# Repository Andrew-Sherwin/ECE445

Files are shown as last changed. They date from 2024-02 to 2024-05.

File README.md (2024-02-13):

# ECE445 - Senior Design Project Laboratory

# Web Page
https://courses.engr.illinois.edu/ece445/
# Official Description
Team-based design projects in various areas of electrical and computer engineering; projects are chosen by students with approval of instructor. A professionally kept lab notebook, a written report, prepared to journal publication standards, and an oral presentation required. The projects involve building and testing of the designed hardware device and a demonstration of the device is required. Course Information: 4 undergraduate hours. No graduate credit. Prerequisite: Senior Standing. Class Schedule Information: Additional Laboratory time to be arranged in 2070 ECEB.

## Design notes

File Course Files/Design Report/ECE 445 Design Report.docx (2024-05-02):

ECE 445

Senior Design Laboratory

Design Document

Automatic Humidity Sensing and Water Refilling Cool-Mist Humidifier

Team No. 11

Andrew Sherwin

(zyxie2@illinois.edu) Jalen Chen

(jalenc3@illinois.edu) Woojin Kim

(wkim51@illinois.edu)

TA: Surya Vasanth

Professor: Dr. Jonathon Schuh

February 22, 2024

## Abstract

Improper indoor humidity levels are a cause for health issues, such as dry skin or inflamed sinus passages. With the majority of humidifiers on the market being manually controlled, this causes an issue when no operator is present. A room can be under-humidified or over-humidified when there is no one to control the humidity output. As a result, we propose a cost-effective humidifier that will mitigate this problem. Concerned about the health of the operator, a cool-mist humidifier design was chosen. This humidifier communicates via 2.4GHz WIFI with multiple remote humidity sensors before determining the need to turn itself on or off. When the humidifier filter needs more water, the humidifier will activate a water valve that will irrigate the filter to the perfect amount. With all the components combined, this humidifier brings a new perspective to the humidifiers already on the market, guaranteeing the safety and comfort of the user. A truly luxurious experience.

# Introduction

## Problem and Solution

The United States Environmental Protection Agency (EPA) strongly suggests the regulation of indoor humidity to be between 30%-50%. When indoor humidity falls within these ranges, pollutants, such as chemicals, gasses, mold, and other airborne particles, are minimized in the air. This ultimately helps with allergies, respiratory illnesses, and other health issues.

To maximize the health benefits of our product, we decided to implement a cool mist humidifier. Unlike ultrasonic humidifiers and warm mist humidifiers, this product does not disperse bacterial matters, minerals, or cause your nasal passages to swell, as the US Food and Drug Administration (FDA) suggests. To further improve humidifiers on the market, our humidifier features an automatic-on function and an automatic water tank filling function. The solution has three remote humidity sensors. These sensors detect the humidity and communicate the humidity readings with the humidifier. Using the average of these readings, the humidifier decides whether it is necessary to turn itself on or off. Inside the water tank of the humidifier are two water sensors. One sensor detects whether more water is needed, while the other sensor detects when to stop automatically adding water. With all these improvements, we push out a revolutionary humidifier system onto the market that has a high level of autonomy, providing a luxurious product to the end-user.

## Visual Aid

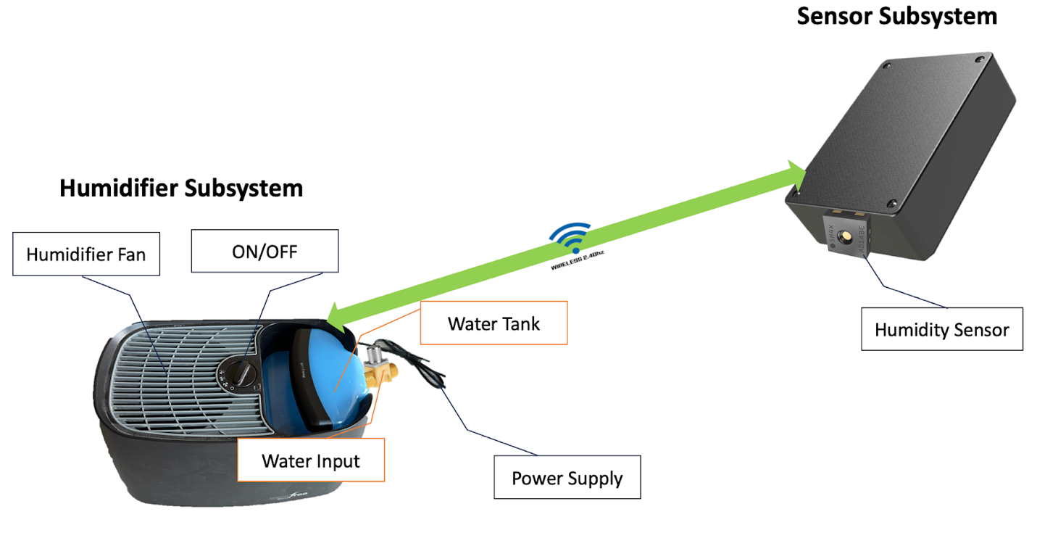
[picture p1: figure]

Figure 1: Consumer Visual Aid

The visual aid (figure 1) supports better understanding of how our product gives a solution to the suggested problem. Water supplied through water input to the tank will be brought to the filter located under the fan, then the fan will help to blow water out to the air. After the humidifier receives humidity data from the sensors, it will calculate then decide whether to turn the fan on/off.

## Physical Design

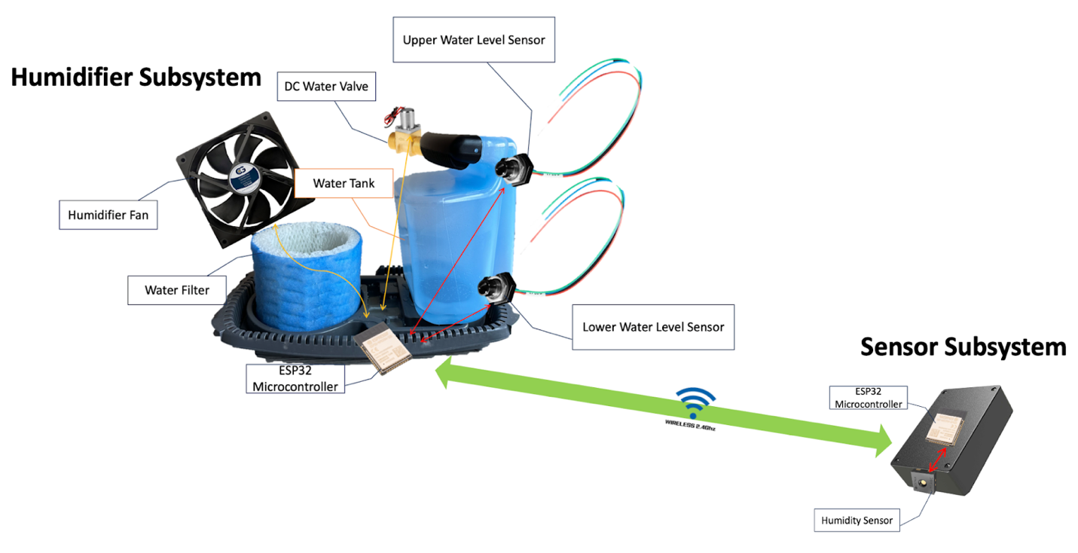
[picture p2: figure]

Figure 2 – Component Visual Aid

The physical design offers detailed information about inner components of the product. Two water-level sensors will be located vertically on the water tank to send fill/stop-fill signals to the ESP32 on the humidifier to open/close the DC water valve. It also shows the water filter that must be changed routinely to prevent potential hygiene risks. After reading humidity data, the humidity sensor will send its ESP32, then it will transmit the data to the humidifier ESP32 through 2.4GHz Wi-Fi.

## High Level Requirements

Our project would need to achieve a multitude of high-level goals to be sufficiently complete. Some goals would include:

1. The ESP32 can read data from the humidity sensor through the use. This will be done using the ESP32 microcontroller communication through the three different sensors placed around the room. The three sensors with ESP32 microcontrollers will be mounted in their individual PCBs and will communicate with the humidifier’s ESP32 microcontroller via 2.4GHz Wi-Fi with the continuous humidity readings. This will be considered as part of our total system, and the extra readings will allow us to determine the correct range at which we should turn in our humidifier fan or turn it off. This array of ESP32s will allow us to use the average humidity to detect the ideal humidity range for the fan’s on/off functionality.
2. The filter irrigation system refills the water tank with water depending on readings from two water level sensors. There will be two water level sensors, with one near the top of the tank, and one on the bottom of the tank. The bottom sensor will tell the humidifier’s ESP32 microcontroller that the tank needs to refill water. The ESP32 will activate the 12V DC water valve, allowing water to flow into the tank. Once the water hits the tip of the upper sensor, the sensor will signal the humidifier’s ESP32 to turn off the 12V DC water valve. The measured max capacity of the water tank should be 4.16 liters. The filter should absorb around 150 milliliters ± 5 milliliters. The volume of water produced, with the humidity conditions of 35% to 50% humidity, is approximately 173 milliliters per hour. This measures up to 4.16 liters every 24 hours.
3. The humidifier should be operating between 35% and 50% humidity. When the humidity falls below 35%, the humidifier will turn on. When the humidity rises above 50%, the humidifier will turn off. This is in accordance with the EPA and FDA government guidelines for indoor humidity ranges. With the remote communication between the humidity sensor’s ESP32 microcontroller and the humidifier’s ESP32 microcontroller, there is an estimated 44ns response time to the activation and the deactivation of the humidifier’s fans.

# Design

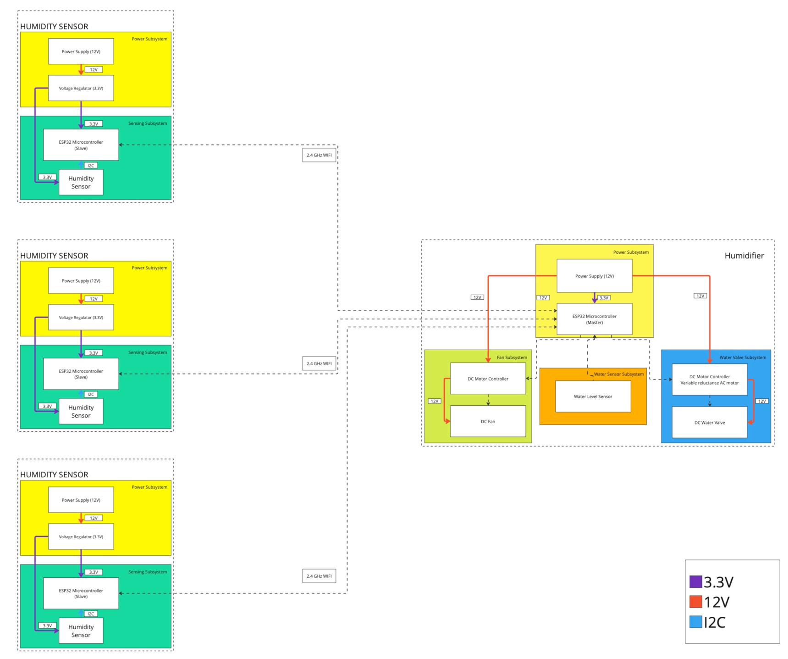
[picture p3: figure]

## Block Diagram

Figure 3 – Overall Block Diagram

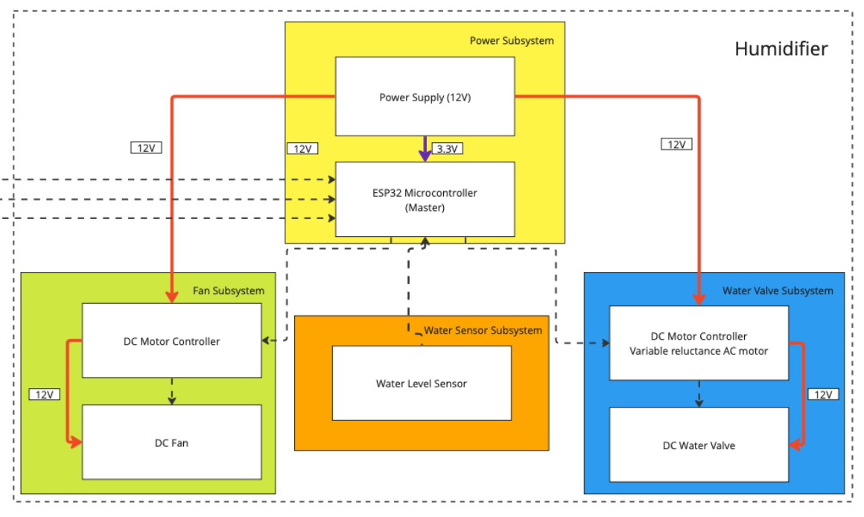
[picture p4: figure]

Figure 4 – Humidifier Subsystem Block Diagram (Close-up)

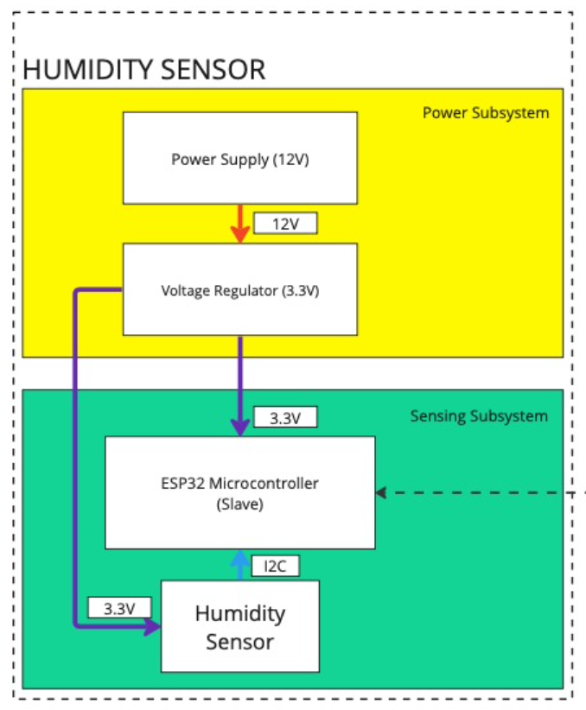
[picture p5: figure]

Figure 5 – Humidity Sensor Subsystem Block Diagram (Close-up)

Our block diagram is divided into two main parts. The Humidity Sensor subsystem and Humidifier subsystem. Within the humidifier subsystem consists of the power supply, fan, and water valve subsystems. The power supply subsystem regulates 12V input to 3.3V. This 3.3V is used to power the ESP32 microcontroller in the humidifier subsystem. The power subsystem also sends out 12V to the fan DC motor controller and the water valve DC motor controller. These DC motor controllers send 12V to their respective controlled motors. The ESP32 in the power subsystem also sends an on/off signal to the DC motor controllers. This tells the motor controllers to turn the DC motors on/off. Aside from the communication with the DC motor controllers, the humidifier subsystem’s ESP32 microcontroller also communicates via 2.4 GHz Wi-Fi with another ESP32 microcontroller in our next subsystem, the humidity sensor subsystem.

Similar to the humidifier subsystem, the humidity sensor subsystem also consists of the power subsystem. The power supply gives a 12V DC input that gets regulated to 3.3V. The 3.3V is sent to power the ESP32 in each humidifier subsystem. At every humidifier subsystem, there is a sensor subsystem. Inside the sensor subsystem are the ESP32 microcontroller and a SHT45 humidity sensor. These two devices communicate with each other in standard-mode (100kHz) I2C. Aside from communicating with the SHT45, the ESP32 also communicates with the ESP32 in the humidifier subsystem, as mentioned previously.

## Subsystem Overview / Requirements

### Humidifier Subsystem:

The humidifier subsystem controls the humidity output of the humidifier. This subsystem consists of a power subsystem that converts 110V AC to a 12V DC power. The 12V DC is sent through a voltage regulator. The output is a maintained 3.3V. This 3.3V is used to power the ESP32 microcontroller. The ESP32 microcontroller is the main microcontroller of the entire system. It communicates with the ESP32 microcontroller in the humidity sensor subsystems. In this relationship, the humidifier subsystem’s ESP32 is the master, and the humidity sensor subsystem’s ESP32s are the slaves. Based on the incoming data, the ESP32 will determine whether to turn on the humidifier’s fan or not. The motor for the fan uses 12V from the power supply and starts to rotate to run the fan. This is the main source of propulsion for our fan to produce the water into the air. When the humidifier needs more water, the ESP32 will send a signal to the water valve’s motor control system to turn on the water valve to enable the connection to the source of water, such as water pipeline at home, to fill up the 4.16-liter water tank, to wet the filter for X-seconds. This motor will be used to turn the water valve on based on the amount of water needed or shut off the flow of water once the system’s water level sensor detected liquid at the “max fill” line. The water valve’s subsystem power source will be 12 V DC coming from the barrel jack which was converted from 110V AC from the wall supply. This power was integrated throughout the whole system through 12V to the fan as well as the water valve subsystem, as both are motors that require this voltage to operate properly.

### Humidity Sensor Subsystem:

The humidity sensor subsystem detects humidity before relaying it back to the humidifier’s ESP32 microcontroller. The subsystem received power from a 110V AC to 12V DC power supply. The 12V power supply is input in a barrel jack on the PCB. The 12V is sent through a voltage regulator that maintains a 3.3V output. This 3.3V is used to power the ESP32 chip in the humidity sensor subsystem as well as the SHT45 humidity sensor. The ESP32 controls the SHT45 chip. The ESP32 in each humidity sensor subsystem serves as the master and the SHT45 is the slave. The ESP32 receives data from the SHT45 via I2C. After receiving the data, the ESP32 in the humidity sensor subsystem sends the humidity sensor’s data to the ESP32 in the humidifier subsystem. In this scenario, the ESP32 in the humidity sensor subsystem is the slave, while the ESP32 in the humidifier subsystem is the master.

### Subsystem Requirements

#### Humidifier Subsystem

i. Circuit must be powered by a 12V input source, which is then regulated at 3.3V for respective components. The microcontroller and humidity sensor takes in 3.3V. The motors will be powered by 12 V to operate at the maximum capability. We will use an oscilloscope to verify the voltage that it’s the desirable number with +/- 0.5%.
ii. ESP32 on the humidifier board must successfully receive wireless communication signals from remote ESP32 microcontrollers to obtain humidity data. Wi-Fi (2.4 GHz), electromagnetic waves travels nearly fast as speed of light, thus for 6 meters, it takes about 20 ns to reach from the humidity sensor to the humidifier, but it’s such fast compared to desirable humidifier turn on/off update frequency, the actual data transfer speed can be mitigated and only it’s enough to only verify that the humidifier receives all the data from three humidity sensors every X seconds/minutes.
iii. ESP32 should open the DC water valve when the bottom water level sensor suggests the water tank needs to be filled and close the DC water valve when the top water level sensor suggests the water level is at maximum water tank capacity. These functionalities can be verified by filling up the tank and seeing if the ESP32 on the humidifier board successfully receives signals from both sensors.
iv. ESP32 should turn on the humidifier when the average (from three sensors combined) room humidity level falls under 35% humidity and turn off the humidifier when the average room humidity level rises above 50% humidity. These functionalities can be verified if ESP32 on the humidifier board can correctly control the fan motor when it gets corresponding data from the sensor ESPs.
v. This subsystem will contribute to the overall design dictated by the high-level requirements by acting as the central subsystem that will control the main microcontroller, along with the 12V motors that drive the water supply valve and the water evaporation fan. Then the readings from the humidity sensor subsystem will communicate through 2.4 GHz Wi-Fi to our main microcontroller to tell the fan to turn on or not based on an ideal range of between 35% and 50% humidity as mentioned in the requirements. Then the microcontroller will send the data to moisture the air, with approximately 83 mililiters per hour. The water sensor will also control our water filling of up to 4.16 liters to communicate to the microcontroller whether we have reached max capacity or not.

#### RV-Table – Humidifier Subsystem

Requirements | Verification
- Provide 3.3V +/- 0.5% from an input voltage of 12V +/- 0.10% DC source - Thermal stability maintains below 120’C | - Use multimeter to test and take average voltage output over 1-hour to test stability - Monitor heat dissipation with thermal laser gun over an average of 1-hour use time, expected +/- 5’C under load
- ESP32 communication with remote sensor ESP32 utilizing 2.4GHz Wi-Fi | - Verify functionality of ESP32 Wi-Fi component by creating an access point, and accessing access point to remotely turn on LED lights - Verify communication between two ESP32 boards by sending command to turn on LED light from one ESP32 board - Verify thermal performance of ESP32 chip during operation by probing with a laser thermal gun
- ESP32 control of activation and deactivation of water valve - ESP32 control of activation and deactivation of fan | - Verify functionality of ESP32 communication with DC motor controls by sending activation signal to water valve/fan DC motor controller, and when signal is received, DC motor controllers output a lit LED light - Probe the output voltage of the DC motor controllers to make sure it is 12V +/- 0.5%
- ESP32 detects signals from two water-level sensors | - Contact/No Contact water to the water-level sensors and check through Arduino IDE to see if ESP32 receives contact/no contact signal from the two water-level sensors - Water level sensor lights up LED when in contact with water, and LED is not lit when not in contact with water

#### Humidity Sensor Subsystem

i. Circuit must be powered by a 12V input source, which is then regulated at 3.3V for respective components. We will use an oscilloscope to verify the voltage that it’s the desirable number with +/- 0.5%.
ii. ESP32 board should be able to communicate with SHT45 humidity sensor with I2C. Communication between the humidity sensor and the ESP32 on the same PCB through I2C is fast enough compared to how frequently the humidity sensor measures the humidity, which varies from 1.3 to 8.3 ms depending on the noise and energy consumption. It’s enough to verify that the ESP32 in the humidity sensor receives all the data from its sensor every X seconds/minutes.
iii. ESP32 board should be able to communicate with ESP32 in humidifier, relaying the SHT45’s data to it.
iv. ESP 32 will communicate with the humidity sensor as same frequency.
v. These functionalities can be verified by giving different humidity conditions to the humidity sensor.
vi. This subsystem will be connected to the overall design through measuring the correct humidity in a certain area, and with 3 different humidity sensors, there would be a range that is created that the central microcontroller would read because the data is being sent from each individual microcontroller per sensor through Wi-Fi, with an expected response time of 44ns through communication of the I2C protocol.

#### RV-Table – Humidity Sensor Subsystem

Requirements | Verification
- Provide 3.3V +/- 0.5% from an input voltage of 12V +/- 0.10% DC source - Thermal stability maintains below 120’C | - Use multimeter to test and take average voltage output over 1-hour to test stability - Monitor heat dissipation with thermal laser gun over an average of 1-hour use time, expected +/- 5’C under load
- ESP32 communication with humidity sensor receiving humidity data at least once in a minute - Humidity sensor measuring humidity data at least between 25% - 55% | - Verify communication between ESP32 and humidity sensor Arduino IDE by checking humidity data ESP32 receives - Compare the humidity data received by ESP32 to the commercial humidity sensor and check if the humidity is within +/- 3% - Make the air dry/moist to see if the sensor can measure humidity between 25% - 55% - Compare humidity reading with reference humidity reader

### Tolerance Analysis / Potential Error

A significant aspect of our design that could pose a major risk to our project is the strength in the Wi-Fi signals being used to communicate between the sensors. Our project majorly depends on multiple microcontrollers in multiple sensors across many different areas in a room using Wi-Fi to connect to the central microcontroller. If any of these signals were interrupted, it would cause an impactful change in the way our system functions. Our completion of the project would be deemed nearly impossible without a proper wireless communication protocol, whether it be Bluetooth or Wi-Fi. For example, Wi-Fi is essentially a EM wave that operates through the medium of air containing the data we need, and can be more accurately defined using sets of Maxwell’s equations, most notably the Helmholtz equation that gives us the equation:

E∇^2 +(E(k^2 ))/(n^2)=0

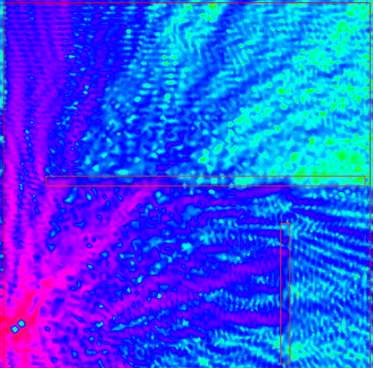
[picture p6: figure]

which are the electric fields mapped based on the angular wavenumber k and the material index n (Hecht). Below is a sample model taken from a reference site, Freefem, that will model what the signals will look like at a certain point in the area.

Figure 6: Signal Strength Plot

In figure 6, it shows a point where the electromagnetic signal is being read and the relative strength of it compared to the waves across the rest of the room. This will be how our sensors operate, with the signals being the strongest at receiving/interacting ends and having the most possible interference in between transmissions. In our respective setup, we will use example calculations to model this. For example, wavelengths of our WiFi signals which will be used to communicate are approximately 12 centimeters give or take, given a 2.4 GHz WiFi default in our system. So the angular wavenumber:

k= 2π/λ

which given our lambda wavelength value, will give us 0.52 (rad)/(cm) . As for material index n, the value should just be the material index of air, which is the constant of 1. Given this, we have taken E as an average of 50 V/m for an electric field value inside a home. So our electric field gradient value will be equal to:

50× 0.52^2 =13.52 v/(m^3)

This value will indicate the electric field strength in a specific area, which matches our signal strength plot example above. The field will obviously be different at random areas in the room due to interference from various radio sources, such as other electronics or even your own body as a source. To mitigate this issue, we will test if signals are possible to fully transmit all necessary data given multiple sensor points. If information is not fully available because of the strength or interference of other signals, we will act to measure where exactly the field is weak and create optimal positions for our sensors to generate the most effective waves. Another solution to this problem could be examining the materials that have interference potential such as metal or concrete, and either removing or replacing those materials in highly affected areas. Trade-offs to our solutions would be that optimal positions for signal strength might not be optimal positions for humidifier strength. For example, if our sensors were positioned at 30, 45 and 180 degrees in a circular pattern in a rectangular room, there would be nearly no sensing of the humidity in the 270 degrees area. This would be sub-optimal because we would essentially have 2 sensors instead of 3 near evenly spaced ones, despite the connection being very reliable.

# Cost and Schedule

## Cost Analysis

### Parts and Materials

In our project, we have an estimated breakdown of the parts and materials needed in our final product. The part name, part number, number required per system, and the cost per system is provided. Each system consists of one humidifier subsystem, as well as three humidity sensor subsystems.

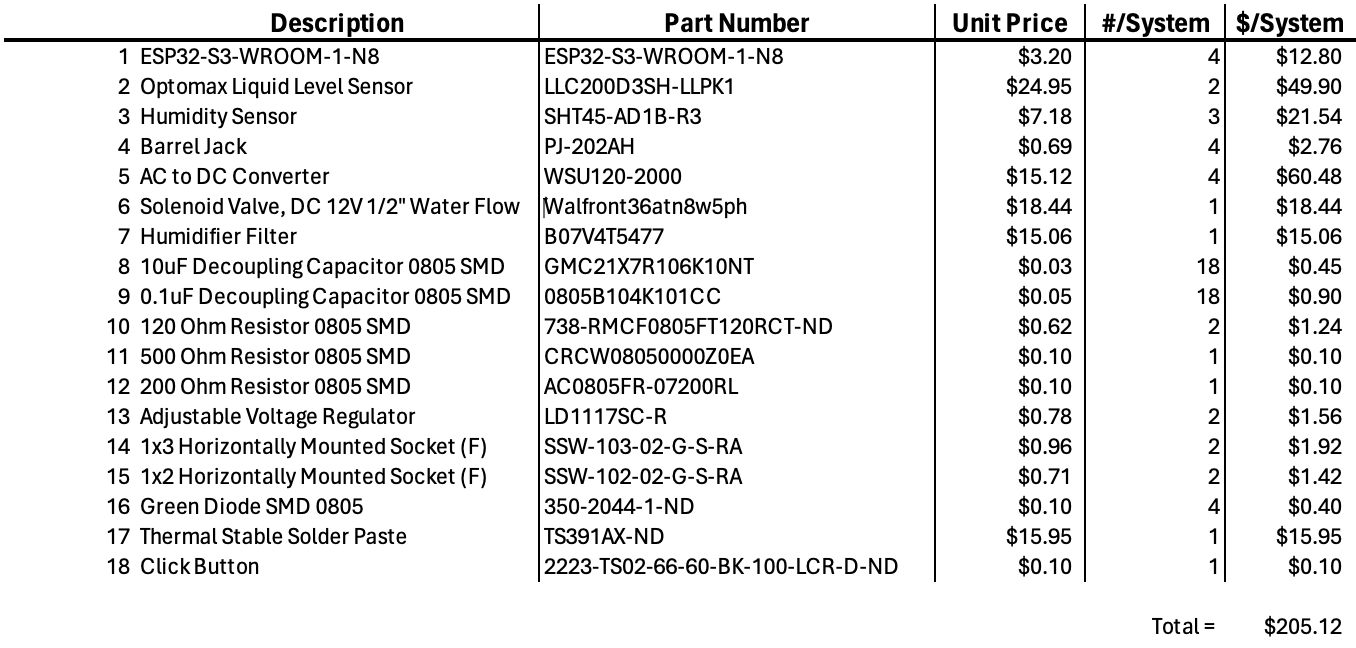
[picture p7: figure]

Table 1 – Estimated Product Cost

#### Hours of Development and Labor

Our project consists of multiple roles that need to be completed. We have an estimated 373.5 hours total between three group members on the project. Below is a breakdown of our estimated hours per person on each category.

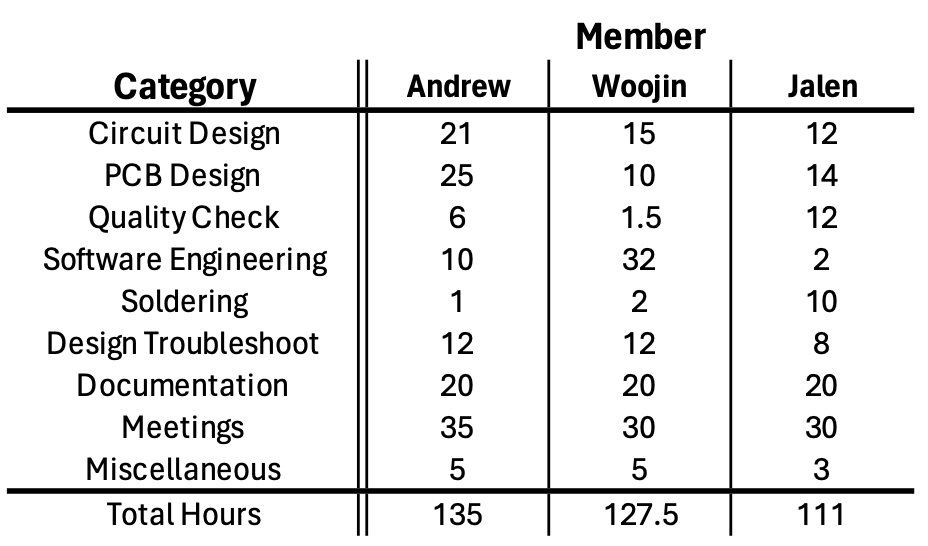
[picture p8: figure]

Table 2 – Estimated Hours

With mixed electrical engineers and computer engineers in our group, we all have different hourly wages. Using the average UIUC ECE computer engineering published salary in 2021-2022 ($109,176.00), using 2080 work hours in a work year, we can expect an average hourly salary of $52.49.

($109,176.00)/(2080 hours)=$52.49 per hour

(135hours+127.5hours+111hours)× $52.49=$19,605.02

Summing up the total hours in the table above and multiplying it by the average salary, we get the total cost for labor to be: $19,605.02 for this project.

Aside from our own hours of labor, the machine shop estimates 7 hours of work to modify our humidifier with some parts included in Table 1. The machine-shop technician’s hourly cost is not public, so we will not include the cost in the total cost of development above.

## Schedule

1. Week 6 (02/19)
  a. Design Document
  b. Proposal Revision
  c. I2C communication between ESP32 and Humidifier
  d. 2.4GHz Wi-Fi communication between two ESP32 boards
  e. Give humidifier to machine shop
  f. Begin PCB Design for humidity sensor subsystem
2. Week 7 (02/26)
  a. Design PCB for humidity sensor subsystem
  b. Debug potential issues with PCB
  c. Interface water-level sensor with humidifier ESP32
  d. Control 12V DC water valve with ESP32
  e. Control humidifier fan with ESP32
  f. Potentially place first PCB order (individual)
3. Week 8 (03/04)
  a. Order PCB for humidity sensor subsystem (with class)
  b. Order electronic water valve
  c. Order second Adafruit water level sensor
  d. Design PCB for humidifier subsystem
  e. Debug potential issues with PCB
  f. Potentially send humidity sensor subsystem PCB to machine shop
  g. Potentially solder SMD components on humidity sensor PCB
4. Week 9 (03/11)
  a. Finish humidifier subsystem PCB design
5. Week 10 (03/18)
  a. Solder PCB for humidity sensor PCB
  b. Send humidity sensor PCB to machine shop
  c. Order PCB for humidifier
6. Week 11 (03/25)
  a. Reorder revised PCBs
  b. Solder PCB for humidifier subsystem
  c. Potentially put together humidifier
7. Week 12 (04/01)
  a. Begin writing final paper
  b. Finalize PCBs
  c. Send remaining updates to machine shop
8. Week 13 (04/08)
  a. Finalize product for presentation
  b. Begin writing final paper
  c. Last minute debugging
9. Week 14 (04/15)
  a. Team contract fulfillment
  b. Mock demonstration
  c. Finalize product for presentation
  d. Continue writing final paper
10. Week 15 (04/22)
  a. Final Demonstration
  b. Mock Presentation
  c. Final Presentation Preparation
  d. Continue writing final paper
11. Week 16 (04/29)
  a. Final Presentation Preparation
  b. Final Presentation
  c. Final Papers
  d. Lab Notebook
  e. Lab Checkout

# Ethics and Safety

For our initial examination of ethics, we were able to justify our project using the IEEE code of ethics. As students and soon-to-be workers, we know that whatever we do will have an impact on the world, primarily through the products and services we work on. Therefore, we must make sure to set some ethical guidelines that match with the code.

## Ethics

i. To uphold the highest standards of integrity, responsible behavior, and ethical conduct in professional activities. (IEEE, 2020)

a. We will keep an open-minded state to each other's opinions. Utilizing everyone’s opinions, we will try to find the most ideal solution to our problems.

b. We will keep the integrity of our research to the highest degree. All data collected will be the truthful original and will not be “tuned” in any way.

c. We will keep the safety of our members and those working around us to the utmost highest standard.

d. We will adhere to the rules and regulations of the University of Illinois and ECE445’s lab conduct rules.

e. Constructive advice and criticisms will be accepted, and any forms of bribery will not be tolerated.

ii. To treat all persons fairly and with respect, to not engage in harassment or discrimination, and to avoid injuring others. (IEEE, 2020)

a. We will treat all members within and outside our group with respect on physical and non-physical standpoints.

b. Sexual harassment is not tolerated and will be reported to appropriate parties.

iii. To strive to ensure this code is upheld by colleagues and co-workers. (IEEE, 2020)

a. We will strive to uphold this code of conduct provided from IEEE and in our team contract. Any behavior outside the rules will be reported to the correct authorities.

iv. To seek, accept, and offer honest criticism of technical work, to acknowledge and correct errors, to be honest and realistic in stating claims or estimates based on available data … (IEEE, 2020)

a. A central ethical concern includes directly impacting humans as a first resort without being able to test otherwise. For example, for most scientific products, humans are the final stage of a trial in a product because all previous stages have been cleared or given approval through uses of inanimate objects or lab animals. Our problem is generally a comfort-based one, and so the general ethical concern would be the first stage exposure to humans since there would not be a test trial. If our main issue is comfort, we will never know how it feels until actual humans have tested it. Therefore, as one of the IEEE Code of Ethics indicates, we will seek and accept any technical criticisms from TA, instructors, and machine shop, be realistic and responsible to revise the problem until we reach agreement. On top of that we will measure the humidity carefully and regulate with the correct amounts of moisture, making sure that we only deviate from the average quantity only once we have received indication that it is comfortable.

## Safety

In this section, we consider every type of the most common situations that could occur when using our automatic humidifier product.

  i. A safety concern would be the wall plug power. This is 120 V AC power typically, and so to prevent electrocution and shock issues, we would need to be aware of our surroundings and to connect the plug into the wall without any external connections to the outlet interrupting it in any way, such as holding loose wires or the metal section of the plug when you are plugging it into the wall.
  ii. A safety concern is the issue of potential bacteria and mold. Our automatic humidifier should get rid of this, but this issue could severely impact the humidifier if there turns out to be traces of something contagious that can be widespread with the device. The dangers of something airborne that could get into your lungs would be catastrophic if not regulated correctly.
  iii. Another possible safety issue could be the moving parts of a fan that could injure you if you try to touch the mechanical components. The fan’s motor will likely be insulated from external touch, but there is always a chance that something breaks and another chance that the moving part accidentally comes in contact with someone’s finger or something easily mistouched, leading to a higher chance of injury.
  iv. A common matter that arises as well is if there is a connected cable that meets water. Our humidifier will likely be powered through a wired connection, and any water that comes into contact either from the humidifier or an external water source will damage the system, or even worse, cause physical harm to someone. This safety issue would need to be fixed through epoxy or some type of non-porous material insulating the device and its connections.
v. Dangerous chemicals are a final hazard that could be caused intentionally or by accident. Chemicals could be an issue if put inside the supply which normally contains water. If a dangerous fluid was put in the supply on purpose, then the humidifier might act as normal, sensing the humidity levels and then dispersing a life-threatening liquid instead of water. This would cause great harm and even possibly death if misused, so it is of utmost importance that the person using the device is careful and is sensible. Otherwise, the designers are not subject to responsibility and take no claim in the misuse of the product, which in that case, the user should refer to the instructions provided.

# References

[1] Hecht, F. (n.d.). WiFi Propagation . WIFI propagation. https://doc.freefem.org/tutorials/wifiPropagation.html
[2] Marwell, M. (2018, August 9). Issues with the I²C (inter-ic) bus and how to solve them. DigiKey. https://www.digikey.com/en/articles/issues-with-the-i2c-bus-and-how-to-solve-them
[3] Sensirion. (2023). SHT4x 4th Generation, High-Accuracy, Ultra-Low-Power, 16-bit Relative Humidity and Temperature Sensor. In Sensirion Official Documentation (Issue 6). Sensirion.
[4] United States Environmental Protection Agency. (2014, August 28). Care for your air: A guide to indoor air quality. US EPA. https://www.epa.gov/indoor-air-quality-iaq/care-your-air-guide-indoor-air-quality
[5] Espressif. (2023). ESP32-S3-WROOM-1 ESP32-S3-WROOM-1U Datasheet. Espressif. https://www.espressif.com/sites/default/files/documentation/esp32-s3-wroom-1_wroom-1u_datasheet_en.pdf
[6] Metageek. (2024). Wi-Fi and non wi-fi interference. MetaGeek. https://www.metageek.com/training/resources/wifi-and-non-wifi-interference/
[7] Arundel, A. V., Sterling, E. M., Biggin, J. H., & Sterling, T. D. (1986). Indirect health effects of relative humidity in indoor environments. Environmental Health Perspectives, 65, 351–361. https://doi.org/10.1289/ehp.8665351
[8] Perrone, V., Veronesi, C., Giacomini, E., Citraro, R., Dell’Orco, S., Lena, F., Paciello, A., Resta, A. M., Nica, M., Ritrovato, D., & Degli Esposti, L. (2022). The epidemiology, treatment patterns and economic burden of different phenotypes of multiple sclerosis in Italy: Relapsing-Remitting multiple sclerosis and secondary progressive multiple sclerosis. Clinical Epidemiology, 14, 1327–1337. https://doi.org/10.2147/CLEP.S376005
[9] IEEE. (2020). IEEE code of ethics. IEEE Code of Ethics. https://www.ieee.org/about/corporate/governance/p7-8.html
[10] SENSIRION. (2023, January). 4th Generation, High-Accuracy, Ultra-Low-Power, 16-bit Relative Humidity and Temperature Sensor. Cdn-Shop.Adafruit.Com. https://cdn-shop.adafruit.com/product-files/5665/5665_Datasheet_SHT4x.pdf
[11] University of Illinois. (2022). Salary averages. UIUC. https://ece.illinois.edu/admissions/why-ece/salary-averages

2 Automatic Humidity Sensing and Water Refilling Cool-Mist Humidifier

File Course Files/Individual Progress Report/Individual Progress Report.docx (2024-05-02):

ECE 445

Senior Design Laboratory

Individual Progress Report

Automatic Humidity Sensing and Water Refilling Cool-Mist Humidifier

Team No. 11

Andrew Sherwin

(zyxie2@illinois.edu)

TA: Surya Vasanth

Professor: Dr. Jonathon Schuh

March 27, 2024

# Abstract

This paper is an individual progress report for the work done by Andrew Sherwin as an individual in ECE445 – Senior Design Laboratory. Andrew Sherwin is the active member and the team manager in Team 11. The team consists of members: Andrew Sherwin, Woojin Kim, and Jalen Chen. In Spring 2024, Team 11 is designing an Automatic Humidity Sensing and Water Refilling Cool-Mist Humidifier. The humidifier can turn on automatically in relation to the detected humidity and temperature values, as well as refill its water tank depending on the water level value. Andrew Sherwin is responsible for the team’s project progression, as well as maintaining a checklist all goals are reached at an appropriate time. He is also responsible for the selection of components and design of the PCB. Aside from that, he also helps with the software design for the control of the microcontroller. Andrew Sherwin is also the representative for the team during communication with the course staff, Surya Vasanth, and the machine shop.

# Introduction

## Problem

In September 203, the United States Environmental Protection Agency (EPA) [1] released an article regarding indoor humidity recommendations. The EPA suggests indoor humidity to range between 30 and 50 percent. Though a lower humidity decreases the presence of pests, such as mites, it allows for airborne particles and pollutants to freely travel around. A higher humidity above 50 percent leads to a higher percentage of mold growth. As a result, it is critical to keep indoor humidity between 30 to 50 percent, at room temperature.

The majority of cost effect humidifiers in the market are manually controlled. They do not feature an automatic on-off feature. When the humidifier user is not at home, the indoor humidity can pass 50% humidity when the humidifier is left on. Similarly, the indoor humidity can drop below 30% when the humidifier is left off. In addition, all humidifiers in the market require manual water filling by the user. Our humidifier strives to solve the issues above to guarantee safe and healthy indoor humidity for the user.

## Solution

To resolve the issue of a manual humidifier, our design proposes a solution that can be incorporated into the majority of manual consumer humidifiers on the market. We will have a system that has three remote humidity sensors that relay humidity data to the base system at the humidifier. The humidifier will plug into the base system, and the base system will plug into the wall. Based on the humidity sensor readings, the base system will use an in-house developed algorithm to turn on or off the humidifier. Furthermore, the humidifier’s water tank will be connected to a DC water valve. Depending on the water level sensor’s readings, the base system will activate or deactivate the water valve to refill the humidifier’s water tank. The laissez-faire approach to our humidifier’s function generates a luxurious and revolutionary product for the market with high autonomy.

## Team Responsibilities (non-design)

Andrew Sherwin is responsible for managing the team and giving the team a direction in design philosophy and written reports. Andrew is also responsible for the communication between the team and the course staff, as well as the machine shop. Andrew has set out specific goals to be accomplished each week in the 16-week semester. Every week, Andrew actively communicates with the team members in-person and on the private Discord server about goals and requirements to be met at the end of the week. While Andrew participates in the written reports, he also proofreads and formats the written reports for the course. Andrew leads the team on the weekly meetings with the TA, Surya Vasanth, and updates the Machine Shop bi-monthly about the team’s project progression.

## Sensor Subsystem Responsibility

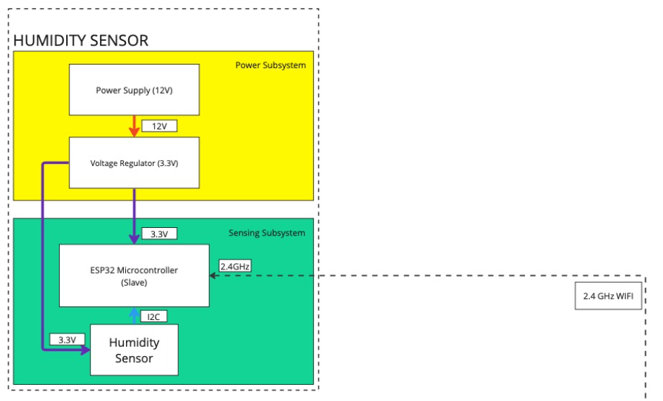
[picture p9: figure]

In figure 1, the sensor subsystem, Andrew Sherwin was responsible for choosing the components and designing the PCB for the subsystem. Andrew has been cooperating with Woojin in the software design of the humidity sensor subsystem. The ESP32 has to read the data of the humidity sensor and relay it to the ESP32 at the base system in the humidifier subsystem. In the hardware design, Andrew has been picking components suitable for this subsystem, while communicating with Jalen regarding the power subsystem in figure 1. With his prior experience in PCB design, Andrew is also responsible for drawing the schematic and PCB layout in KiCAD, whilst Jalen proofreads the system design.

Figure 1 – Sensor Subsystem Block Diagram

## Humidifier Subsystem Responsibility

Similar to the sensor subsystem’s responsibilities, Andrew has been working with Woojin on the software of the ESP32. Andrew developed a software design for an access point that Woojin uses for the ESP32 communication. Andrew has also developed a program where LED lights can be controlled using a phone on the ESP32’s MAC address. The webserver also shows a live readout of the LED values. On the hardware side, Andrew has been working on picking components suitable for the humidifier subsystem in figure 2. For example, Andrew selected the water level sensors, electrical relays, and numerous other parts for this subsystem. Similar to the sensor subsystem, Andrew also designed the PCB schematic and layout of the humidifier subsystem. Jalen has worked with Andrew by discussing on the choice of parts and proofreading the KiCAD schematic.

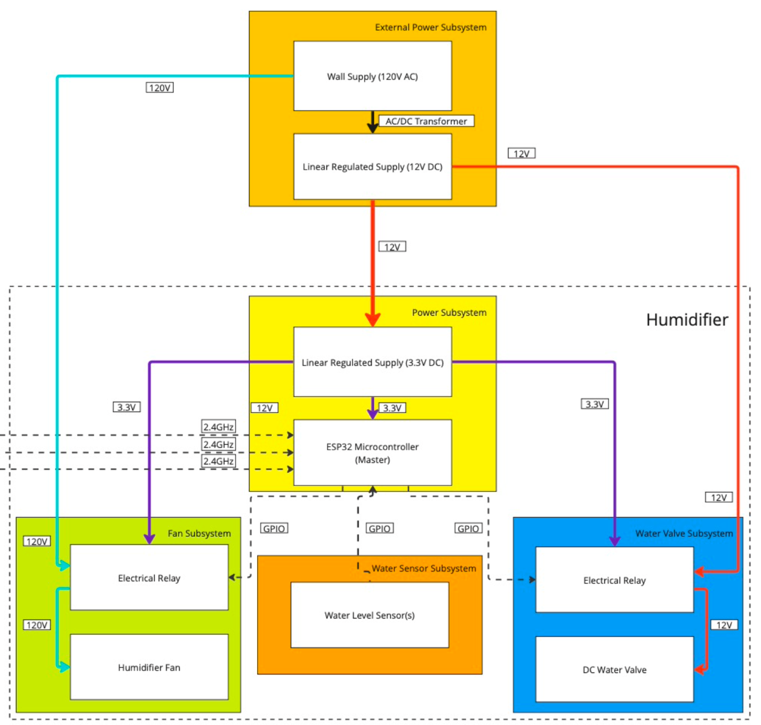
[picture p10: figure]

Figure 2 – Humidifier Subsystem Block Diagram

# Individual Design

## ESP32 Design

In the development phase, we used an ESP32-S3 WROOM1 development board. This board uses Micro-USB Type-B ports to upload the programs to the microcontroller. The Micro-USB sends UART data to a UART communication chip, U4 in figure 3, to communicate with the ESP32. When programming, the BOOT button had to have a logic of 0 to load the button, hence the importance of the BOOT button. The RESET button loads and starts the program in the microcontroller. It is important to replicate these parts of the development board’s design in our PCB design, as they are critical for the functionality of the microcontroller. It is also important to have Zener diodes to act as reference voltages and to prevent static discharges from affecting other components. We also have some 0-ohm resistors for testing. The design also includes an alternative way to program the board, using just the Micro-USB. This is a secondary way just in case if the USB to UART bridge does not work. The completed schematic, with the humidity sensor can be seen in figure 3.

Figure 3 – Sensor Subsystem Schematic

## Sensor Subsystem Progress

Figure 3 shows the KiCAD design for the sensor subsystem designed by Andrew Sherwin. Most of the diagram consists of the ESP32 circuit, with pins 12 and 17 being the input of the SHT45 humidity sensor (U3). The SHT45 communicates in I2C, which means it needs SDA and SCL pins. The SHT45 has a 100nF decoupling capacitor, as specified by the Sensirion documentation, as well as one 10k ohm resistor for SDA and SCL respectively. The SHT45 sensor will be mounted on the rear of the PCB, with the ESP32 and all other components being on the front. This will isolate the humidity sensor, thus, making the readings more accurate.

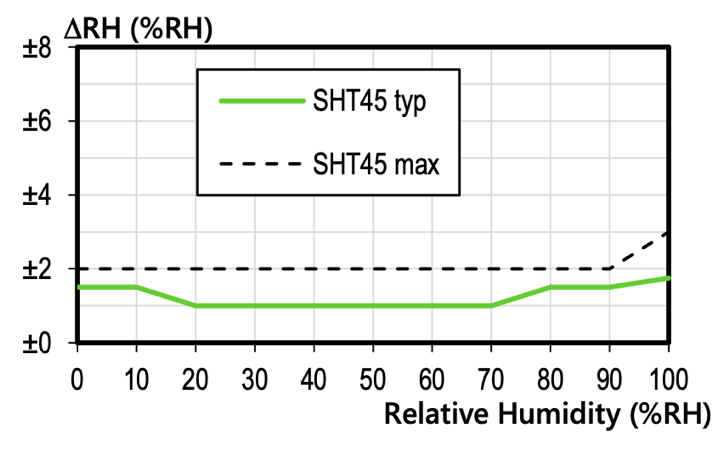
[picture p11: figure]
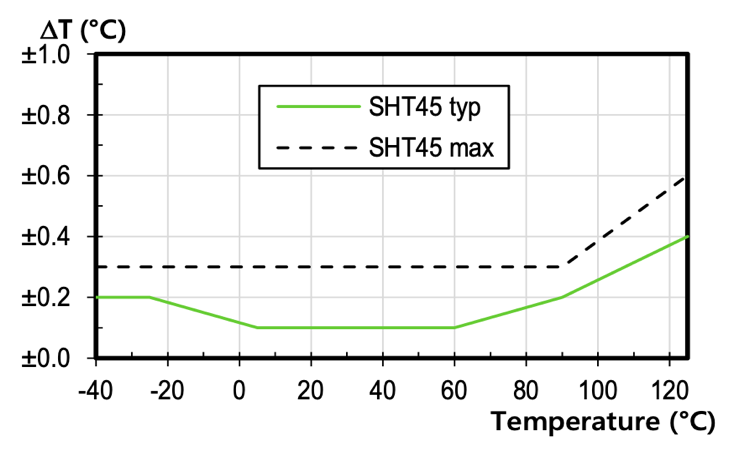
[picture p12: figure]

The SHT45 was determined to be used due to its accurate temperature and humidity measurements. Whereas most other sensing devices has an error range or 2%, the SHT45 has only an error range of 1% in the indoor temperature range around 23ºC, as seen in figure 4.

Figure 4 – SHT45 Reading Accuracy Table

## Humidifier Subsystem Progress

Originally, we planned the ESP32 microcontroller in the humidifier subsystem to be communicating with two motor controllers. The first which controls the DC water valve, and the other that controls the humidifier fan.

As the machine shop is not creating a ground-up humidifier for the team, taking apart and controlling the humidifier’s fan proved difficult. As a result, the alternative solution was to control the humidifier with a relay. The relay will work like a light switch that is controlled by the ESP32. The switch will allow 120V AC to reach the humidifier. A sample diagram is shown in figure 5 below.

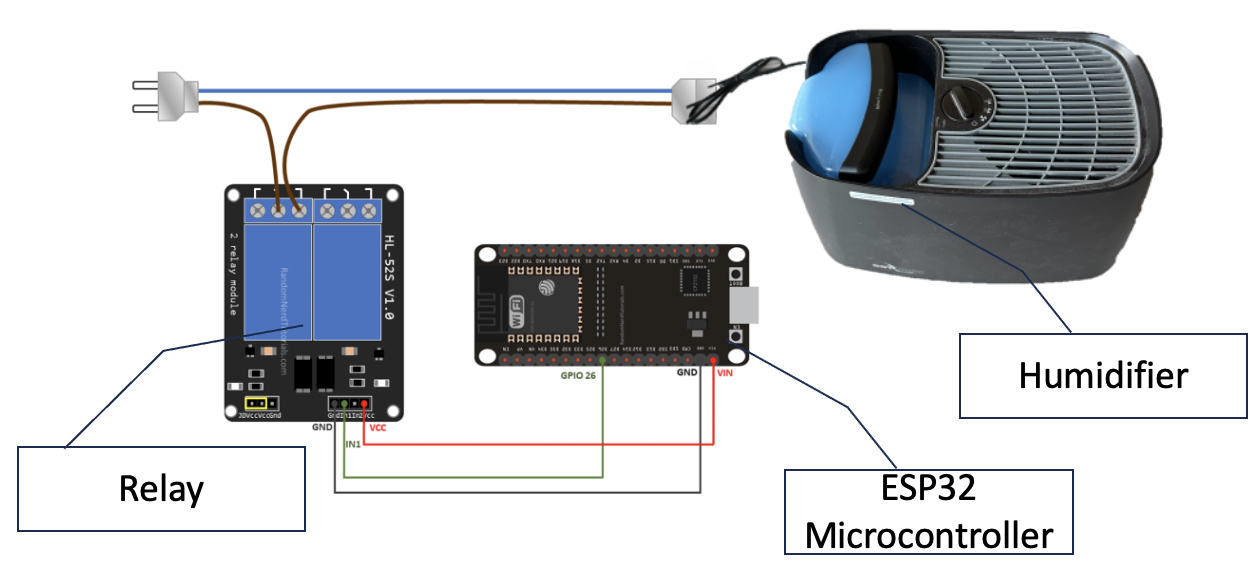
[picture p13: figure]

Figure 5 – Relay Diagram

Similarly, it was discovered that the original water valve that the team intended to use did not work unless there was active pressure on it. This will normally work when connected to a building’s water supply. However, for our demonstration, there will be no water pressure. As a result, we had to change parts. The pervious water valve featured a stepper motor. This required a motor controller. However, the new one features only a simple DC motor, which did not require a DC motor. As a result, we can simply use another relay to control the water valve, with a setup like that of figure 5.

When designing the schematic in figure 6, most of the schematic was a carry-over from the ESP32 schematic. The main difference in figure 6 was the inclusion of the two relays. A design choice was made during the design of the relay schematic to include a kick-back diode and an optocoupler. The kick-back diode helps prevent voltage spikes from going to the ESP32 when the circuit is turned off. The optocoupler helps isolate the ESP32 from the higher voltage components in the relay. This further prevents noise and voltage spikes from destroying the ESP32.

Figure 6 – Sensor Subsystem Schematic

# Individual Verification

## ESP32 Progress

Andrew was the first team member to work on the ESP32. He set up the Arduino IDE and installed the necessary libraries for programming the ESP32. The first basic test that Andrew did was turning LED lights on and off. Through a button input to a GPIO pin, depending on the logical input, the ESP32 will match the input signal to another output GPIO with an LED. For example, then the button is pressed, the LED will turn on, and the opposite vice-versa.

After confirming the functionality of the setup, Andrew worked on setting up an access point for the ESP32. He planned to connect to it with his personal device. On this access point, after accessing the MAC address on the personal device, he created a HTML code that shows the live output of the LED mentioned in the previous paragraph. When the LED is on, the webpage will display “ON”, and “OFF” when the LED is off. This will be the starting point of being able to read the humidity sensor data on a personal device, which the team plans to accomplish later as a bonus.

## Sensor Subsystem Progress

Coupled with the ESP32 progress, Andrew has aided Woojin in the verification of the software development in the sensor subsystem. Andrew helped troubleshoot the code in the Arduino IDE for the SHT45 humidity sensor using modular and system testing methods. Originally, the ESP32 was not getting an input from the SHT45. The troubleshooting method was to first probe the ESP32’s SDA output and the ESP32’s SCL clock speed. Using an oscilloscope, Andrew verified that the output message was correct for the ESP32’s master instructions. Following, the oscilloscope was used again to probe the clock speed. The error was simple, the clock speed was incorrect. The ESP32 was using I2C at the “Fast-Mode”, transferring data at 400k bits/s, while the SHT45 was supposed to be reading and sending data at 100k bits/s. The SHT45 was not able to receive the ESP32’s instructions, due to the ESP32 sending data at a 4 times higher frequency than the SHT45 was reading.

Verification of the PCB that was placed on the first round will be done when the part for the PCB arrives. The PCB has test-point pads that provides easy access for probing signals with an oscilloscope. This was done during the design process. On the final PCB, the test-points will be removed so that the final product will be cleaned up.

## Humidifier Subsystem Progress

In the humidifier subsystem schematic and PCB design, 1x1 connectors are included for trouble shooting. The 1x1 connectors will make it easy to probe the oscilloscope on the section. Furthermore, there are numerous 0-ohm resistors throughout the schematic and PCB. The reason for these resistors is so that jumper wires can be soldered for testing if the original traces were not correct. This is highly suggested for the UART TX and RX connections. The use of the 0-ohm resistor pads can be seen in figure 6.

The new 12V DC water valve operates as a plunger. When it receives 12V power, there will be 0.48A of current going through the water valve solenoid. This results in a magnetic field, which pulls the plunger up, allowing water to pass through the valve. Andrew did some modular tests on the percentage chance the valve will activate at the lower voltage. Based on 100 trials for each 0.2V increment from 10V, it can be concluded that there is 0% chance that the valve will operate in the range 0V to 11.4V. There is a 39% chance of the valve activating at 11.6V, 94% chance at 11.8V, and 100% chance at voltages 11.9V and greater. The with 1100 trials performed, and 1100 data collected, Andrew is confident that as long as the relay supplies 12V, with a 0.2V error range, the valve will function for our design. Through this verification, and by disassembling the valve to understand the inner workings, Andrew brought up the suggestion to use a valve rated for a higher pressure should be considered for the project, as this valve does not rely on input pressure. This will guarantee a better water seal within the valve.

The PCB testing will be similar to the process mentioned in the Sensor Subsystem Progress Verification section. Currently, the PCB has not arrived yet, but there are test-points for probing the PCB, if needed, with an oscilloscope to decipher the signals. The testing will be done within 3 days of the completion of the component soldering onto the PCB. This will allow the team to place a new PCB order if needed for revisions.

# Conclusion

## Self-Assessment

The workload for Andrew Sherwin in ECE445 is a bit higher than his peers in his team. This is expected as he is managing the direction of the project and is the representative for the team.

Andrew communicates in-person and on Discord with the team to get updates and progress on the project. He makes sure that all goals are met on time, or ahead of time. If there are any issues with parts, he quickly organizes meetings and finds solutions for troubleshooting. As the representative of the team, Andrew communicates with the TA, Surya Vasanth, and the machine shop regarding project updates and parts to order. Each week, Andrew sets out new goals and plans for the team to meet, in accordance with the set schedule. Andrew makes sure that each milestone is met at, or ahead of a certain date.

As the bridge between the software engineer, Woojin, and the hardware-power engineer, Jalen, Andrew is involved in both parts of the project. With his prior experience, he also is the designer for the PCB schematic and layout. He helps both members troubleshoot potential issues and helps clarify unclear project goals.

With Andrew’s planning, the team is currently ahead of schedule. During the first round of PCB orders, Andrew placed an order for the Sensor Subsystem’s PCB. During the second round of PCB orders, Andrew placed an order for the Humidifier Subsystem’s PCB. On the week of the third round of PCB orders, with the help of Andrew’s original ESP32 research, Woojin has updated the team that he is able to send and receive humidity data from one ESP32 to another ESP32 using 2.4GHz Wi-Fi. With the above finished, the team is 2 weeks ahead of the original conservative time schedule.

## Future Plans

Currently, the team is waiting on parts from Digikey, so that the PCBs can receive their components. Jalen will be soldering the PCB with the later arriving components, and Andrew will be working with Woojin on programming and troubleshooting any potential errors from the PCBs.

Andrew will also be working with Jalen on the wiring of the humidity subsystem. The team will need to purchase a 120V AC to 12V DC transformer assembly. Currently, Andrew has his sights set on the Mean Well USA EPS-15-12 AC/DC converter. This will output a 12V DC line that will go to power the PCB via a barrel jack connector.

If the PCBs do not need revisions, the team will work on a webpage to view the live humidity sensor readings from the SHT45 sensors. This will be a bonus to our project if everything is completed early. However, this plan will only commence if the original design is indeed functional.

As a team, Team 11 will continue to follow all IEEE Code of Ethics outlined in section 7.8. We will uphold the highest integrity and responsible behavior when designing our product. Working as a team, we will treat one another with respect, and will not engage in any form of discrimination. We will strive to uphold the IEEE Code of Ethics throughout the period working on the Automatic Humidity Sensing and Water Refilling Cool-Mist Humidifier.

# References

[1] Environmental Protection Agency, “Care for your air: A guide to indoor air quality,” US EPA, Aug. 07, 2023. https://www.epa.gov/indoor-air-quality-iaq/care-your-air-guide-indoor-air-quality (accessed Mar. 25, 2024).

[2] Sensirion, “Datasheet -SHT4x,” Sensirion, Aug. 2023. https://sensirion.com/media/documents/33FD6951/6555C40E/Sensirion_Datasheet_SHT4x.pdf (accessed Mar. 26, 2024).

[3] A. Sherwin, ECE445 Team 11 - Sensor Subsystem Schematic. 2024.

[4] A. Sherwin, ECE445 Team 11 - Humidifier Subsystem Schematic. 2024.

[5] Espressif, “ESP32-S3-WROOM-1 ESP32-S3-WROOM-1U Datasheet,” Espressif, 2023. https://www.espressif.com/sites/default/files/documentation/esp32-s3-wroom-1_wroom-1u_datasheet_en.pdf (accessed Mar. 26, 2024).

[6] IEEE, “IEEE Code of Ethics,” IEEE Code of Ethics, Jun. 2020. https://www.ieee.org/about/corporate/governance/p7-8.html (accessed Mar. 26, 2024).

[7] Espressif, “sch_esp32-s3-devkitc-1_v1_20210,” Espressif, Apr. 13, 2022. https://dl.espressif.com/dl/schematics/SCH_ESP32-S3-DevKitC-1_V1.1_20220413.pdf (accessed Mar. 26, 2024).

[8] A. Sherwin, Sensor Subsystem Block Diagram. 2024.

[9] A. Sherwin, Humidity Subsystem Block Diagram. 2024.

1 Individual Progress Report

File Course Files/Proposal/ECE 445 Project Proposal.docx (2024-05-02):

ECE 445

Senior Design Laboratory

Project Proposal

Automatic Humidity Sensing and Water Refilling Cool-Mist Humidifier

Team No. 11

Andrew Sherwin

(zyxie2@illinois.edu) Jalen Chen

(jalenc3@illinois.edu) Woojin Kim

(wkim51@illinois.edu)

TA: Surya Vasanth

Professor: Dr. Jonathon Schuh

February 08, 2024

## Abstract

Improper indoor humidity levels are a cause for health issues, such as dry skin or inflamed sinus passages. With the majority of humidifiers on the market being manually controlled, this causes an issue when no operator is present. A room can be under-humidified or over-humidified when there is no one to control the humidity output. As a result, we propose a cost-effective humidifier that will mitigate this problem. Concerned about the health of the operator, a cool-mist humidifier design was chosen. This humidifier communicates via 2.4GHz WIFI with multiple remote humidity sensors before determining the need to turn itself on or off. When the humidifier filter needs more water, the humidifier will activate a water valve that will irrigate the filter to the perfect amount. With all the components combined, this humidifier brings a new perspective to the humidifiers already on the market, guaranteeing the safety and comfort of the user. A truly luxurious experience.

# Introduction

## Problem and Solution

The United States Environmental Protection Agency (EPA) strongly suggests the regulation of indoor humidity to be between 30%-50%. When indoor humidity falls within these ranges, pollutants, such as chemicals, gasses, mold, and other airborne particles, are minimized in the air. This ultimately helps with allergies, respiratory illnesses, and other health issues.

To maximize the health benefits of our product, we decided to implement a cool mist humidifier. Unlike ultrasonic humidifiers and warm mist humidifiers, this product does not disperse bacterial matters, minerals, or cause your nasal passages, as the US Food and Drug Administration (FDA) suggests. To further improve humidifiers on the market, our humidifier features an automatic-on function and an automatic water tank filling function. The solution has three remote humidity sensors. These sensors detect the humidity and communicate the humidity readings with the humidifier. Using the average of these readings, the humidifier decides whether it is necessary to turn itself on or off. Inside the water tank of the humidifier are two water sensors. One sensor detects whether more water is needed, while the other sensor detects when to stop automatically adding water. With all these improvements, we push out a revolutionary humidifier system onto the market that has a high level of autonomy, providing a luxurious product to the end-user.

## Visual Aid


Figure 1: Consumer Visual Aid

The visual aid (figure 1) supports better understanding of how our product gives a solution to the suggested problem. Water supplied through water input to the tank will be brought to the filter located under the fan, then the fan will help to blow water out to the air. After the humidifier receives humidity data from the sensors, it will calculate then decide whether to turn the fan on/off.

## Physical Design

The physical design offers detailed information about inner components of the product. Two water-level sensors will be located vertically on the water tank to send fill/stop-fill signals to the ESP32 on the humidifier to open/close the DC water valve. It also shows the water filter that must be changed routinely to prevent potential hygiene risks. After reading humidity data, the humidity sensor will send its ESP32, then it will transmit the data to the humidifier ESP32 through 2.4GHz Wi-Fi.

## High Level Requirements

Our project would need to achieve a multitude of high-level goals to be sufficiently complete. Some goals would include:

1. The ESP32 can read data from the humidity sensor. The ESP32 in the sensor can communicate with the other ESP32 in the humidifier.
2. There should be multiple ESP32 sensor PCBs communicating with humidifier PCB for multiple humidity readings in the proximity of the system. The humidifier’s fan can turn on and off based on a measured humidity range.
3. The filter irrigation system irrigates the filter when the water level sensor readings indicate more water is needed when running low.

# Design

## Block Diagram

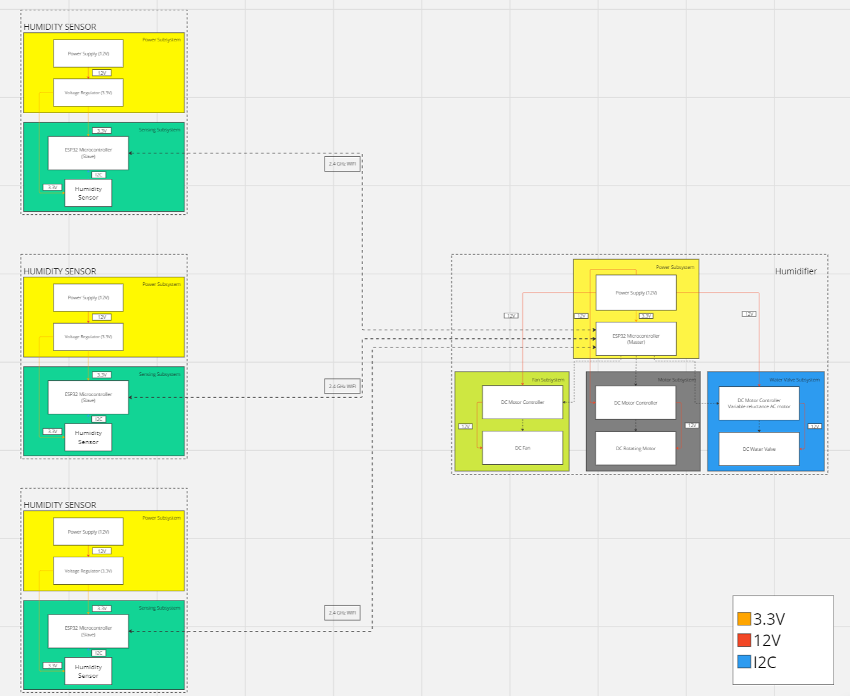
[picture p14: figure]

## Subsystem Overview / Requirements

### Humidifier Subsystem:

The humidifier subsystem controls the humidity output of the humidifier. This subsystem consists of a power subsystem that converts 110V AC to a 12V DC power. The 12V DC is sent through a voltage regulator. The output is a maintained 3.3V. This 3.3V is used to power the ESP32 microcontroller. The ESP32 microcontroller is the main microcontroller of the entire system. It communicates with the ESP32 microcontroller in the humidity sensor subsystems. In this relationship, the humidifier subsystem’s ESP32 is the master, and the humidity sensor subsystem’s ESP32s are the slaves. Based on the incoming data, the ESP32 will determine whether to turn on the humidifier’s fan or not. The motor uses 12V, from the power supply. When the humidifier needs more water, the ESP32 will send a signal to the water valve’s motor control system to turn on the water valve to wet the filter for X-seconds. The system knows to not add more water when the water level sensor detects liquid at the “max fill” line.

### Humidity Sensor Subsystem:

The humidity sensor subsystem detects humidity before relaying it back to the humidifier’s ESP32 microcontroller. The subsystem received power from a 110V AC to 12V DC power supply. The 12V power supply is input in a barrel jack on the PCB. The 12V is sent through a voltage regulator that maintains a 3.3V output. This 3.3V is used to power the ESP32 chip in the humidity sensor subsystem as well as the SHT45 humidity sensor. The ESP32 controls the SHT45 chip. The ESP32 in each humidity sensor subsystem serves as the master and the SHT45 is the slave. The ESP32 receives data from the SHT45 via I2C. After receiving the data, the ESP32 in the humidity sensor subsystem sends the humidity sensor’s data to the ESP32 in the humidifier subsystem. In this scenario, the ESP32 in the humidity sensor subsystem is the slave, while the ESP32 in the humidifier subsystem is the master.

### Subsystem Requirements

#### Humidifier Subsystem

i. Circuit must be powered by a 12V input source, which is then regulated at 3.3V and 6.6V for respective components.
ii. ESP32 board on board must successfully receive wireless communication signals from remote ESP32 microcontrollers (humidity data)
iii. ESP32 should open DC water valve when water level sensor suggests humidifier filter needs irrigation.
iv. ESP32 should close DC water valve when water level sensor suggests water level is at maximum.
v. ESP32 should turn on humidifier when room humidity levels fall under a predetermined humidity percentage.
vi. ESP32 should turn off humidifier when room humidity levels are above a predetermined humidity percentage.

#### Humidity Sensor Subsystem

i. Circuit must be powered by a 12V input source, which is then regulated at 3.3V and 6.6V for respective components.
ii. ESP32 board should be able to communicate with SHT45 humidity sensor with I2C.
iii. ESP32 board should be able to communicate with ESP32 in humidifier, relaying the SHT45’s data to it.

### Tolerance Analysis / Potential Error

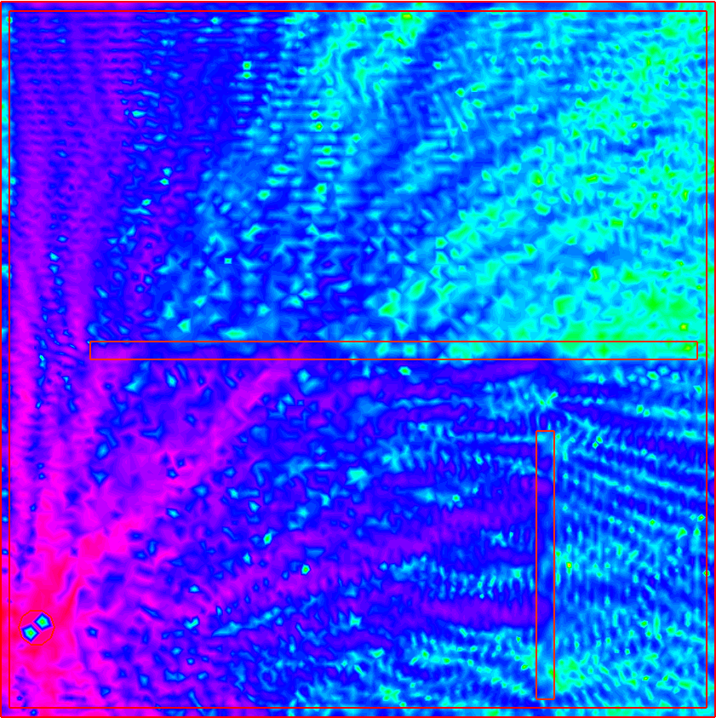
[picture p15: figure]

A significant aspect of our design that could pose a major risk to our project is the strength in the Wi-Fi signals being used to communicate between the sensors. Our project majorly depends on multiple microcontrollers in multiple sensors across many different areas in a room using Wi-Fi to connect to the central microcontroller. If any of these signals were interrupted, it would cause an impactful change in the way our system functions. Our completion of the project would be deemed nearly impossible without a proper wireless communication protocol, whether it be Bluetooth or Wi-Fi. For example, Wi-Fi is essentially a EM wave that operates through the medium of air containing the data we need, and can be more accurately defined using sets of Maxwell’s equations, most notably the Helmholtz equation that gives us the equation E∇^(2) + E(k^2)/(n^2)= 0, which are the electric fields mapped based on the angular wavenumber k and the material index n (Hecht). Below is a sample model taken from a reference site, Freefem, that will model what the signals will look like at a certain point in the area.

Figure 1 - Signal Strength Diagram (Hecht)

In figure 1, it shows a point where the electromagnetic signal is being read and the relative strength of it compared to the waves across the rest of the room. This will be how our sensors operate, with the signals being the strongest at receiving/interacting ends and having the most possible interference in between transmissions. To mitigate this issue, we will test if signals are possible to fully transmit all necessary data given multiple sensor points. If information is not fully available because of the strength or interference of other signals, we will act to measure where exactly the field is weak and create optimal positions for our sensors to generate the most effective waves. Another solution to this problem could be examining the materials that have interference potential such as metal or concrete, and either removing or replacing those materials in highly affected areas.

The accuracy of the humidity and temperature sensor also matters. According to the U.S. Environmental Protection Agency, indoor humidity should be kept between 30% and 50%. This is an adequate amount of humidity for healthy bodily function and prevents dust and other allergy causing substances from becoming easily airborne. According to Sensirion AG’s documentation in figure 2, the SHT45 sensor has a predicted typical error of 1% humidity between 20% and 70% humidity. The maximum error is 2% in this range. There is potential room for error when humidity increases to a point greater than 70% humidity or less than 20% humidity. We mitigate these errors because we do not believe this will happen. Furthermore, if it happens, it will not interfere with the functionality of our humidifier system. The humidifier will always be off above 50% humidity. Therefore, there is no need to worry about readings above 70%. Similarly, when the humidity falls below 20%, the humidifier will always be on. In a similar case, there is no need to worry about humidity values and the higher potential for a reading error below 20% humidity.

Aside from the accuracy of the readings, the data communication between the humidity sensor and the ESP32 board also is quite important. If the trace on the PCB is a distance that is too long, it might cause a signal mismatch by the receiver. Furthermore, the bus speed also matters. There are multiple modes for I2C, with the standard mode transferring data at 100Kbits/s, fast mode transferring data at 400Kbits/s, and high-speed mode at 3.4Mbits/s. While faster modes can communicate with a slow-mode device, a slow mode device is unable to communicate with a fast-mode device. As a result, the SHT45 and the ESP32 microcontroller must use handshake to communicate without data loss. Aside from that, the PCB traces must be kept at a minimum length, so that data does not get slowed down during transmission.

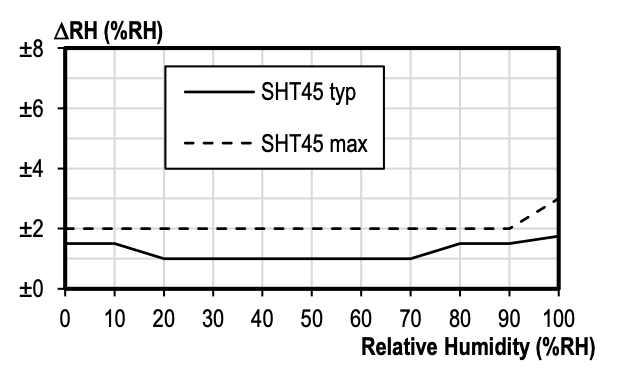
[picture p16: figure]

Figure 2 – SHT45 Humidity Accuracy Rating

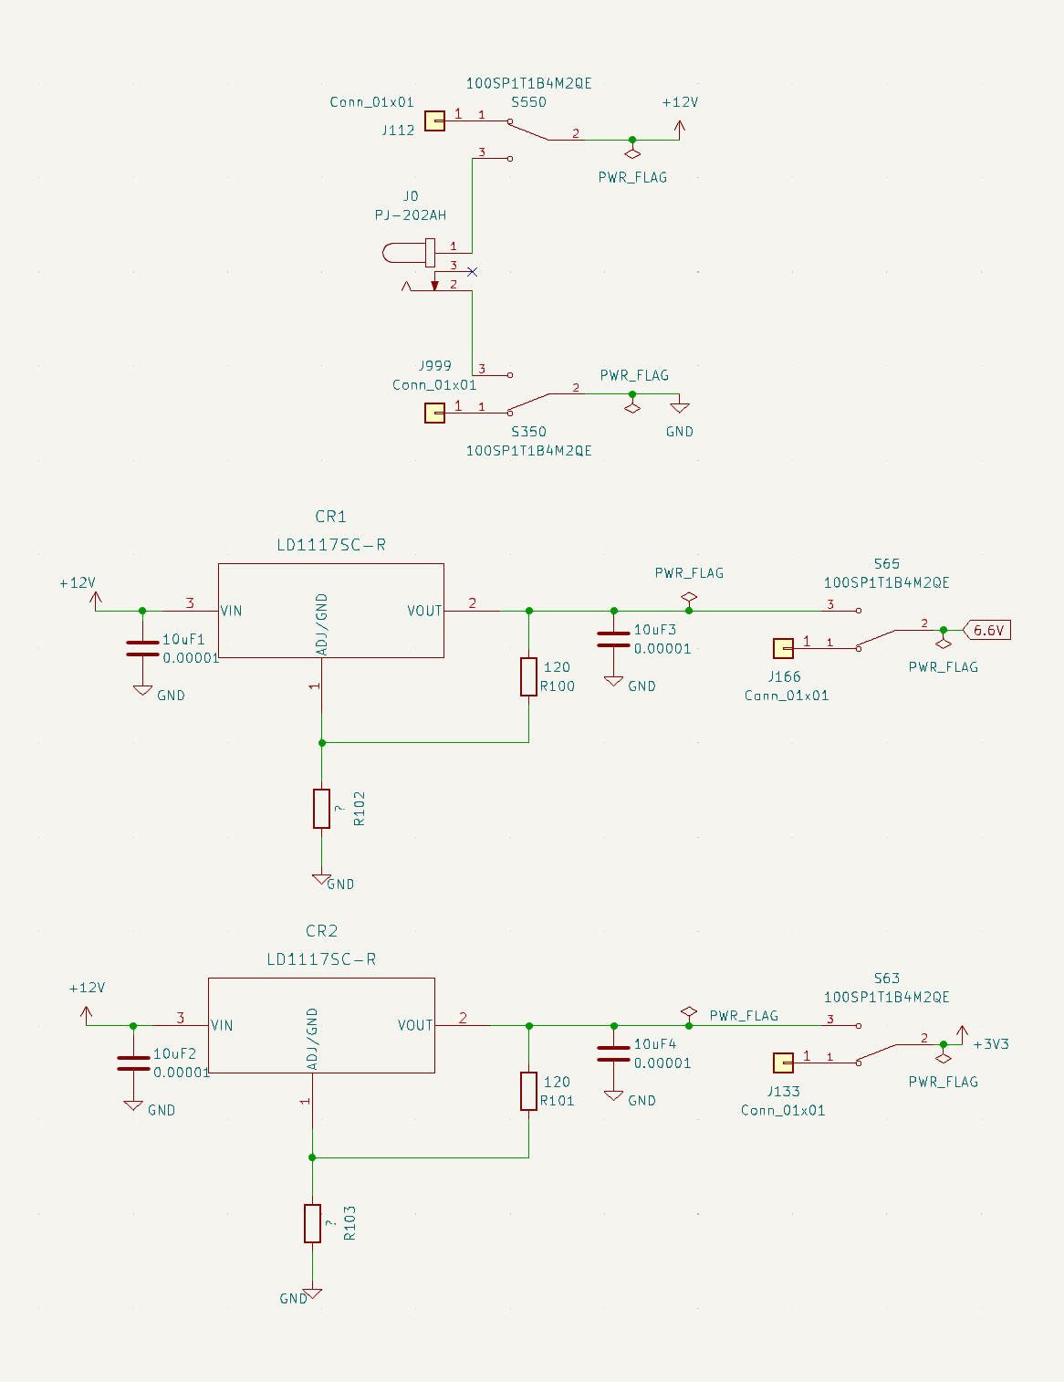
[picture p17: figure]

In the KiCAD schematic below (figure 3), we see the barrel jack connection and the voltage regulator set-up that we will be using. There are physical switches in the barrel jack port and the voltage regulators for a secondary backup power source. This is done due to the potential error case of a static discharge from an error handling the PCB. The LD1117SC-R adjustable voltage regulators are sensitive to static discharge. With a switch that can change the PCB power to a DC power supply, this addresses the issue in the case of a potential static discharge frying the electronic component.

Figure 3 – KiCad Voltage Regulator Design

# Ethics and Safety

For our initial examination of ethics, we were able to justify our project using the IEEE code of ethics. As students and soon-to-be workers, we know that whatever we do will have an impact on the world, primarily through the products and services we work on. Therefore, we must make sure to set some ethical guidelines that match with the code.

i. To uphold the highest standards of integrity, responsible behavior, and ethical conduct in professional activities. (IEEE, 2020)
  a. We will keep an open-minded state to each other's opinions. Utilizing everyone’s opinions, we will try to find the most ideal solution to our problems.
  b. We will keep the integrity of our research to the highest degree. All data collected will be the truthful original and will not be “tuned” in any way.
  c. We will keep the safety of our members and those working around us to the utmost highest standard.
  d. We will adhere to the rules and regulations of the University of Illinois and ECE445’s lab conduct rules.
  e. Constructive advice and criticisms will be accepted, and any forms of bribery will not be tolerated.
ii. To treat all persons fairly and with respect, to not engage in harassment or discrimination, and to avoid injuring others. (IEEE, 2020)
  a. We will treat all members within and outside our group with respect on physical and non-physical standpoints.
  b. Sexual harassment is not tolerated and will be reported to appropriate parties.
iii. To strive to ensure this code is upheld by colleagues and co-workers. (IEEE, 2020)
  a. We will strive to uphold this code of conduct provided from IEEE and in our team contract. Any behavior outside the rules will be reported to the correct authorities.
iv. To seek, accept, and offer honest criticism of technical work, to acknowledge and correct errors, to be honest and realistic in stating claims or estimates based on available data … (IEEE, 2020)
  a. A central ethical concern includes directly impacting humans as a first resort without being able to test otherwise. For example, for most scientific products, humans are the final stage of a trial in a product because all previous stages have been cleared or given approval through uses of inanimate objects or lab animals. Our problem is generally a comfort-based one, and so the general ethical concern would be the first stage exposure to humans since there would not be a test trial. If our main issue is comfort, we will never know how it feels until actual humans have tested it. Therefore, as one of the IEEE Code of Ethics indicates, we will seek and accept any technical criticisms from TA, instructors, and machine shop, be realistic and responsible to revise the problem until we reach agreement. On top of that we will measure the humidity carefully and regulate with the correct amounts of moisture, making sure that we only deviate from the average quantity only once we have received indication that it is comfortable.
v. A safety concern is the issue of potential bacteria and mold. Our automatic humidifier should get rid of this, but this issue could severely impact the humidifier if there turns out to be traces of something contagious that can be widespread with the device. The dangers of something airborne that could get into your lungs would be catastrophic if not regulated correctly.
vi. Another possible safety issue could be the moving parts of a fan that could injure you if you try to touch the mechanical components. The fan’s motor will likely be insulated from external touch, but there is always a chance that something breaks and another chance that the moving part accidentally meets someone, leading to a higher chance of injury.
vii. A common matter that arises as well is if there is a connected cable that meets water. Our humidifier will likely be powered through a wired connection, and any water that comes into contact either from the humidifier or an external water source will damage the system, or even worse, cause physical harm to someone. This safety issue would need to be fixed through epoxy or some type of non-porous material insulating the device and its connections.
viii. Dangerous chemicals are a final hazard that could be caused intentionally or by accident. Chemicals could be an issue if put inside the supply which normally contains water. If a dangerous fluid was put in the supply on purpose, then the humidifier might act as normal, sensing the humidity levels and then dispersing a life-threatening liquid instead of water. This would cause great harm and even possibly death if misused, so it is of utmost importance that the person using the device is careful and is sensible. Otherwise, the designers are not subject to responsibility and take no claim in the misuse of the product, which in that case, the user should refer to the instructions provided.

# References

[1] Hecht, F. (n.d.). WiFi Propagation . WIFI propagation. https://doc.freefem.org/tutorials/wifiPropagation.html
[2] Marwell, M. (2018, August 9). Issues with the I²C (inter-ic) bus and how to solve them. DigiKey. https://www.digikey.com/en/articles/issues-with-the-i2c-bus-and-how-to-solve-them
[3] Sensirion. (2023). SHT4x 4th Generation, High-Accuracy, Ultra-Low-Power, 16-bit Relative Humidity and Temperature Sensor. In Sensirion Official Documentation (Issue 6). Sensirion.
[4] United States Environmental Protection Agency. (2014, August 28). Care for your air: A guide to indoor air quality. US EPA. https://www.epa.gov/indoor-air-quality-iaq/care-your-air-guide-indoor-air-quality
[5] Espressif. (2023). ESP32-S3-WROOM-1 ESP32-S3-WROOM-1U Datasheet. Espressif. https://www.espressif.com/sites/default/files/documentation/esp32-s3-wroom-1_wroom-1u_datasheet_en.pdf
[6] Metageek. (2024). Wi-Fi and non wi-fi interference. MetaGeek. https://www.metageek.com/training/resources/wifi-and-non-wifi-interference/
[7] Arundel, A. V., Sterling, E. M., Biggin, J. H., & Sterling, T. D. (1986). Indirect health effects of relative humidity in indoor environments. Environmental Health Perspectives, 65, 351–361. https://doi.org/10.1289/ehp.8665351
[8] Perrone, V., Veronesi, C., Giacomini, E., Citraro, R., Dell’Orco, S., Lena, F., Paciello, A., Resta, A. M., Nica, M., Ritrovato, D., & Degli Esposti, L. (2022). The epidemiology, treatment patterns and economic burden of different phenotypes of multiple sclerosis in Italy: Relapsing-Remitting multiple sclerosis and secondary progressive multiple sclerosis. Clinical Epidemiology, 14, 1327–1337. https://doi.org/10.2147/CLEP.S376005
[9] IEEE. (2020). IEEE code of ethics. IEEE Code of Ethics. https://www.ieee.org/about/corporate/governance/p7-8.html

2 Automatic Humidity Sensing and Water Refilling Cool-Mist Humidifier

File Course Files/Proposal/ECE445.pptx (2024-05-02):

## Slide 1

Sensor 1 (Slave)
- ESP32
- Humidity/Temp Sensor

WIFI

WIFI

Humidifier (Master)
- ESP32
- Servo Motor (direction)
- Fan motor
- Water irrigation

Sensor 2 (Slave)
- ESP32
- Humidity/Temp Sensor

WIFI

Sensor 3 (Slave)
- ESP32
- Humidity/Temp Sensor

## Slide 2

Humidifier

ESP32
(3.3V)

Water Valve Motor
(5V)

Servo Motor
(5V)

Fan Motor
(12V)

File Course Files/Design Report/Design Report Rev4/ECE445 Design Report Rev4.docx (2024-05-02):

ECE 445

Senior Design Laboratory

Design Report

Automatic Humidity Sensing and Water Refilling Cool-Mist Humidifier

Team No. 11

Andrew Sherwin

(zyxie2@illinois.edu) Jalen Chen

(jalenc3@illinois.edu) Woojin Kim

(wkim51@illinois.edu)

TA: Surya Vasanth

Professor: Dr. Jonathon Schuh

February 22, 2024

## Abstract

Improper indoor humidity levels are a cause for health issues, such as dry skin or inflamed sinus passages. With the majority of humidifiers on the market being manually controlled, this causes an issue when no operator is present. A room can be under-humidified or over-humidified when there is no one to control the humidity output. As a result, we propose a cost-effective humidifier that will mitigate this problem. Concerned about the health of the operator, a cool-mist humidifier design was chosen. This humidifier communicates via 2.4GHz WIFI with multiple remote humidity sensors before determining the need to turn itself on or off. When the humidifier filter needs more water, the humidifier will activate a water valve that will irrigate the filter to the perfect amount. With all the components combined, this humidifier brings a new perspective to the humidifiers already on the market, guaranteeing the safety and comfort of the user. A truly luxurious experience.

# Introduction

## Problem and Solution

The United States Environmental Protection Agency (EPA) strongly suggests the regulation of indoor humidity to be between 30%-50%. When indoor humidity falls within these ranges, pollutants, such as chemicals, gasses, mold, and other airborne particles, are minimized in the air. This ultimately helps with allergies, respiratory illnesses, and other health issues.

To maximize the health benefits of our product, we decided to implement a cool mist humidifier. Unlike ultrasonic humidifiers and warm mist humidifiers, this product does not disperse bacterial matters, minerals, or cause your nasal passages, as the US Food and Drug Administration (FDA) suggests. To further improve humidifiers on the market, our humidifier features an automatic-on function and an automatic water tank filling function. The solution has three remote humidity sensors. These sensors detect the humidity and communicate the humidity readings with the humidifier. Using the average of these readings, the humidifier decides whether it is necessary to turn itself on or off. Inside the water tank of the humidifier are two water sensors. One sensor detects whether more water is needed, while the other sensor detects when to stop automatically adding water. With all these improvements, we push out a revolutionary humidifier system onto the market that has a high level of autonomy, providing a luxurious product to the end-user.

## Visual Aid


Figure 1: Consumer Visual Aid

The visual aid (figure 1) supports better understanding of how our product gives a solution to the suggested problem. Water supplied through water input to the tank will be brought to the filter located under the fan, then the fan will help to blow water out to the air. After the humidifier receives humidity data from the sensors, it will calculate then decide whether to turn the fan on/off.

## Physical Design


Figure 2 – Component Visual Aid

The physical design offers detailed information about inner components of the product. Two water-level sensors will be located vertically on the water tank to send fill/stop-fill signals to the ESP32 on the humidifier to open/close the DC water valve. It also shows the water filter that must be changed routinely to prevent potential hygiene risks. After reading humidity data, the humidity sensor will send its ESP32, then it will transmit the data to the humidifier ESP32 through 2.4GHz Wi-Fi.

## High Level Requirements

Our project would need to achieve a multitude of high-level goals to be sufficiently complete. Some goals would include:

1. The ESP32 can read data from the humidity sensor through the use of the ESP32 microcontroller communication through the three different sensors placed around the room, communicating all with ESPs via 2.4 GHz Wi-Fi with continuous readings. This will allow us to use average humidity to determine a good range for on/off functionality.

2. The filter irrigation system refills the water tank with water depending on signals from two water level sensors at top and bottom of the tank. The ESP32 will activate the 12V DC water valve, creating a flow of water which will turn off when the top sensor detects water. The measured max capacity of the water tank should be 4.16 liters every 24 hours and the filter should absorb around 150 milliliters ± 5 milliliters.

3. The humidifier should be operating between 35% and 50% humidity. If the value is beyond 50, the humidifier turns off, and if below 35, it turns on. With remote communication between the humidity sensor’s ESP32 microcontroller and the humidifier’s ESP32 microcontroller, there is an estimated 44ns response time to the activation and the deactivation of the humidifier’s fans.

# Design

## Block Diagram

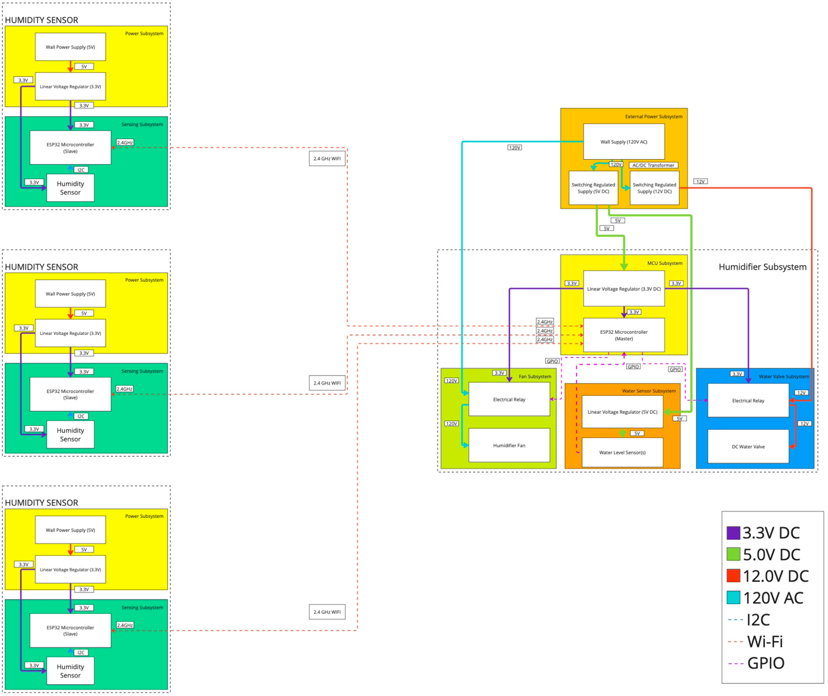
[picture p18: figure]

Figure 3 – Overall Block Diagram

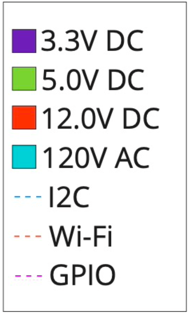
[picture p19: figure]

_____________________________________________________________________________________________________________________________________________________

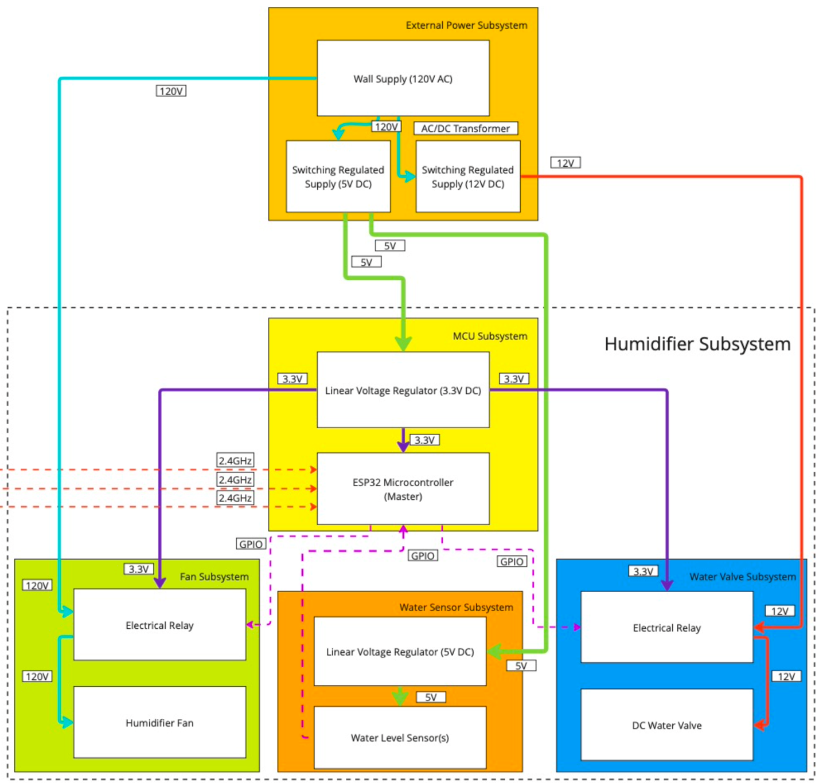
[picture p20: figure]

Figure 4 – Humidifier Subsystem Block Diagram (Close-up)

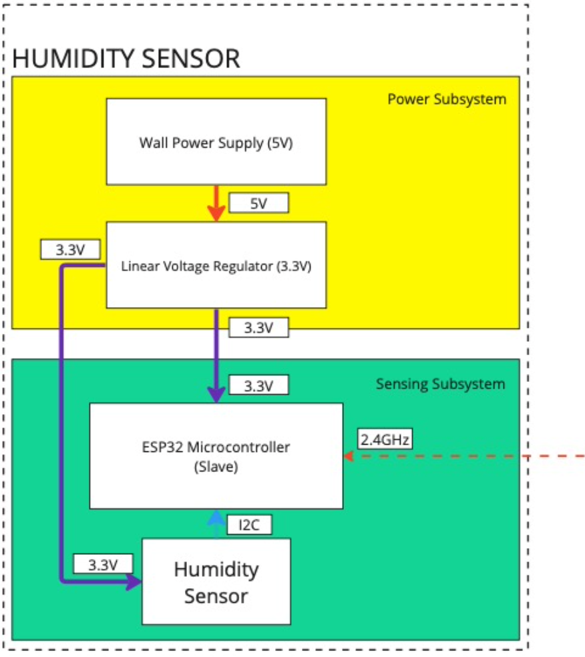
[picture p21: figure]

Figure 5 – Humidity Sensor Subsystem Block Diagram (Close-up)

Our block diagram is divided into two main parts. The Humidity Sensor subsystem and Humidifier subsystem. Within the humidifier subsystem consists of the power supply, fan, and water valve subsystems. The power supply subsystem regulates 12V input to 3.3V. This 3.3V is used to power the ESP32 microcontroller in the humidifier subsystem. The power subsystem also sends out 12V to the fan DC relay controller and the water valve DC relay controller. These DC relay controllers send 12V to their respective controlled motors. The ESP32 in the power subsystem also sends an on/off signal to the DC relay controllers. This tells the relay controllers to turn the DC motors on/off. Aside from the communication with the DC relay controllers, the humidifier subsystem’s ESP32 microcontroller also communicates via 2.4 GHz Wi-Fi with another ESP32 microcontroller in our next subsystem, the humidity sensor subsystem.

Similar to the humidifier subsystem, the humidity sensor subsystem also consists of the power subsystem. The power supply gives a 12V DC input that gets regulated to 3.3V. The 3.3V is sent to power the ESP32 in each humidifier subsystem. At every humidifier subsystem, there is a sensor subsystem. Inside the sensor subsystem are the ESP32 microcontroller and a SHT45 humidity sensor. These two devices communicate with each other in standard-mode (100kHz) I2C. Aside from communicating with the SHT45, the ESP32 also communicates with the ESP32 in the humidifier subsystem, as mentioned previously.

## Subsystem Overview / Requirements

### Humidifier Subsystem:

The humidifier subsystem controls the humidity output of the humidifier. This subsystem consists of a power subsystem that converts 110V AC to a 12V DC power. The 12V DC is sent through a voltage regulator. The output is a maintained 3.3V. This 3.3V is used to power the ESP32 microcontroller. The ESP32 microcontroller is the main microcontroller of the entire system. It communicates with the ESP32 microcontroller in the humidity sensor subsystems. In this relationship, the humidifier subsystem’s ESP32 is the master, and the humidity sensor subsystem’s ESP32s are the slaves. Based on the incoming data, the ESP32 will determine whether to turn on the humidifier’s fan or not. The motor for the fan uses 12V from the power supply and starts to rotate to run the fan. This is the main source of propulsion for our fan to produce the water into the air. When the humidifier needs more water, the ESP32 will send a signal to the water valve’s motor control system to turn on the water valve to enable the connection to the source of water, such as water pipeline at home, to fill up the 4.16-liter water tank, to wet the filter for X-seconds. This motor will be used to turn the water valve on based on the amount of water needed or shut off the flow of water once the system’s water level sensor detected liquid at the “max fill” line. The water valve’s subsystem power source will be 12 V DC coming from the barrel jack which was converted from 110V AC from the wall supply. This power was integrated throughout the whole system through 12V to the fan as well as the water valve subsystem, as both are motors that require this voltage to operate properly.

### Humidity Sensor Subsystem:

The humidity sensor subsystem detects humidity before relaying it back to the humidifier’s ESP32 microcontroller. The subsystem received power from a 110V AC to 12V DC power supply. The 12V power supply is input in a barrel jack on the PCB. The 12V is sent through a voltage regulator that maintains a 3.3V output. This 3.3V is used to power the ESP32 chip in the humidity sensor subsystem as well as the SHT45 humidity sensor. The ESP32 controls the SHT45 chip. The ESP32 in each humidity sensor subsystem serves as the master and the SHT45 is the slave. The ESP32 receives data from the SHT45 via I2C. After receiving the data, the ESP32 in the humidity sensor subsystem sends the humidity sensor’s data to the ESP32 in the humidifier subsystem. In this scenario, the ESP32 in the humidity sensor subsystem is the slave, while the ESP32 in the humidifier subsystem is the master.

### Subsystem Requirements

#### Humidifier Subsystem

i. Circuit must be powered by a 12V input source, which is then regulated at 3.3V for respective components. The microcontroller and humidity sensor takes in 3.3V. The motors will be powered by 12 V to operate at the maximum capability. We will use an oscilloscope to verify the voltage that it’s the desirable number with +/- 0.5%.
ii. ESP32 on the humidifier board must successfully receive wireless communication signals from remote ESP32 microcontrollers to obtain humidity data. Wi-Fi (2.4 GHz), electromagnetic waves travels nearly fast as speed of light, thus for 6 meters, it takes about 20 ns to reach from the humidity sensor to the humidifier, but it’s such fast compared to desirable humidifier turn on/off update frequency, the actual data transfer speed can be mitigated and only it’s enough to only verify that the humidifier receives all the data from three humidity sensors every X seconds/minutes.
iii. ESP32 should open the DC water valve when the bottom water level sensor suggests the water tank needs to be filled and close the DC water valve when the top water level sensor suggests the water level is at maximum water tank capacity. These functionalities can be verified by filling up the tank and seeing if the ESP32 on the humidifier board successfully receives signals from both sensors.
iv. ESP32 should turn on the humidifier when the average (from three sensors combined) room humidity level falls under 35% humidity and turn off the humidifier when the average room humidity level rises above 50% humidity. These functionalities can be verified if ESP32 on the humidifier board can correctly control the fan motor when it gets corresponding data from the sensor ESPs.
v. This subsystem will contribute to the overall design dictated by the high-level requirements by acting as the central subsystem that will control the main microcontroller, along with the 12V motors that drive the water supply valve and the water evaporation fan. Then the readings from the humidity sensor subsystem will communicate through 2.4 GHz Wi-Fi to our main microcontroller to tell the fan to turn on or not based on an ideal range of between 35% and 50% humidity as mentioned in the requirements. Then the microcontroller will send the data to moisture the air, with approximately 83 mililiters per hour. The water sensor will also control our water filling of up to 4.16 liters to communicate to the microcontroller whether we have reached max capacity or not.

#### RV-Table – Humidifier Subsystem

Requirements | Verification
- Provide 3.3V +/- 0.5% from an input voltage of 12V +/- 0.10% DC source - Thermal stability maintains below 120’C | - Use multimeter to test and take average voltage output over 1-hour to test stability - Monitor heat dissipation with thermal laser gun over an average of 1-hour use time, expected +/- 5’C under load
- ESP32 communication with remote sensor ESP32 utilizing 2.4GHz Wi-Fi | - Verify functionality of ESP32 Wi-Fi component by creating an access point, and accessing access point to remotely receive data - Verify communication between two ESP32 boards by sending command to turn on LED light from one ESP32 board - Verify thermal performance of ESP32 chip during operation by probing with a laser thermal gun
- ESP32 control of activation and deactivation of water valve - ESP32 control of activation and deactivation of fan | - Verify functionality of ESP32 communication with DC relay by sending activation signal to water valve/fan DC relay controller, and when signal is received, DC relay controllers output a lit LED light - Probe the output voltage of the DC relay controllers to make sure it is 12V +/- 0.5%
- ESP32 detects signals from two water-level sensors | - Contact/No Contact water to the water-level sensors and check through Arduino IDE to see if ESP32 receives contact/no contact signal from the two water-level sensors - Water level sensor lights up LED when in contact with water, and LED is not lit when not in contact with water

#### Humidity Sensor Subsystem

i. Circuit must be powered by a 12V input source, which is then regulated at 3.3V for respective components. We will use an oscilloscope to verify the voltage that it’s the desirable number with +/- 0.5%.
ii. ESP32 board should be able to communicate with SHT45 humidity sensor with I2C. Communication between the humidity sensor and the ESP32 on the same PCB through I2C is fast enough compared to how frequently the humidity sensor measures the humidity, which varies from 1.3 to 8.3 ms depending on the noise and energy consumption. It’s enough to verify that the ESP32 in the humidity sensor receives all the data from its sensor every X seconds/minutes.
iii. ESP32 board should be able to communicate with ESP32 in humidifier, relaying the SHT45’s data to it.
iv. ESP 32 will communicate with the humidity sensor as same frequency.
v. These functionalities can be verified by giving different humidity conditions to the humidity sensor.
vi. This subsystem will be connected to the overall design through measuring the correct humidity in a certain area, and with 3 different humidity sensors, there would be a range that is created that the central microcontroller would read because the data is being sent from each individual microcontroller per sensor through Wi-Fi, with an expected response time of 44ns through communication of the I2C protocol.

#### RV-Table – Humidity Sensor Subsystem

Requirements | Verification
- Provide 3.3V +/- 0.5% from an input voltage of 12V +/- 0.10% DC source - Thermal stability maintains below 120’C | - Use multimeter to test and take average voltage output over 1-hour to test stability - Monitor heat dissipation with thermal laser gun over an average of 1-hour use time, expected +/- 5’C under load
- ESP32 communication with humidity sensor receiving humidity data at least once in a minute - Humidity sensor measuring humidity data at least between 25% - 55% | - Verify communication between ESP32 and humidity sensor Arduino IDE by checking humidity data ESP32 receives - Compare the humidity data received by ESP32 to the commercial humidity sensor and check if the humidity is within +/- 3% - Make the air dry/moist to see if the sensor can measure humidity between 25% - 55% - Compare humidity reading with reference humidity reader

### Tolerance Analysis / Potential Error

A significant aspect of our design that could pose a major risk to our project is the strength in the Wi-Fi signals being used to communicate between the sensors. Our project majorly depends on multiple microcontrollers in multiple sensors across many different areas in a room using Wi-Fi to connect to the central microcontroller. If any of these signals were interrupted, it would cause an impactful change in the way our system functions. Our completion of the project would be deemed nearly impossible without a proper wireless communication protocol, whether it be Bluetooth or Wi-Fi. For example, Wi-Fi is essentially a EM wave that operates through the medium of air containing the data we need, and can be more accurately defined using sets of Maxwell’s equations, most notably the Helmholtz equation that gives us the equation:

E∇^2 +(E(k^2 ))/(n^2)=0


which are the electric fields mapped based on the angular wavenumber k and the material index n (Hecht). Below is a sample model taken from a reference site, Freefem, that will model what the signals will look like at a certain point in the area.

Figure 6: Signal Strength Plot

In figure 6, it shows a point where the electromagnetic signal is being read and the relative strength of it compared to the waves across the rest of the room. This will be how our sensors operate, with the signals being the strongest at receiving/interacting ends and having the most possible interference in between transmissions. In our respective setup, we will use example calculations to model this. For example, wavelengths of our WiFi signals which will be used to communicate are approximately 12 centimeters give or take, given a 2.4 GHz WiFi default in our system. So the angular wavenumber:

k= 2π/λ

which given our lambda wavelength value, will give us 0.52 (rad)/(cm) . As for material index n, the value should just be the material index of air, which is the constant of 1. Given this, we have taken E as an average of 50 V/m for an electric field value inside a home. So our electric field gradient value will be equal to:

50× 0.52^2 =13.52 v/(m^3)

This value will indicate the electric field strength in a specific area, which matches our signal strength plot example above. The field will obviously be different at random areas in the room due to interference from various radio sources, such as other electronics or even your own body as a source. To mitigate this issue, we will test if signals are possible to fully transmit all necessary data given multiple sensor points. If information is not fully available because of the strength or interference of other signals, we will act to measure where exactly the field is weak and create optimal positions for our sensors to generate the most effective waves. Another solution to this problem could be examining the materials that have interference potential such as metal or concrete, and either removing or replacing those materials in highly affected areas. Trade-offs to our solutions would be that optimal positions for signal strength might not be optimal positions for humidifier strength. For example, if our sensors were positioned at 30, 45 and 180 degrees in a circular pattern in a rectangular room, there would be nearly no sensing of the humidity in the 270 degrees area. This would be sub-optimal because we would essentially have 2 sensors instead of 3 near evenly spaced ones, despite the connection being very reliable.

# Cost and Schedule

## Cost Analysis

### Parts and Materials

In our project, we have an estimated breakdown of the parts and materials needed in our final product. The part name, part number, number required per system, and the cost per system is provided. Each system consists of one humidifier subsystem, as well as three humidity sensor subsystems.

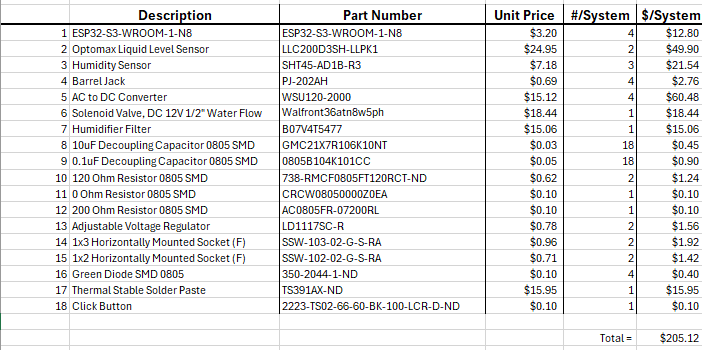
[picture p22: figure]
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

#### Table 1: Cost and Links for Parts

#### Hours of Development and Labor

Our project consists of multiple roles that need to be completed. We have an estimated 373.5 hours total between three group members on the project. Below is a breakdown of our estimated hours per person on each category.


Table 2 – Estimated Hours

With mixed electrical engineers and computer engineers in our group, we all have different hourly wages. Using the average UIUC ECE computer engineering published salary in 2021-2022 ($109,176.00), using 2080 work hours in a work year, we can expect an average hourly salary of $52.49.

($109,176.00)/(2080 hours)=$52.49 per hour

(135hours+127.5hours+111hours)× $52.49=$19,605.02

Summing up the total hours in the table above and multiplying it by the average salary, we get the total cost for labor to be: $19,605.02 for this project.

Aside from our own hours of labor, the machine shop estimates 7 hours of work to modify our humidifier with some parts included in Table 1. The machine-shop technician’s hourly cost is not public, so we will not include the cost in the total cost of development above.

## Schedule

1. Week 6 (02/19)
  a. Design Document
  b. Proposal Revision
  c. I2C communication between ESP32 and Humidifier
  d. 2.4GHz Wi-Fi communication between two ESP32 boards
  e. Give humidifier to machine shop
  f. Begin PCB Design for humidity sensor subsystem
2. Week 7 (02/26)
  a. Design PCB for humidity sensor subsystem
  b. Debug potential issues with PCB
  c. Interface water-level sensor with humidifier ESP32
  d. Control 12V DC water valve with ESP32
  e. Control humidifier fan with ESP32
  f. Potentially place first PCB order (individual)
3. Week 8 (03/04)
  a. Order PCB for humidity sensor subsystem (with class)
  b. Order electronic water valve
  c. Order second Adafruit water level sensor
  d. Design PCB for humidifier subsystem
  e. Debug potential issues with PCB
  f. Potentially send humidity sensor subsystem PCB to machine shop
  g. Potentially solder SMD components on humidity sensor PCB
4. Week 9 (03/11)
  a. Finish humidifier subsystem PCB design
5. Week 10 (03/18)
  a. Solder PCB for humidity sensor PCB
  b. Send humidity sensor PCB to machine shop
  c. Order PCB for humidifier
6. Week 11 (03/25)
  a. Reorder revised PCBs
  b. Solder PCB for humidifier subsystem
  c. Potentially put together humidifier
7. Week 12 (04/01)
  a. Begin writing final paper
  b. Finalize PCBs
  c. Send remaining updates to machine shop
8. Week 13 (04/08)
  a. Finalize product for presentation
  b. Begin writing final paper
  c. Last minute debugging
9. Week 14 (04/15)
  a. Team contract fulfillment
  b. Mock demonstration
  c. Finalize product for presentation
  d. Continue writing final paper
10. Week 15 (04/22)
  a. Final Demonstration
  b. Mock Presentation
  c. Final Presentation Preparation
  d. Continue writing final paper
11. Week 16 (04/29)
  a. Final Presentation Preparation
  b. Final Presentation
  c. Final Papers
  d. Lab Notebook
  e. Lab Checkout

# Ethics and Safety

For our initial examination of ethics, we were able to justify our project using the IEEE code of ethics. As students and soon-to-be workers, we know that whatever we do will have an impact on the world, primarily through the products and services we work on. Therefore, we must make sure to set some ethical guidelines that match with the code.

## Ethics

i. To uphold the highest standards of integrity, responsible behavior, and ethical conduct in professional activities. (IEEE, 2020)

a. We will keep an open-minded state to each other's opinions. Utilizing everyone’s opinions, we will try to find the most ideal solution to our problems.

b. We will keep the integrity of our research to the highest degree. All data collected will be the truthful original and will not be “tuned” in any way.

c. We will keep the safety of our members and those working around us to the utmost highest standard.

d. We will adhere to the rules and regulations of the University of Illinois and ECE445’s lab conduct rules.

e. Constructive advice and criticisms will be accepted, and any forms of bribery will not be tolerated.

ii. To treat all persons fairly and with respect, to not engage in harassment or discrimination, and to avoid injuring others. (IEEE, 2020)

a. We will treat all members within and outside our group with respect on physical and non-physical standpoints.

b. Sexual harassment is not tolerated and will be reported to appropriate parties.

iii. To strive to ensure this code is upheld by colleagues and co-workers. (IEEE, 2020)

a. We will strive to uphold this code of conduct provided from IEEE and in our team contract. Any behavior outside the rules will be reported to the correct authorities.

iv. To seek, accept, and offer honest criticism of technical work, to acknowledge and correct errors, to be honest and realistic in stating claims or estimates based on available data … (IEEE, 2020)

a. A central ethical concern includes directly impacting humans as a first resort without being able to test otherwise. For example, for most scientific products, humans are the final stage of a trial in a product because all previous stages have been cleared or given approval through uses of inanimate objects or lab animals. Our problem is generally a comfort-based one, and so the general ethical concern would be the first stage exposure to humans since there would not be a test trial. If our main issue is comfort, we will never know how it feels until actual humans have tested it. Therefore, as one of the IEEE Code of Ethics indicates, we will seek and accept any technical criticisms from TA, instructors, and machine shop, be realistic and responsible to revise the problem until we reach agreement. On top of that we will measure the humidity carefully and regulate with the correct amounts of moisture, making sure that we only deviate from the average quantity only once we have received indication that it is comfortable.

## Safety

In this section, we consider every type of the most common situations that could occur when using our automatic humidifier product.

  i. A safety concern would be the wall plug power. This is 120 V AC power typically, and so to prevent electrocution and shock issues, we would need to be aware of our surroundings and to connect the plug into the wall without any external connections to the outlet interrupting it in any way, such as holding loose wires or the metal section of the plug when you are plugging it into the wall.
  ii. A safety concern is the issue of potential bacteria and mold. Our automatic humidifier should get rid of this, but this issue could severely impact the humidifier if there turns out to be traces of something contagious that can be widespread with the device. The dangers of something airborne that could get into your lungs would be catastrophic if not regulated correctly.
  iii. Another possible safety issue could be the moving parts of a fan that could injure you if you try to touch the mechanical components. The fan’s motor will likely be insulated from external touch, but there is always a chance that something breaks and another chance that the moving part accidentally comes in contact with someone’s finger or something easily mistouched, leading to a higher chance of injury.
  iv. A common matter that arises as well is if there is a connected cable that meets water. Our humidifier will likely be powered through a wired connection, and any water that comes into contact either from the humidifier or an external water source will damage the system, or even worse, cause physical harm to someone. This safety issue would need to be fixed through epoxy or some type of non-porous material insulating the device and its connections.
v. Dangerous chemicals are a final hazard that could be caused intentionally or by accident. Chemicals could be an issue if put inside the supply which normally contains water. If a dangerous fluid was put in the supply on purpose, then the humidifier might act as normal, sensing the humidity levels and then dispersing a life-threatening liquid instead of water. This would cause great harm and even possibly death if misused, so it is of utmost importance that the person using the device is careful and is sensible. Otherwise, the designers are not subject to responsibility and take no claim in the misuse of the product, which in that case, the user should refer to the instructions provided.
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

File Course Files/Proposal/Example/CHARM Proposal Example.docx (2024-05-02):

ECE 445

Senior Design Laboratory

Project Proposal

# CHARM

CHeap Accessible Resilient Mesh for Remote Locations and Disaster Relief

Team No. 1

Martin Michalski

(martinm6@illinois.edu) MELISSA PAI

(mepai2@illinois.edu) TREVOR WONG

(txwong2@illinois.edu)

TA: Kai Chieh (Jeff) Chang

Professor: Victor Gruev September 15, 2022

Abstract

This document is a more detailed look at our project when compared to our RFA. We pro- vide high-level implementation details, requirements, and safety considerations.

Contents

# 1 Introduction

We provide details as to the problem we aim to address, along with our proposed solu- tion, in context.

## 1.1 Problem

Hurricanes, earthquakes, tsunamis, and other natural disasters all have the capability to destroy cellular- and inter- networks, cutting off victims from emergency services, unaf- fected survivors from worried loved ones, and rescuers from their command and control. This was the case in NYC after Hurricane Sandy, with a large area of the city facing cellu- lar outages for a month after the hurricane [1], and in Japan which experienced blackouts and cellular outages after a 2011 tsunami [2].

Remote areas also suffer from limited connectivity, with connections to cabling, cell tow- ers, and other networking hardware being few and far between [3]. In the case of an emergency, such communicative sparsity may even be fatal, e.g. a farmer which has a heart attack and is not able to call for emergency services or relatives to come to their aid.

## 1.2 Solution

To solve these problems, we would like to create a set of meshing, cheap, lightweight, and self-contained wireless access points, deployable via drone. After being placed by drone or administrator, these access points form a WiFi network, usable by rescuers, survivors, and civilians. Our network will have QoS features to prioritize network traffic originating from rescuers. Having nodes/access points deployable by drone ensures we are able to establish timely connectivity in areas where search and rescue operations are still unable to reach.

Over the course of the semester, we will produce a couple of prototypes of these network nodes, with built in power management and location sensing. We aim to demonstrate our limited network’s mesh capabilities by setting up a mock network on one of the campus quads, and connecting at various locations.
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

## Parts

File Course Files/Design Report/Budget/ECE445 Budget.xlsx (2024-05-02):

 |  |  |  |  |  |  |  | Member
 | Description | Part Number | Unit Price | #/System | $/System | Category | Andrew | Woojin | Jalen | Machine Shop
1 | ESP32-S3-WROOM-1-N8 | ESP32-S3-WROOM-1-N8 | $3.20 | 4 | $12.80 | Circuit Design | 21 | 15 | 12
2 | Optomax Liquid Level Sensor | LLC200D3SH-LLPK1 | $24.95 | 2 | $49.90 | PCB Design | 25 | 10 | 14
3 | Humidity Sensor | SHT45-AD1B-R3 | $7.18 | 3 | $21.54 | Quality Check | 6 | 1.5 | 12
4 | Barrel Jack | PJ-202AH | $0.69 | 4 | $2.76 | Software Engineering | 10 | 32 | 2
5 | AC to DC Converter | WSU120-2000 | $15.12 | 4 | $60.48 | Soldering | 1 | 2 | 10
6 | Solenoid Valve, DC 12V 1/2" Water Flow | ‎Walfront36atn8w5ph | $18.44 | 1 | $18.44 | Design Troubleshoot | 12 | 12 | 8
7 | Humidifier Filter | B07V4T5477 | $15.06 | 1 | $15.06 | Documentation | 20 | 20 | 20
8 | 10uF Decoupling Capacitor 0805 SMD | GMC21X7R106K10NT | $0.03 | 18 | $0.45 | Meetings | 35 | 30 | 30
9 | 0.1uF Decoupling Capacitor 0805 SMD | 0805B104K101CC | $0.05 | 18 | $0.90 | Miscellaneous | 5 | 5 | 20
10 | 120 Ohm Resistor 0805 SMD | 738-RMCF0805FT120RCT-ND | $0.62 | 2 | $1.24 | Total Hours | 135 | 127.5 | 128
11 | 500 Ohm Resistor 0805 SMD | CRCW08050000Z0EA | $0.10 | 1 | $0.10
12 | 200 Ohm Resistor 0805 SMD | AC0805FR-07200RL | $0.10 | 1 | $0.10
13 | Adjustable Voltage Regulator | LD1117SC-R | $0.78 | 2 | $1.56
14 | 1x3 Horizontally Mounted Socket (F) | SSW-103-02-G-S-RA | $0.96 | 2 | $1.92
15 | 1x2 Horizontally Mounted Socket (F) | SSW-102-02-G-S-RA | $0.71 | 2 | $1.42
16 | Green Diode SMD 0805 | 350-2044-1-ND | $0.10 | 4 | $0.40
17 | Thermal Stable Solder Paste | TS391AX-ND | $15.95 | 1 | $15.95
18 | Click Button | 2223-TS02-66-60-BK-100-LCR-D-ND | $0.10 | 1 | $0.10
 |  |  |  | Total = | $205.12

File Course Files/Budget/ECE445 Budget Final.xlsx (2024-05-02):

 |  |  |  |  |  |  |  | Member
 | Description | Part Number | Unit Price | #/System | $/System | Category | Andrew | Woojin | Jalen | Machine Shop
1 | ESP32-S3-WROOM-1-N8 | ESP32-S3-WROOM-1-N8 | $3.20 | 4 | $12.80 | Circuit Design | 72 | 2 | 50
2 | Optomax Liquid Level Sensor | LLC200D3SH-LLPK1 | $24.95 | 2 | $49.90 | PCB Design | 48 | 0.5 | 24
3 | Humidity Sensor | SHT45-AD1B-R3 | $7.18 | 3 | $21.54 | Quality Check | 6 | 1.5 | 12
4 | Barrel Jack | PJ-202AH | $0.69 | 4 | $2.76 | Software Engineering | 18 | 78 | 0
5 | AC to DC Converter | WSU120-2000 | $15.12 | 4 | $60.48 | Soldering | 25 | 5 | 16
6 | Solenoid Valve, DC 12V 1/2" Water Flow | ‎Walfront36atn8w5ph | $18.44 | 1 | $18.44 | Design Troubleshoot | 30 | 11 | 30
7 | Humidifier Filter | B07V4T5477 | $15.06 | 1 | $15.06 | Documentation | 58 | 39 | 53
8 | 10uF Decoupling Capacitor 0805 SMD | GMC21X7R106K10NT | $0.03 | 18 | $0.45 | Meetings | 21 | 13 | 15
9 | 0.1uF Decoupling Capacitor 0805 SMD | 0805B104K101CC | $0.05 | 18 | $0.90 | Miscellaneous | 5 | 5 | 20 | 24
10 | 120 Ohm Resistor 0805 SMD | 738-RMCF0805FT120RCT-ND | $0.62 | 2 | $1.24 | Total Hours | 283 | 155 | 220 | 24
11 | 500 Ohm Resistor 0805 SMD | CRCW08050000Z0EA | $0.10 | 1 | $0.10
12 | 200 Ohm Resistor 0805 SMD | AC0805FR-07200RL | $0.10 | 1 | $0.10
13 | Adjustable Voltage Regulator | LD1117SC-R | $0.78 | 2 | $1.56 | Category | Cost
14 | 1x3 Horizontally Mounted Socket (F) | SSW-103-02-G-S-RA | $0.96 | 2 | $1.92 | Materials and Parts | 680.95
15 | 1x2 Horizontally Mounted Socket (F) | SSW-102-02-G-S-RA | $0.71 | 2 | $1.42 | Total Labor | 34538.42
16 | Green Diode SMD 0805 | 350-2044-1-ND | $0.10 | 4 | $0.40 | Total Cost | 35219.37
17 | Thermal Stable Solder Paste | TS391AX-ND | $15.95 | 1 | $15.95
18 | Click Button | 2223-TS02-66-60-BK-100-LCR-D-ND | $0.10 | 1 | $0.10
 |  |  |  | Total = | $205.12
 |  |  |  |  |  |  |  | Member
 |  |  |  |  |  | Category | Andrew | Woojin | Jalen | Machine Shop
 |  |  |  |  |  | Total Hours | 283 | 155 | 220 | 24
 |  |  |  |  |  |  |  | Member
 |  |  |  |  |  | Category | Andrew | Woojin | Jalen | Machine Shop
 |  |  |  |  |  | Circuit Design | 72 | 2 | 50
 |  |  |  |  |  | PCB Design | 48 | 0.5 | 24
 |  |  |  |  |  | Quality Check | 6 | 1.5 | 12
 |  |  |  |  |  | Software Engineering | 18 | 40 | 0
 |  |  |  |  |  | Soldering | 25 | 5 | 16
 |  |  |  |  |  | Design Troubleshoot | 30 | 11 | 30
 |  |  |  |  |  | Documentation | 58 | 39 | 53
 |  |  |  |  |  | Meetings | 21 | 13 | 15
 |  |  |  |  |  | Miscellaneous | 5 | 5 | 20 | 24
 |  |  |  |  |  | Total Hours | 283 | 117 | 220 | 24

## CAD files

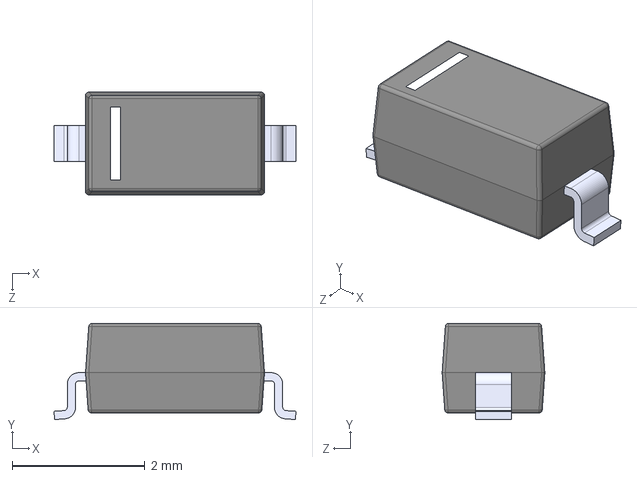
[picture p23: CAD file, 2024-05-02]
Course Files/KiCAD Files/KiCad Imported CAD/1N4148W-13-F - Diode/1N4148W_13_F/1N4148W-13-F.step
3.65 x 1.45 x 1.55 mm

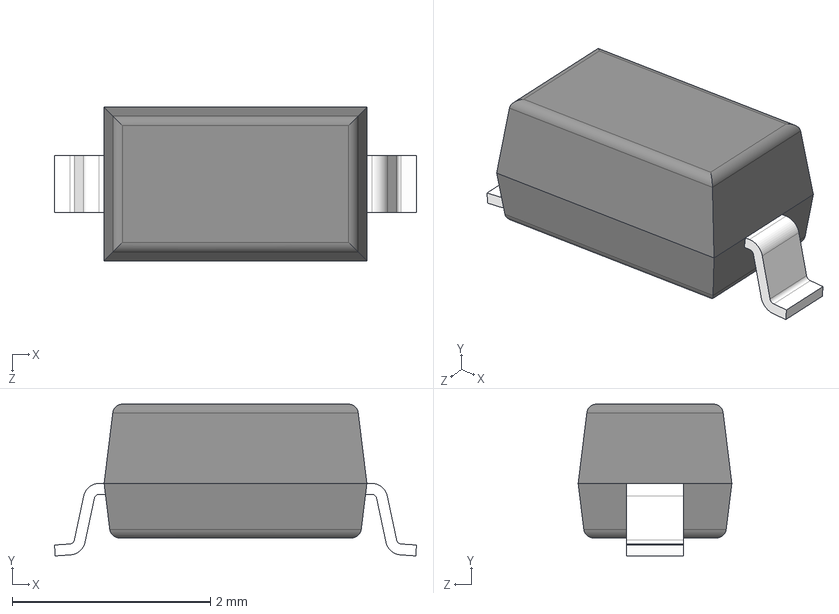
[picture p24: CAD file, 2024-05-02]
Course Files/KiCAD Files/KiCad Imported CAD/1N5819HW-7-F - Diode/1N5819HW_7_F/1N5819HW-7-F.step
3.65 x 1.53 x 1.55 mm

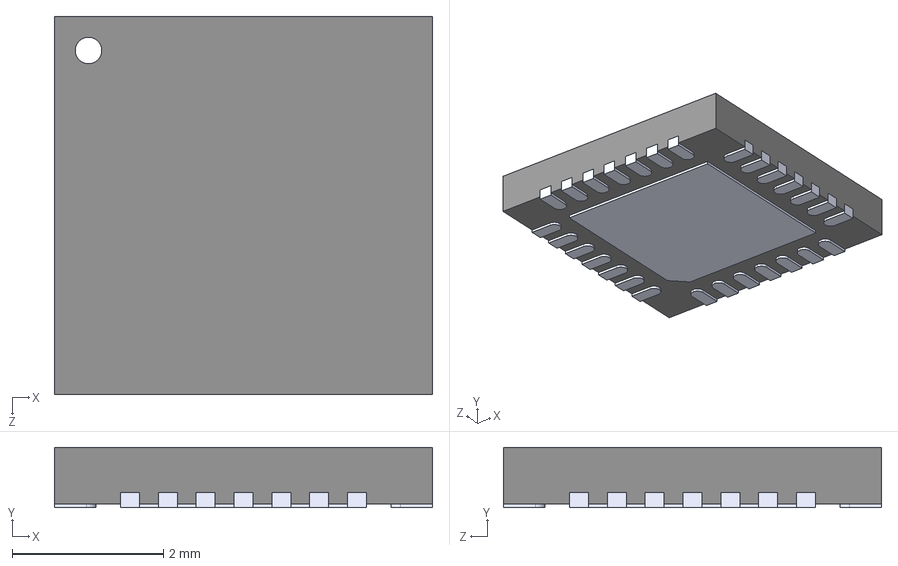
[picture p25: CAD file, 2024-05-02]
Course Files/KiCAD Files/KiCad Imported CAD/CP2102N-A02-GQFN28 - UART Chip/CP2102N_A02_GQFN28/CP2102N-A02-GQFN28.step
5.00 x 0.8 x 5.00 mm

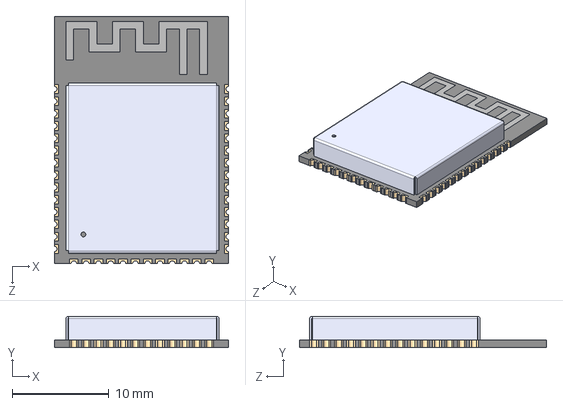
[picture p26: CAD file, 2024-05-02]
Course Files/KiCAD Files/KiCad Imported CAD/ESP32_S3_WROOM_1_N8 - ESP32/SnapEDA/ESP32-S3-WROOM-1-N8/ESP32-S3-WROOM-1-N8.step
18.0 x 3.25 x 25.5 mm

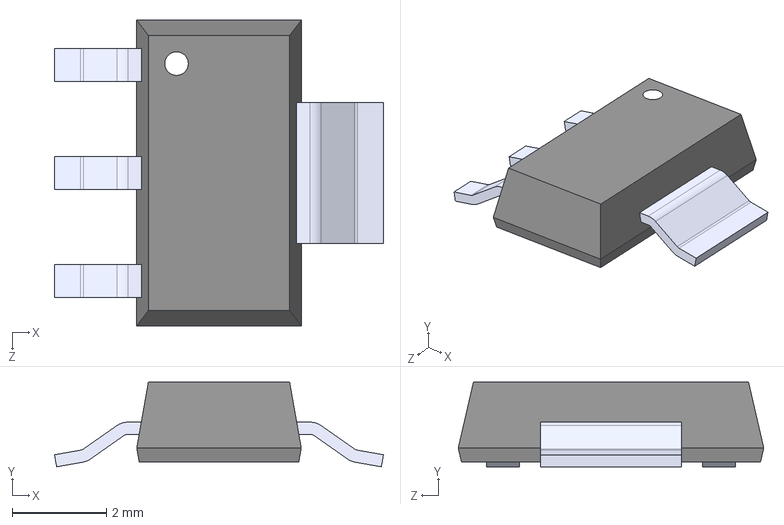
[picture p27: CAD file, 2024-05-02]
Course Files/KiCAD Files/KiCad Imported CAD/LDL1117S33R - Voltage Regulator/SnapEDA/LDL1117S33R/LDL1117S33R.step
7.00 x 1.80 x 6.50 mm

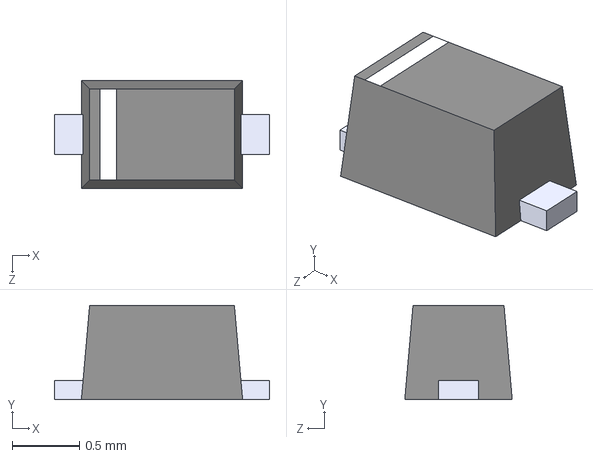
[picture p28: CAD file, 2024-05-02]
Course Files/KiCAD Files/KiCad Imported CAD/LESD5D5_0CT1G - Diode/LESD5D5/LESD5D5.0CT1G.step
1.60 x 0.7 x 0.8 mm

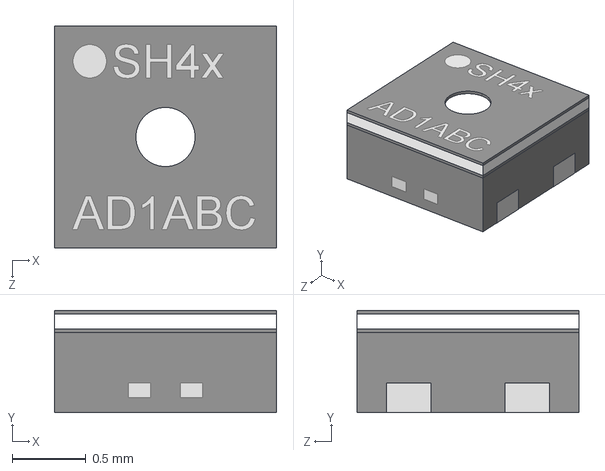
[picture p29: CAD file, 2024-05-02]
Course Files/KiCAD Files/KiCad Imported CAD/SHT45_AD1B_R3 - Humidity Sensor/SHT45_AD1B_R3/SHT45-AD1B-R3.step
1.50 x 0.691 x 1.50 mm

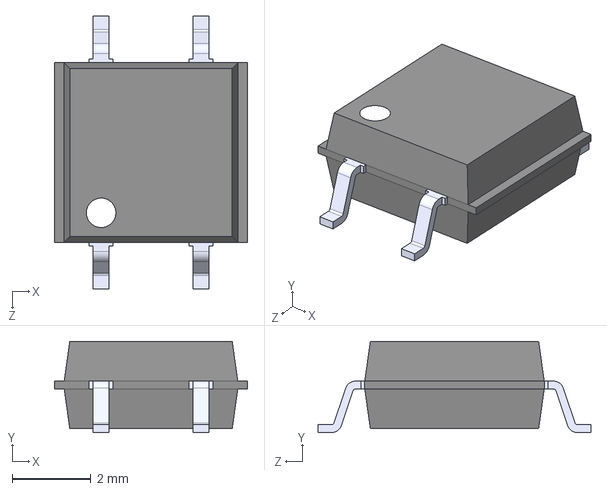
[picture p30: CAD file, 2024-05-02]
Course Files/KiCAD Files/KiCad Imported CAD/VOM617AT - Optocoupler/VOM617AT/VOM617AT.step
4.92 x 2.32 x 6.95 mm

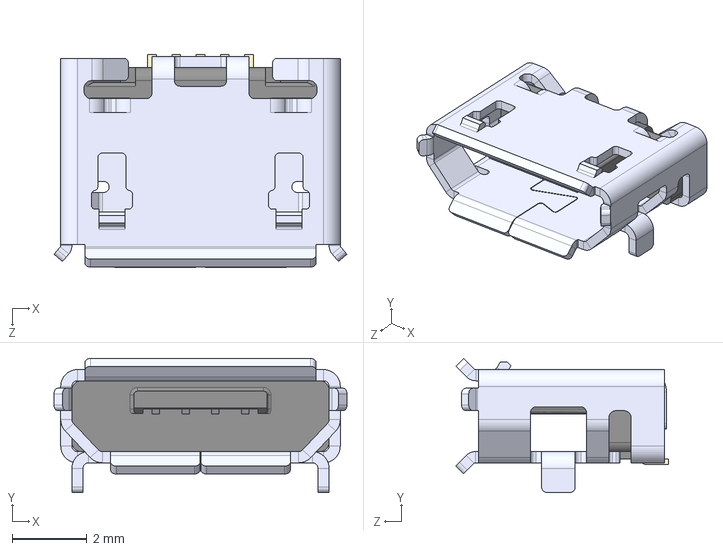
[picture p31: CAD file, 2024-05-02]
Course Files/KiCAD Files/KiCad Imported CAD/10118193-0001LF - Micro USB/10118193_0001LF/10118193-0001LF.step
7.86 x 3.60 x 5.71 mm

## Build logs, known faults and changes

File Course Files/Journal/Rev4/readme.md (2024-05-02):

# Tuesday, February 06, 2024

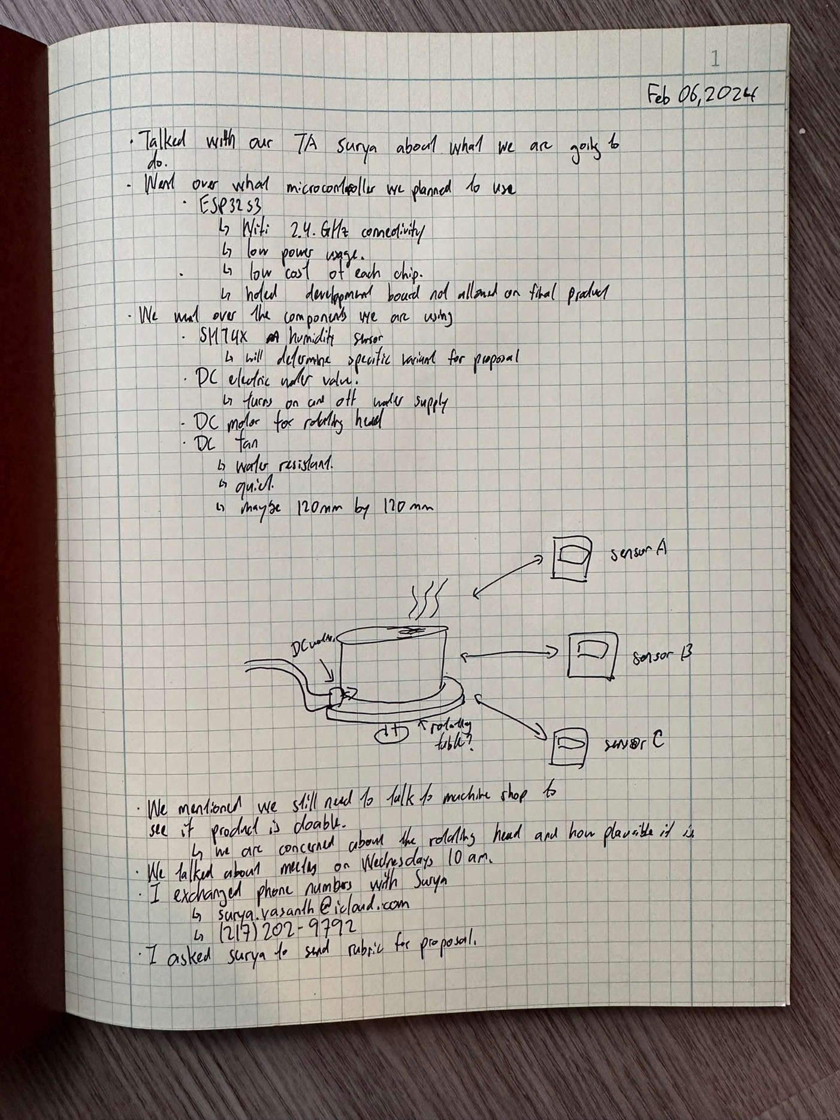
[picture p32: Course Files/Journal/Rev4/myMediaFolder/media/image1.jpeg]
{width="6.361111111111111in"
height="8.481481846019248in"}**R**

# Wednesday, February 07, 2024

Today, we talked to the machine shop. Prior to going, I made a
PowerPoint describing what we wanted to do. In the PowerPoint, I
included some images, such as a visual aid, and images of parts that we
may use.

In the machine shop, Gregg told us that they will not build a new
humidifier for us. However, they will be happy to modify one from
Amazon. He suggests that we get one that is simple, with a manual on-off
function. Also, it is preferred that it is square, so that it will be
easier to mount things without leaks.

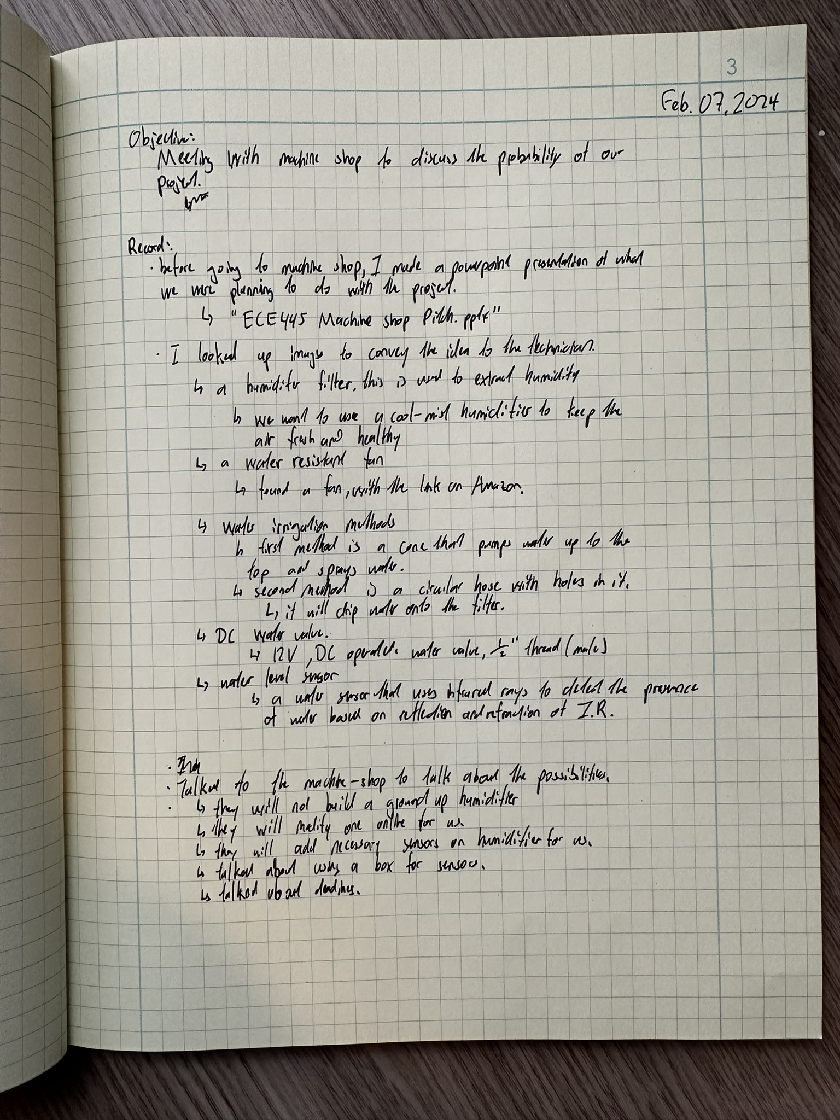
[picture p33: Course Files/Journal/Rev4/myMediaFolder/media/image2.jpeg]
{width="6.5in"
height="8.666666666666666in"}**\
**

# Thursday, February 08, 2024

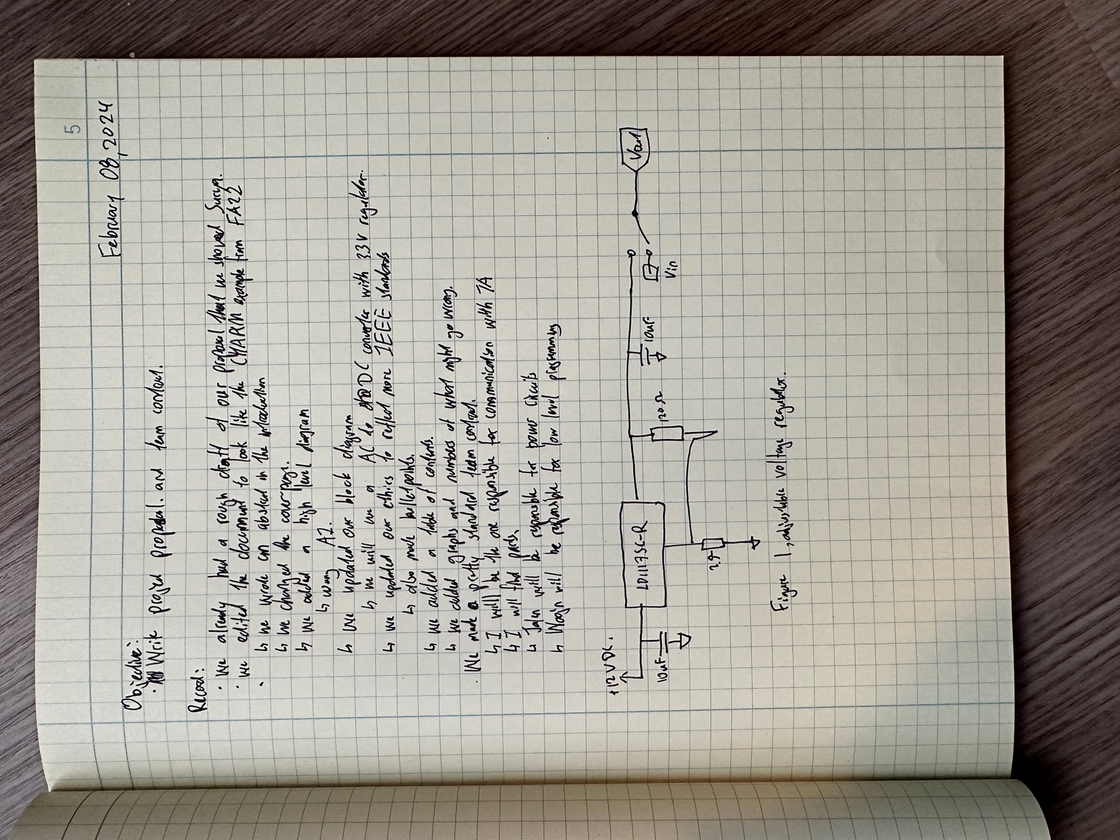
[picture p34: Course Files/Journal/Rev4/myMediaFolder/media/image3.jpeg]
{width="8.36111111111111in"
height="6.270833333333333in"}

# Wednesday, February 14, 2024

**Objective: Meeting with Surya, discuss machine shop, discuss using GitHub for journal**

Today we had a meeting with Surya. We went over our meeting with the
machine shop. I told Surya that we are not able to have a rotating head
as originally proposed. The reason is that the machine shop does not
want to build a humidifier ground up for us. Also, the machine shop just
wants to modify a humidifier to fit our needs. Surya told us to think of
another high level to fill in for the rotating head. We said that we may
do automatic water refilling. Surya also reminded us to sign up for the
design review, which is opening on Friday.

I also asked Surya if, instead of writing physically on a journal, I can
change to GitHub. He says yes, and to make sure to submit the journal at
the end of the semester.

# Thursday, February 15, 2024

**Objective: Pick part with Jalen, what sensor and ESP32 to use**

I worked to Jalen picking out parts for our project. We needed to figure
out what water level sensor to use and what humidity sensor to use. We
did a lot of research to see what sensors met our needs in price and in
function. Also, we had to decide on what microcontroller we should use.
There are many versions of the ESP32, and we need to decide on one.

After doing research, we are leaning on using the ESP32-S3-WROOM-1-N8.
The reason for this is because we don't need the extra DRAM from other
versions, and the S3 has a UART-USB chip.

# Friday, February 16, 2024

**Objective: Text Surya about buying ESP32 board**

Today, I texted Surya about ordering a development board. He says that
there are some ESP32 development boards that we can check out in ECE445.
He will get back to me about it next week. I told Surya that we will
check it out in our meeting next week.

# Tuesday, February 20, 2024

**Objective: Meet with Surya, discuss proposal, place order for sensor, rent ESP32 Dev Board**

Today we met with Surya. We talked about our progress with the project
and the due dates coming up. Surya told us about our scores for our
proposal report. It was a bit low, but he says we can still make changes
to it and submit it on Friday. He says that the other TA who graded the
paper was strict about the scores. We were missing some requirements,
which we will update. He also told us to look at CHARM's paper. We
originally did that too, but this time we will also reference the
rubric. We will continue working on the project. We told Surya we are in
the process of picking parts for the project.

We told Surya that our new high level will be to read the water level
and automatically fill the water tank.

Today, we also placed the order for our water level sensor. We chose the
Optomax Digital Liquid Level Sensor as it seems easy to work with and is
well waterproofed. The only downside is that it is \$24.99. We only
ordered one to make sure it works.

Aside from that, we borrowed 4 ESP32-S3 development boards from ECE445.
Surya helped sign it out for us. Jason asked why we needed so many
boards. We told Surya that I needed two to work on two ESP32's
communicating over Wi-Fi. Jalen needs one to work on the water level
sensor and motor controller. Woojin needs one for the humidity sensor.

# Wednesday, February 21, 2024

**Objective: Write design document, make table for parts and labor**

We worked on our design document today. Woojin, Jalen, and I had a Zoom
call. We worked on the paper together. We wonder why this class takes so
much time on the writing. It is more than 4 credit hours. We were able
to transfer a lot of our paper from the proposal over to the design
document. We also made an estimated labor table, as well as the
estimated parts list as shown below:

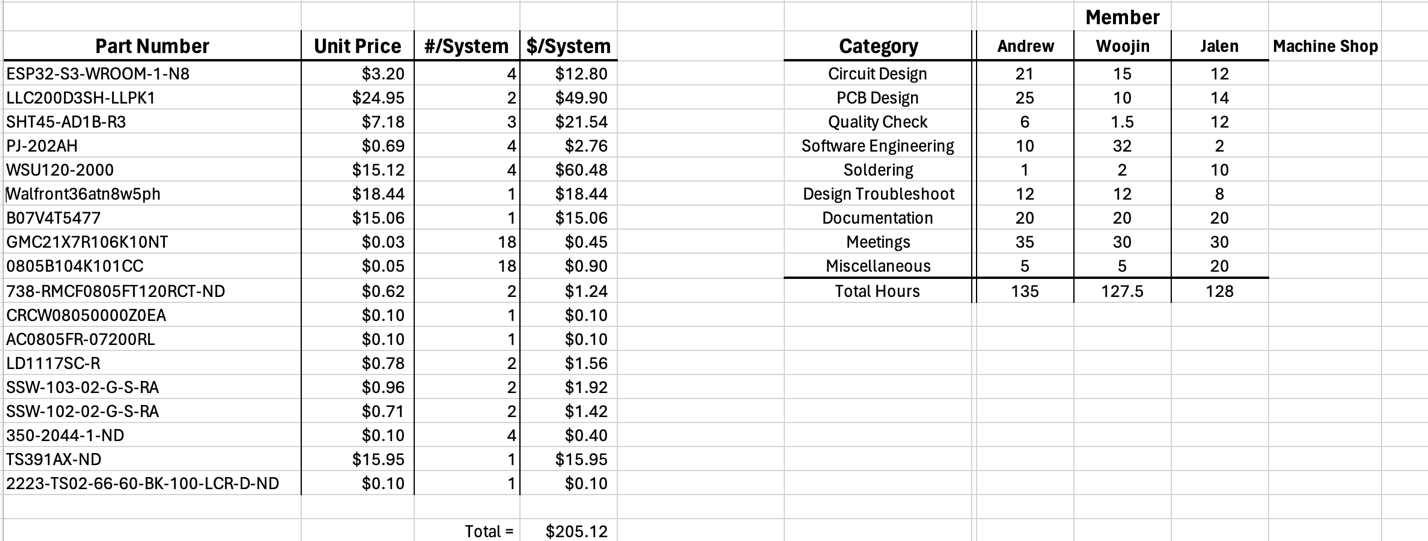
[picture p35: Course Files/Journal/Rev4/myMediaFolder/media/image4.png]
{width="6.5in"
height="2.4618055555555554in"}

# Friday, February 23, 2024

**Objective: Update proposal and rebsubmit**

Today, I worked on updating the proposal. I updated the block diagram on
the proposal as well and the citations.

Later in the day, I started working on the PowerPoint for the design
review on Wednesday next week.

# Monday, February 26, 2024

**Objective: Ask Surya if schematics are needed for design review**

Today, I texted Surya if we needed schematic diagrams on our
presentation. He says that we do not. So, I did not make any edits to
our presentation.

# Wednesday, February 28, 2024

**Objective: Present design review, meet Surya.**

Today, we the design review. There was no meeting for this week. Thanks
for Surya, we dressed up for the design review and came prepared for the
presentation. Professor Schuh did not ask us many questions. The only
suggestions that he had were to include temperature in the algorithm for
the humidifier, update the block diagram, and looks at built in
humidifiers in houses for inspiration. Surya says that we were the first
team to get full marks on the professionalism category.

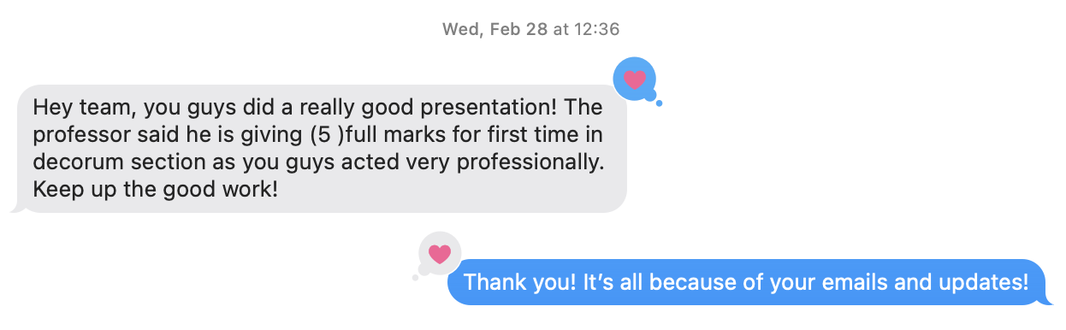
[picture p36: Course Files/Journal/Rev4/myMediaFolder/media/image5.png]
A chat message with text Description automatically generated with medium confidence
{width="6.5in"
height="2.013888888888889in"}

We went to a peer review, and they just read off their Google Doc. I am
glad we make a PowerPoint.

I also made some edits to the block diagram. I updated the signals for
the DC motor controller, as the ones in the proposal did not make sense.
I also made the data and power lines more readable with new colors
added.

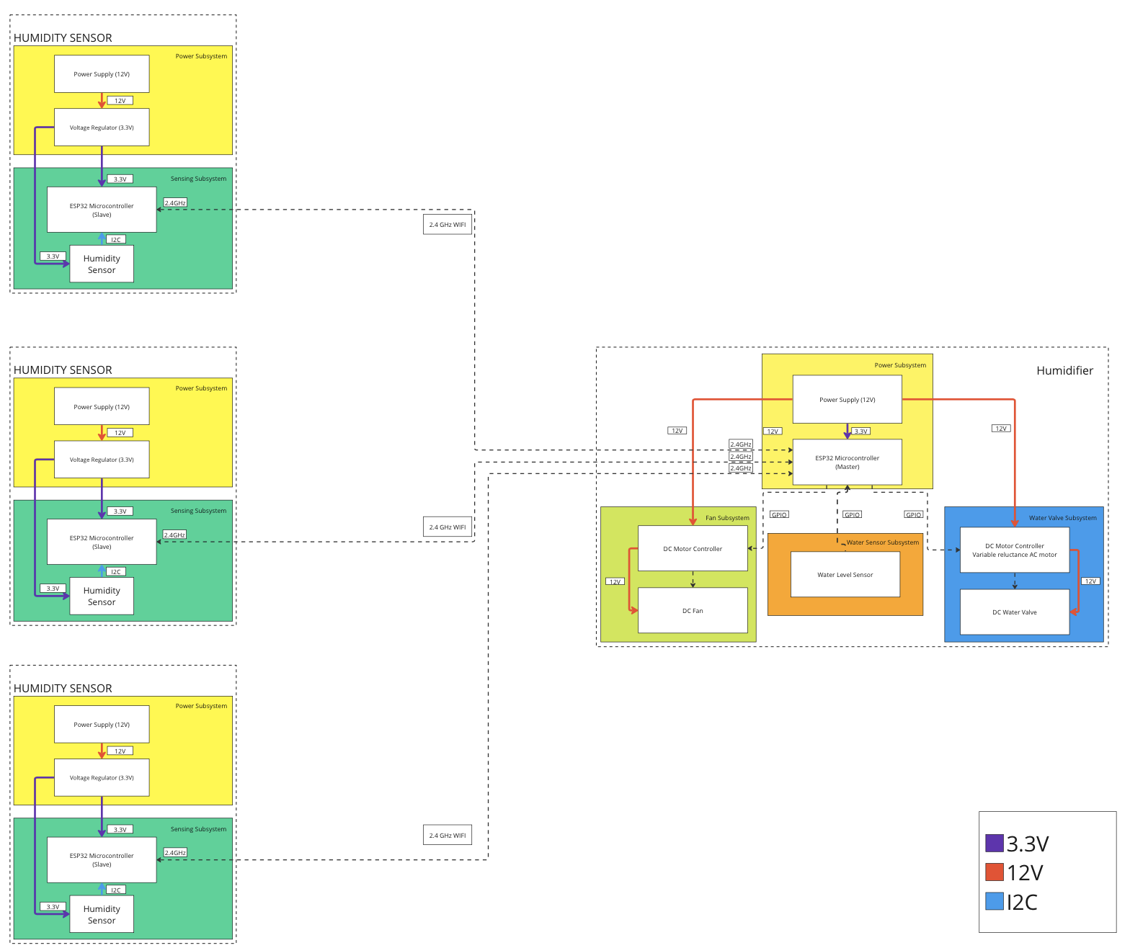
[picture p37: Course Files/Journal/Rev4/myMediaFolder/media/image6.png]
{width="6.5in"
height="5.455555555555556in"}

# Sunday, March 03, 2024

**Objective: Work on PCB for sensor subsystem**

Today, I began working on the PCB schematic for the sensor subsystem.
Yesterday, Woojin showed me his completed work on the Adafruit SHT45
development board. He showed me the output and proved that the ESP32 can
communicate with the SHT45 and read data from it.

Because we want to make it to the first PCB order group (coming
Tuesday), I will make a draft of the PCB schematic today.

The first thing that I did was find the ESP32-S3 microcontroller on our
ESP32-S3 development board. Doing some research, I believe that it is
the ESP32-S3-VROOM-1-N8. I downloaded the CAD file on Digikey, so that I
can import it to KiCAD.

Next, I looked at the SHT45 sensor. I went on Sensirion's website and
looked through the documentation. They had a sample circuit. I think I
will base my schematic on that, as the Adafruit development board has a
lot of "fluff" on it. I also downloaded a CAD model on Digikey for the
SHT45 sensor. I will be using the SHT45-AD1B-R3 sensor.

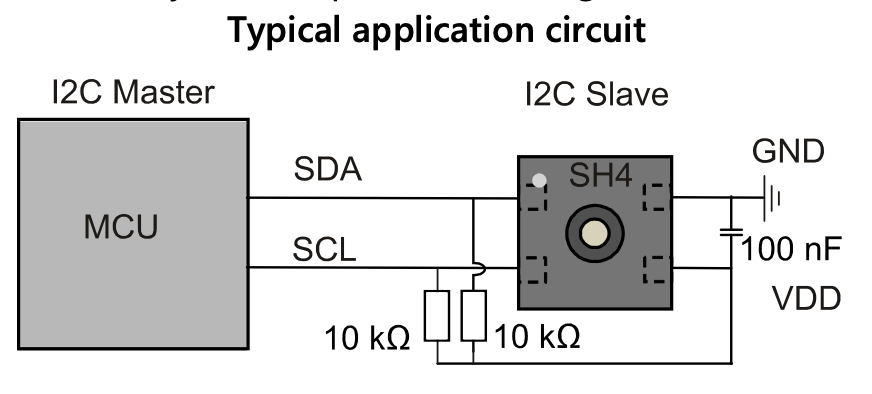
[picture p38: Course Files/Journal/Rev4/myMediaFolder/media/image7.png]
A diagram of a device Description automatically generated
{width="6.055555555555555in"
height="2.6829199475065617in"}

Aside from the two components mentioned above, we also need the power
components. I will be using a fixed 3.3V voltage regulator that accepts
up to 18V input. Looking through the documentation, I decided to choose
the LDL1117S33R chip.

For the voltage input, I will be inputting 12V via a barrel jack to the
PCB board. The input will be from a WSU 120-2000 AC/DC wall mount. The
barrel jack will be a PJ-202AH jack.

We will also have decoupling capacitors throughout the circuit for the
signals.

There are some issues with the voltage regulator on KiCAD. The reason is
that there are two 3.3V output pins. It is not exactly passing the
Inspection Test. If it still does not work, I will simply change to a
different voltage regulator.

Aside from that, I still need to wire the BOOT and RESET buttons, as
well as the USB bridge.

I found a good link from Espressif regarding wiring the ESP32. It has
the USB-UART and USB-Bridge wiring too, as well as the buttons. It is
the same ESP32-S3-Devkit-C board with the VROOM-1. I was going to do the
USB-UART, but looking at the schematic, it looks like it has too many
components, and is difficult. I will probably figure out how to program
the USB-Bridge instead.

# Monday, March 4, 2024

**Objective: Work on PCB and improve yesterday's design**

Today, I will continue working on the PCB design. I will working on the
micro-usb-b part.

Looking at the Espressif schematic, I can see that the micro usb
provides a 5V connection. We will not be using the 5V, therefore, I will
be omitting that. I am following the Espressif schematic below to do
most of the PCB schematic. I hope to use the same parts also, even
though they may be from China.

I am getting some errors for the ESP32 footprint. There are some
through-holes in the middle of the chip. Talking to Peter, a friend from
ECE395, he says that they are for heat dissipation. I can ignore it or
remove the holes in the footprint editor. For the first revision of this
board, I will remove it. This is the prevent extra costs. I will talk to
Jason about the holes.

I have finished the prototype. I have submitted the board to PCB-Way,
and it passed all tests and is ready for production.

# Tuesday, March 5, 2024

**Objective: Turn in PCB design, meet Surya.**

Early today, I finished the schematic and PCB layout. I will review it
with Jalen this afternoon before we email the file to Surya.

During the meeting with Jalen, we did not find any issues with the
schematic. Everything looks ok.

I have sent the email to Surya.

In the meeting with Surya, we also told him our plan for Spring Break.
We hope to finish the humidifier subsystem's PCB over Spring Break.
Surya says he is quite happy with our progress on our PCB when compared
to the other groups.

Order some parts for PCB, primarily BJT and Diode from China. It will
take two weeks to arrive, so it will arrive on time after Spring Break.

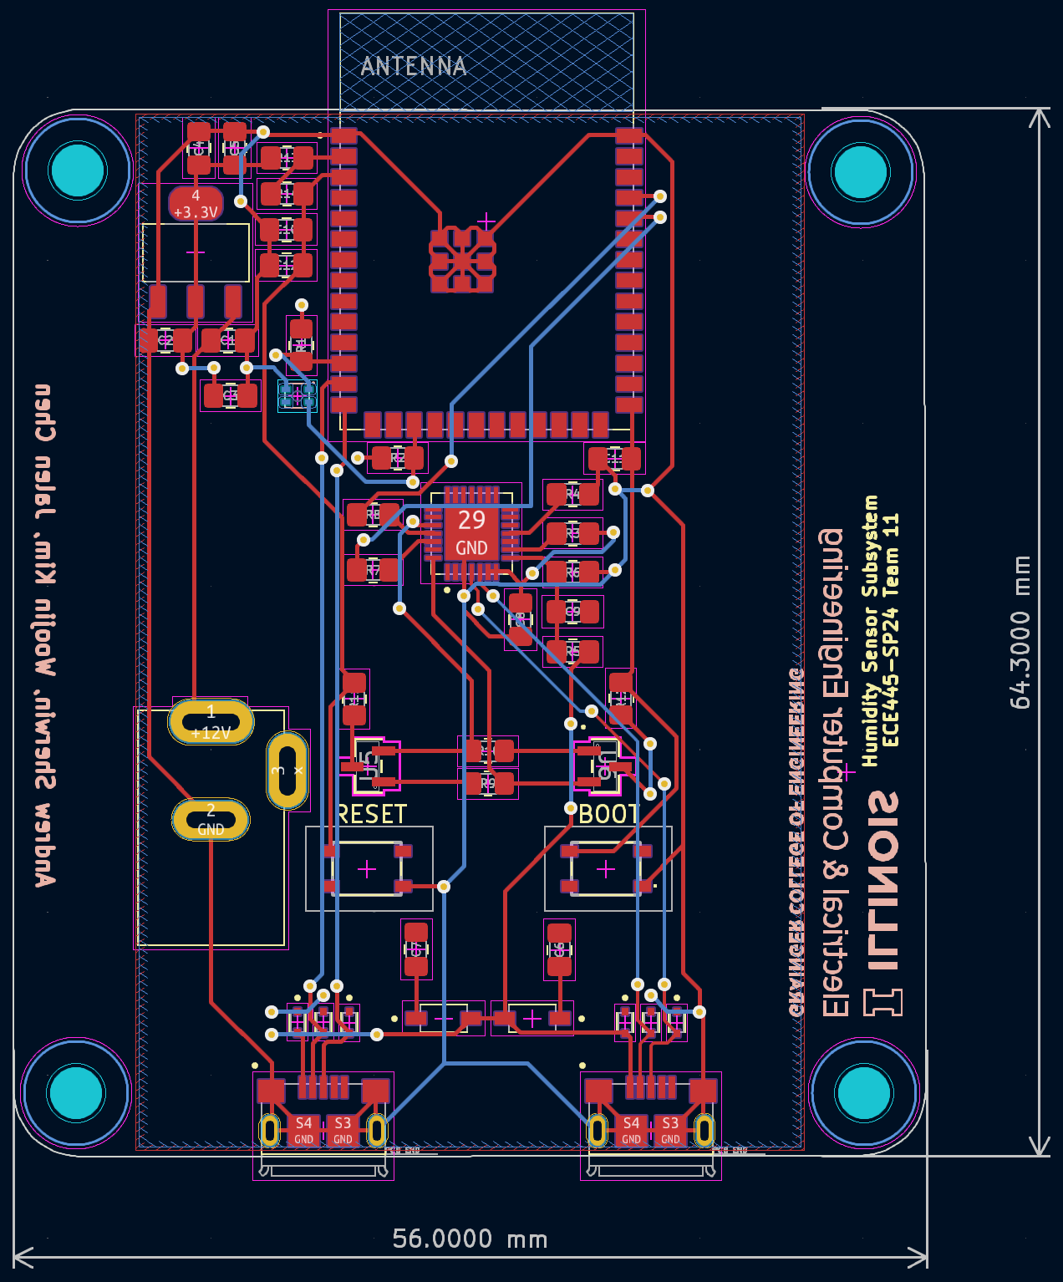
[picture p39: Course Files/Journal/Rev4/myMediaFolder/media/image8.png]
A blueprint of a circuit board Description automatically generated
{width="6.5in"
height="7.838888888888889in"}

# Monday, March 18, 2024

**Objective: Work on Humidifier PCB, talk to Jalen**

Today, I am working with Jalen on the humidifier PCB. We have previous
communicated on what needs to be done. Right now, my first problem is
converting my KiCAD 8.0 file t0 KiCAD 7.0. The reason is because KiCAD
8.0 is less than a month old, and it has [a lot]{.underline} of bugs.

I tried finding ways to directly convert the files, and it seems like it
is not possible. Also, the symbol and footprint library has already been
converted to KiCAD 8.0 version. So, I will have to re-import all the
symbols and footprints again. This will be a bit tedious. I think I will
have to redraw the schematic and PCB again.

After redrawing the circuit from the sensor subsystem, I fixed any
errors.

Next, I helped Jalen with the relay. He said that we needed an
optocoupler. This is used to prevent noise. I did some research and
decided "why not". It was a bit difficult finding parts for the
optocoupler, as we were not sure what to look for. Furthermore, most of
the parts on Digikey that we clicked on did not have EDA files. I ended
up going to SnapEDA and searching for optocoupler and clicking the first
item. The first was the VOM617AT. The specs looked ok, and it had a
stock of over 6000 on Digikey, so it must be decent. I suggested it to
Jalen. He thinks we should try it out.

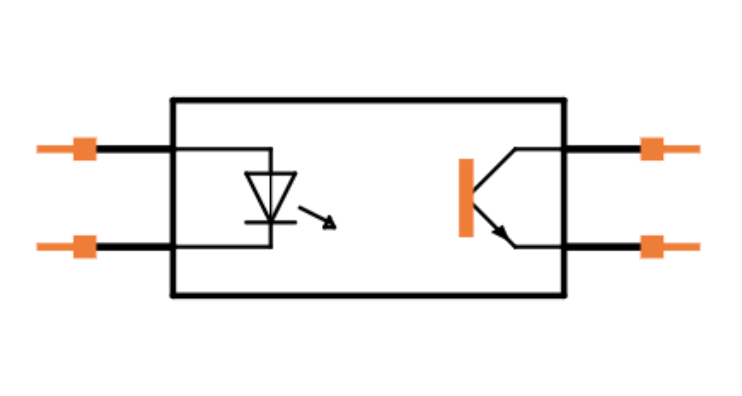
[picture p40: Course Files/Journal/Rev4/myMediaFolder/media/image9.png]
A diagram of a circuit Description automatically generated
{width="5.152777777777778in"
height="2.75in"}

After more discussion, it seems like Jalen's initial understanding of
what the relay does was flawed. He thought that the relay also provided
power for the ESP32. However, it is the ESP32 that powers the relay. The
120V on the end of the relay does not go to the low power side.

We will be using a premade transformer to power the ESP32. We decided
that it was not worth the time and trouble to make one. We will be using
the EPS-15-12 120V AC to 12V DC transformer. I will also connect the DC
end to a barrel jack for the PCB.

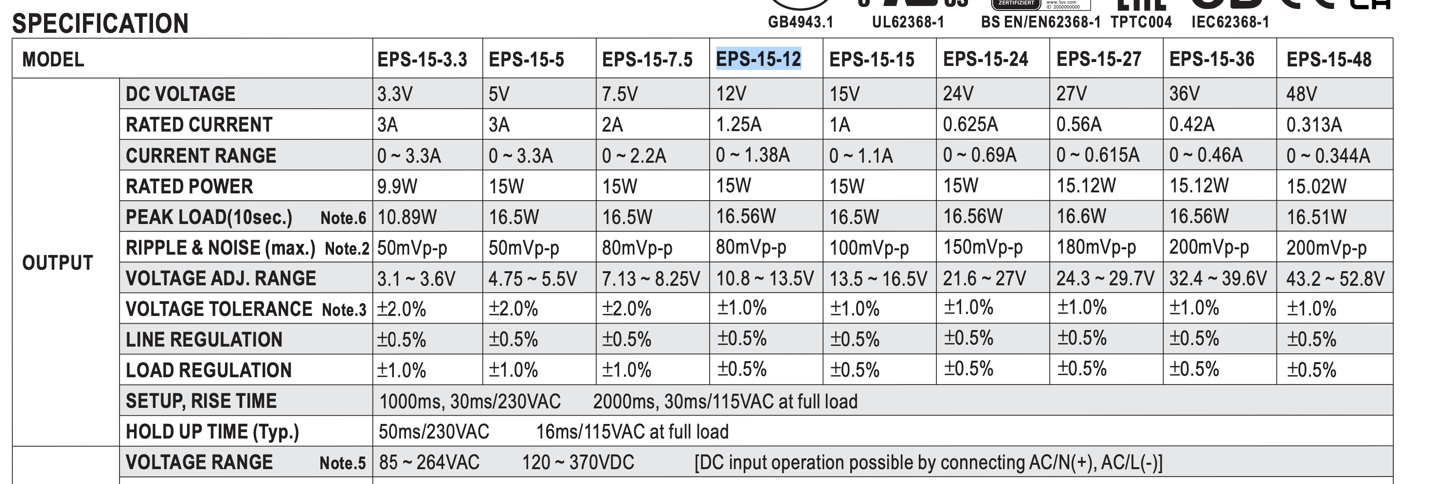
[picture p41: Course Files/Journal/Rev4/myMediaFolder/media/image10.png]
A table with numbers and symbols Description automatically generated
{width="6.5in"
height="2.2006944444444443in"}

Order some more parts from Digikey for the humidifier PCB. Total was
around \$67.00.

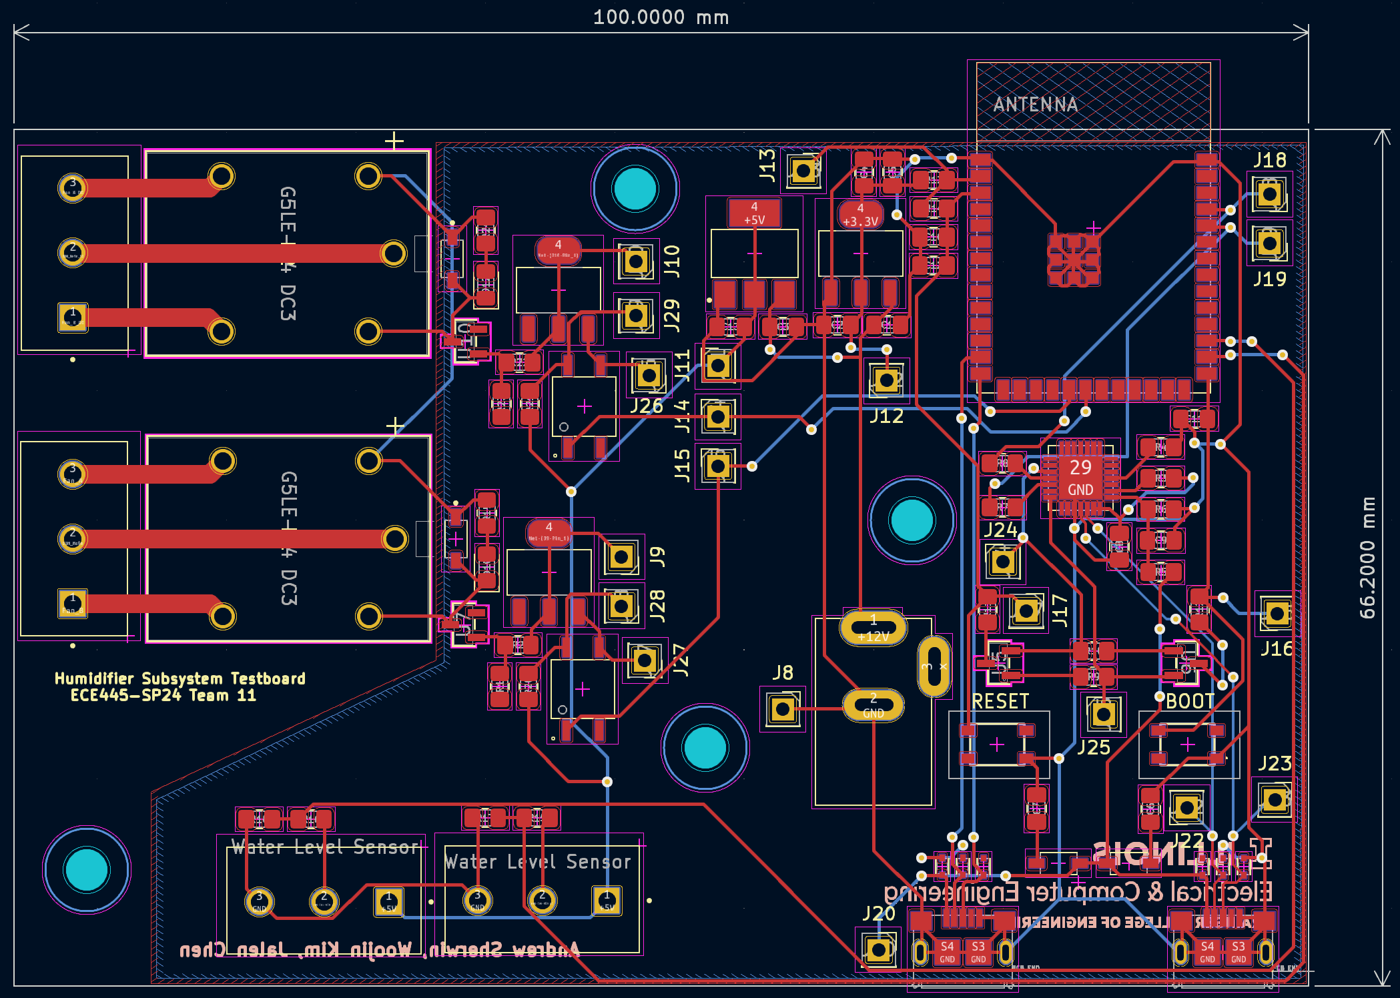
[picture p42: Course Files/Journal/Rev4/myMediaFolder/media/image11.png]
{width="6.5in"
height="4.634722222222222in"}

# Tuesday, March 19, 2024

**Objective: Work on humidifier PCB, turn in PCB, meet Surya, discuss water valve**

Today, when talking to Jalen about the water valve, we discovered that
our water valve might not work for the demonstration. The problem is
that the water valve requires a minimum pressure for it to activate. It
does not work by gravitational water pressure. We will have to find a
different valve that has no pressure rating.

We found a new valve on Amazon that require little to no pressure to
work. The downside is that this controller uses quick connect. Also, we
don't know how much pressure will be during the demo.

This new valve requires 12V DC to power. Originally, we were going to
use some kind of motor controller to control it. However, it occurred to
me that the relay could use 12V DC. This will be perfect for the ESP32
sending 3.3V activation signal, activating the switch, and sending 12V
to the motor.

The only uncertain thing is how does the valve close. Looking at the
description, it seems like the valve will close on its own. We will try
it out later.

When meeting with Surya today, we told him about our progress. He told
us that we should start talking to the machine shop. I told him that I
will do it this week. He says that the machine shop should be working on
our parts now. However, he is still happy that we are making good
progress compared to the other teams.

I told Jalen to help create a spreadsheet of the parts that we have
ordered and the parts that we need to still order. The spreadsheet
should have a total of parts needed for each PCB. Also, the list should
have vendor links of where the parts are from.

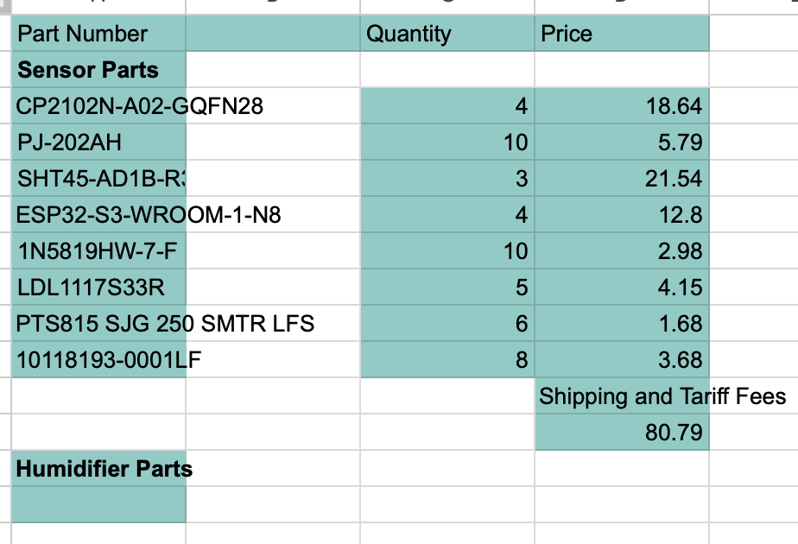
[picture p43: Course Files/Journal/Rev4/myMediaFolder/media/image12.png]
{width="6.416666666666667in"
height="4.375in"}

I updated the block diagram once more. This time, the block diagram has
electrical relays instead of the motor controller. This is because I
think the design will be more modular. When changing this, I also
updated the GPIO lines. The idea behind the relays is when the switch is
activated, the circuit for the water valve and the humidifier will be
complete. As a result, they turn on.

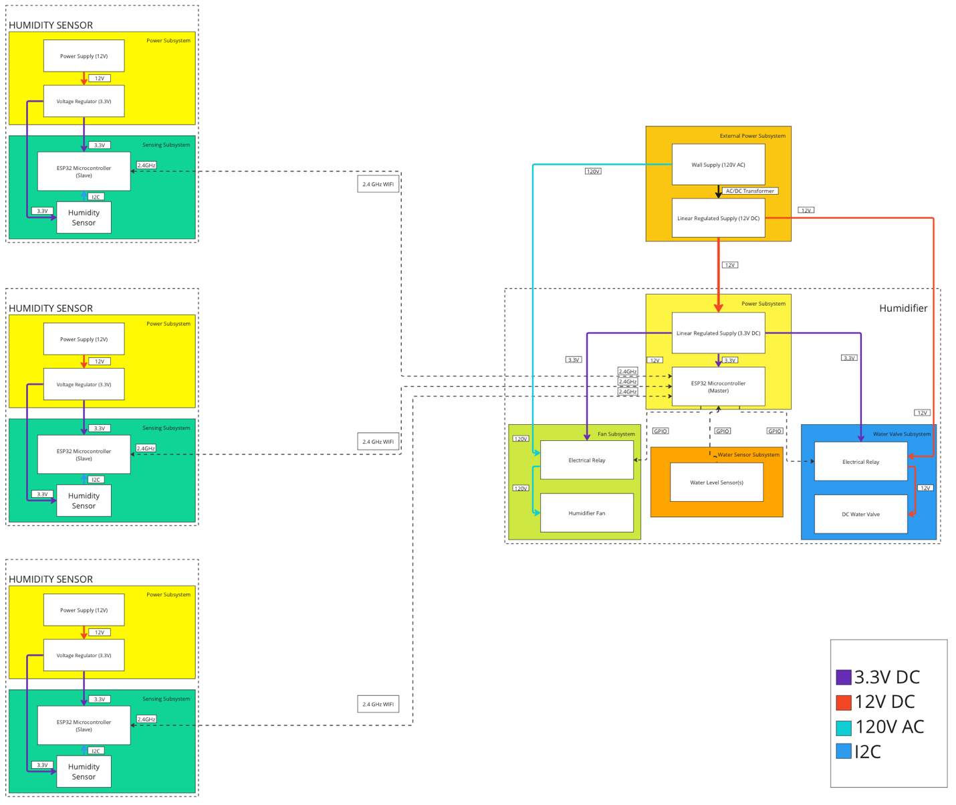
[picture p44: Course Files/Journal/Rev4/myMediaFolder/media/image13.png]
{width="6.5in"
height="5.469444444444444in"}

# Thursday, March 21, 2024

**Objective: Talk to machine shop**

Today, I brought the humidifier and PCB parts to the machine shop. I
also drew some diagrams to show the machine shop what needs to be done.

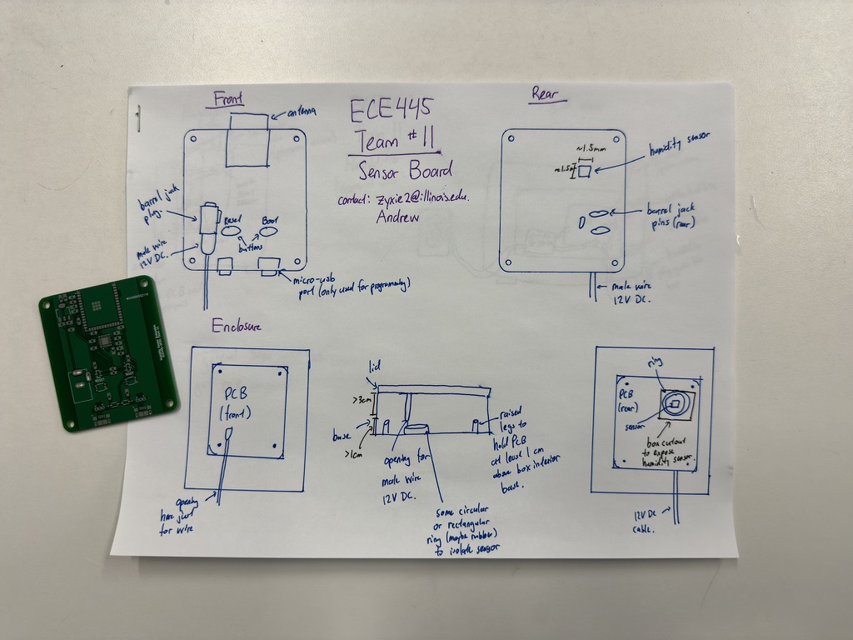
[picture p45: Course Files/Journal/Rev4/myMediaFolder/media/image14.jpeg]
{width="6.5in"
height="4.875in"}

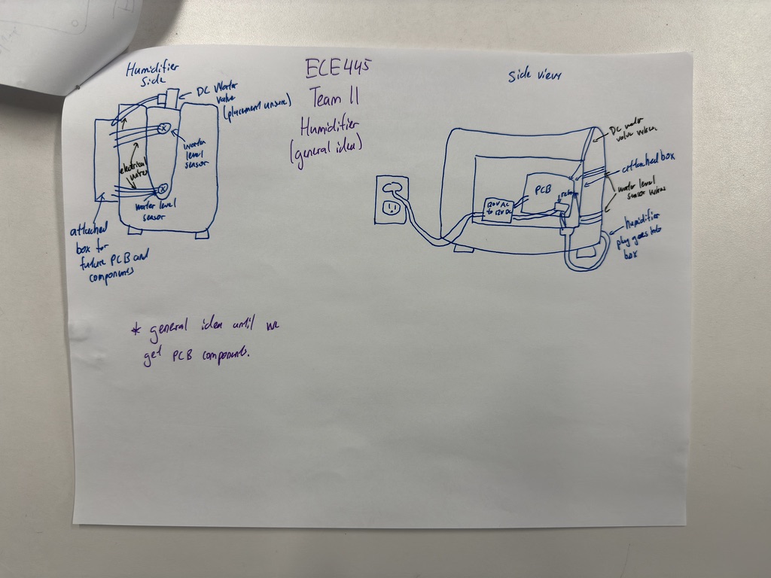
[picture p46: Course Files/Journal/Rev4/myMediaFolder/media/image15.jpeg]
{width="6.5in"
height="4.875in"}

I think that Gregg understands the idea. However, because we are still
waiting for parts, he cannot begin working on it yet. Gregg requested
that I give him a sample of our PCB and the water valve. He says he will
be on vacation for a week starting the coming Monday. I told him I will
get it to him tomorrow, as the valve is arriving tomorrow.

Jalen and I continued to work on the parts list. Below is the updated
list. It consists of parts for the sensor and the humidifier subsystem:

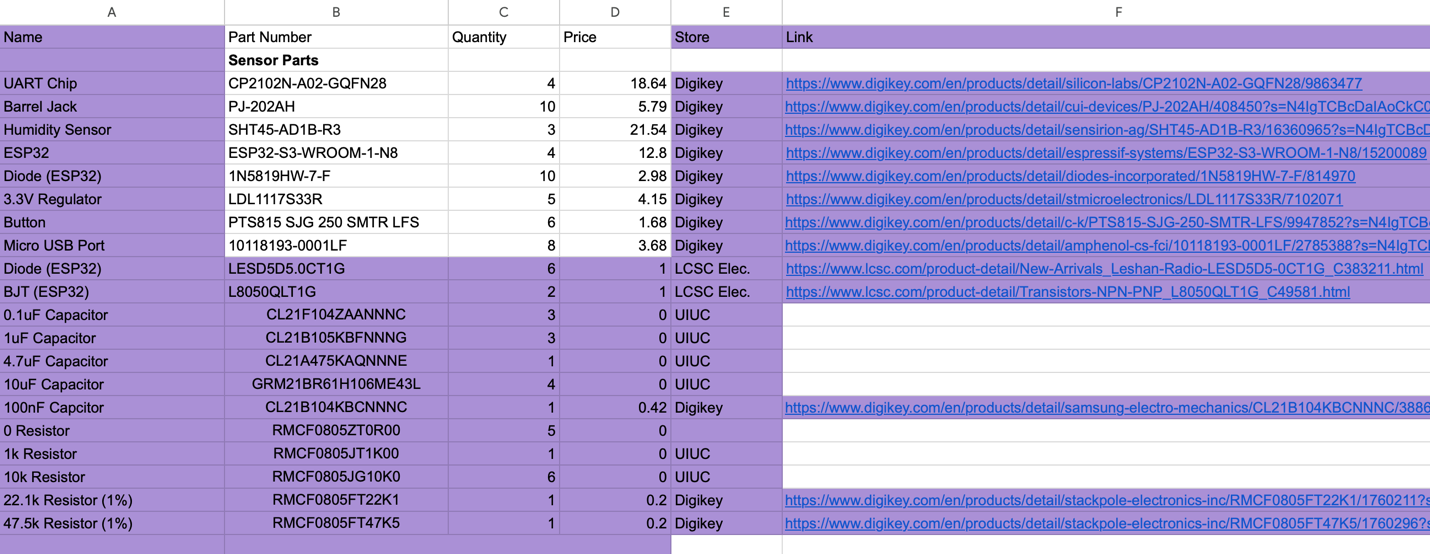
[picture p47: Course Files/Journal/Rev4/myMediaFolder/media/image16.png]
{width="6.5in"
height="2.515972222222222in"}

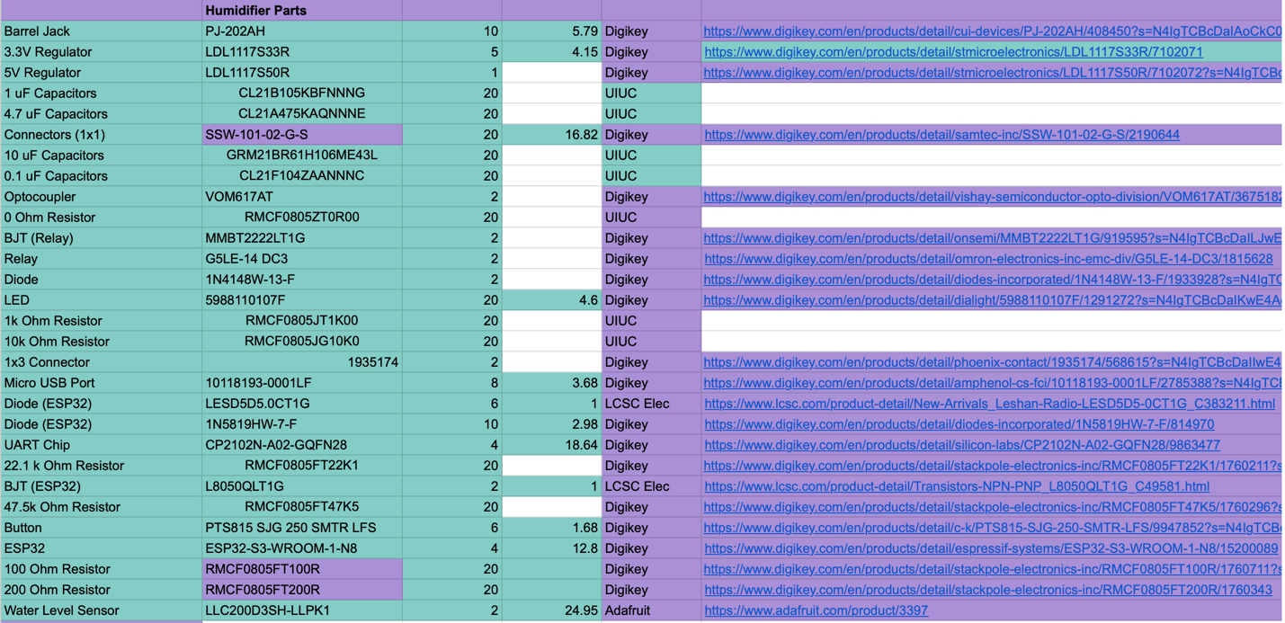
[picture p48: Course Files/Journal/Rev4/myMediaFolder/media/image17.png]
{width="6.5in"
height="3.154861111111111in"}

# Friday, March 22, 2024

**Objective: Parts did not arrive**

The valve did not arrive today yet. I think some motherfucker stole my
package. I went to see Gregg to report the bad news, and apparently, he
had already left for his vacation!?

# Sunday, March 24, 2024

**Objective: Woojin got ESP32s to send data**

Today, Woojin announced that he got the communication between two ESP32s
to work. The original plan was to control the LED of one ESP32 from
another ESP32 over 2.4GHz Wi-Fi. However, Woojin went above and beyond
by being able to send the SHT45's data to another ESP32 and being able
to read it.

# Monday, March 25, 2024

**Objective: Order parts from funding**

Order parts for humidifier subsystem. I think that this will be the last
order from the \$150.00 budget that we have. This order is mainly UART
chips and plugs for the transformer that we missed.

# Tuesday, March 26, 2024

**Objective: Meet Surya, test water valve**

Today, the water valve arrived. I tried to test it. However, initially,
I was confused on how it works. I can hear it clicking, but looking in
the hole, I did not see the valve opening. As a result, I took it apart
and found the below:

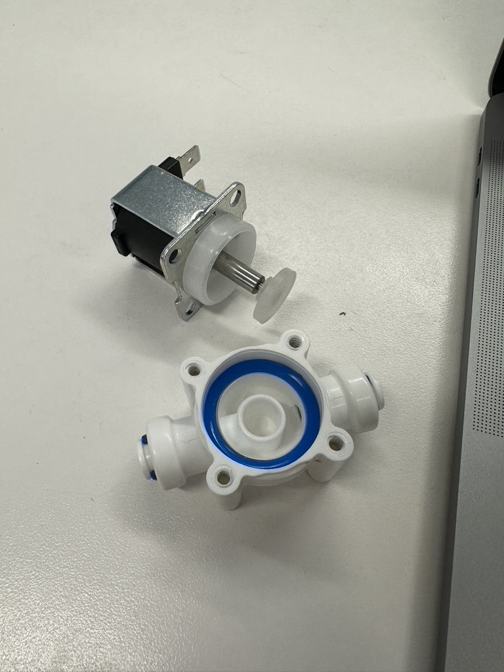
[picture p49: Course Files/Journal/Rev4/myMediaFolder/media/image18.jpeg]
A small white and blue device Description automatically generated
{width="5.536082677165354in"
height="7.381443569553806in"}

As seen in the picture, this is not really a valve, but a plunger. It
works with a coil. When there is a current through the coil, a magnetic
field will be created and the valve will be sucked upwards, thus opening
the valve. The valve is normally closed when there is no current going
to it. The manufacture's specification says that it draws around 4.8W.
This means that there is 0.4 amps flowing through it.

$$4.8W = I*12V$$

$$I = 0.2A$$

This should be enough for our applications. The only worry is that the
seal might not be great. However, since our real valve will not be like
this, as this is an "unpressured valve", it will not be a real problem.

We met with Surya; I told him to good news about Woojin getting the
sensors to send data over Wi-Fi. Surya tells us to contact the machine
shop to see how progress is. Surprisingly, we still have around \$30 of
budget left. We may use it to order our second water level sensor.

# Wednesday, March 27, 2024

**Objective: Order parts for humidifier, determine power input for humidifier subsystem**

Today I had to order some parts for the humidifier subsystem. I had to
figure out a way to power the PCB, and I thought that the best way would
be to use a switching regulator. I thought about making our own power
supply, however, with the limited cost and time, I think it would be too
difficult. Also, it is highly unlikely that we can build one for cheaper
than buying one at around \$6.00. Furthermore, the pre-built ones have
surge protection built in, and this is important for voltage spikes. We
will not be sure if our own design can protect against this, and it is
too risky frying all the other components.

We only need a 12V input in our humidifier subsystem. As a result, over
multiple hours of research, I decided on the ESP-15-12 AC/DC converter.
This can provide a 12V DC output with a 1.25A current output. I estimate
that this should be enough for the PCB and the water valve. Looking at
the diagram below, I will also need to buy some plugs for the input and
output.

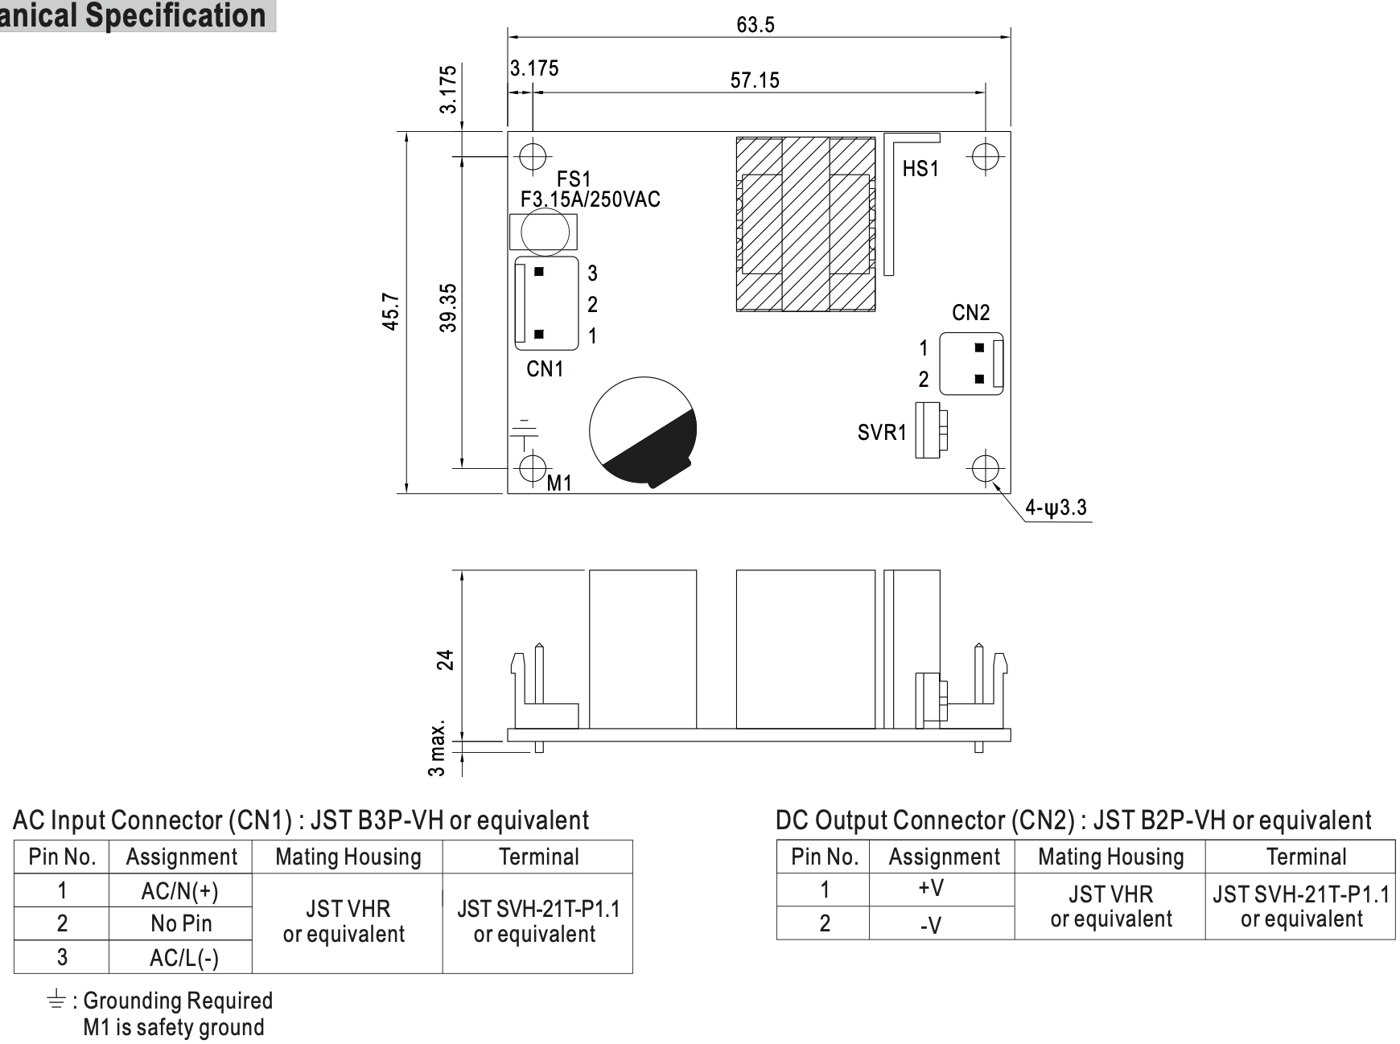
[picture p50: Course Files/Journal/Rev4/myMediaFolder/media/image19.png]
A diagram of a circuit board Description automatically generated
{width="6.5in"
height="4.848611111111111in"}

I was able to find some suggested ones on Digikey with a crimp
connection. I hope that this will work.

Aside from that, I also must think about a way to send the 120V AC into
the subsystem, and a way to power the humidifier. I did not want to make
any difficult changes to the humidifier's fan. As a result, I came up
with the idea below:

There would be a box. There will be an input power into the box through
a wire. This wire can be unplugged anytime. This leads to the
portability of the box. There will be a the 12V AC/DC converter in the
box. This converter will go feed the PCB and other components.

Along with the AC/DC converter, I bought a couple varying parts for the
idea above. This was in Digikey order: 860944423.

Aside from that, I also ordered a relay development board from Digikey.
This was part number 1528-1738-ND. I wanted Woojin to start working on
developing the GPIO functionality as soon as possible.

Finally, we paid for 2 day shipping on the order, so that it can get
here by the weekend.

We also used our remaining budget by ordering another Optomax Digital
Liquid Level Sensor. This will use up all our remaining budget.

# Friday, March 29, 2024

**Objective: Solder relay dev-board**

Today, the parts and the relay arrived. I could not really do anything
with the parts, as the machine shop still needs to work on the project.
We will need to talk to them soon. The development board for the PCB
seems pretty compact, so our PCB will also be compact.

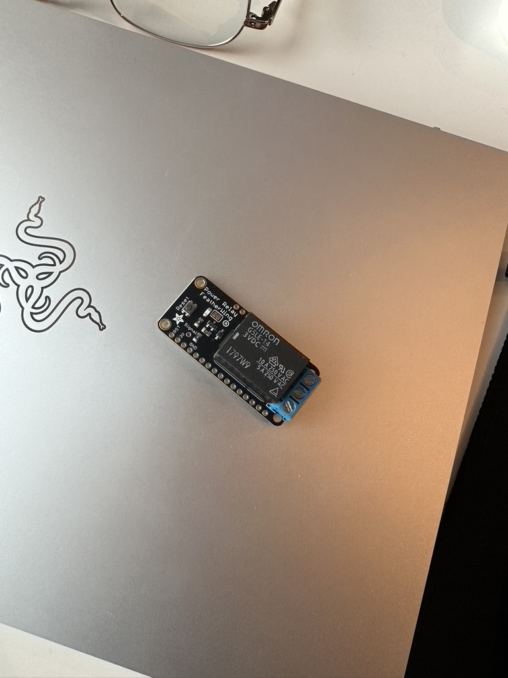
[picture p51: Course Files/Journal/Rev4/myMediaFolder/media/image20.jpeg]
A small black electronic device on a silver surface Description automatically generated
{width="5.273611111111111in"
height="7.031481846019248in"}

**\
**

# Saturday, March 30, 2024

**Objective: Solder PCB for sensor subsystem**

Today, Jalen and I started soldering the humidity sensor PCB. However,
we discovered that we were still missing some SMD components from the
ECE Electronics Supply Shop. I immediately sent an email to Surya so
that we can get some. However, since we were already at ECEB, Jalen and
I laid the paste and soldered with the parts we have on hand. We took a
while, as I was teaching Jalen how to lay the parts on the PCB. But we
were finished.

The ESP32 was a little bit hard to solder. The ground pads were hard to
heat up. Maybe the iron was not powerful enough. We will finish
soldering in another day when the parts arrive.

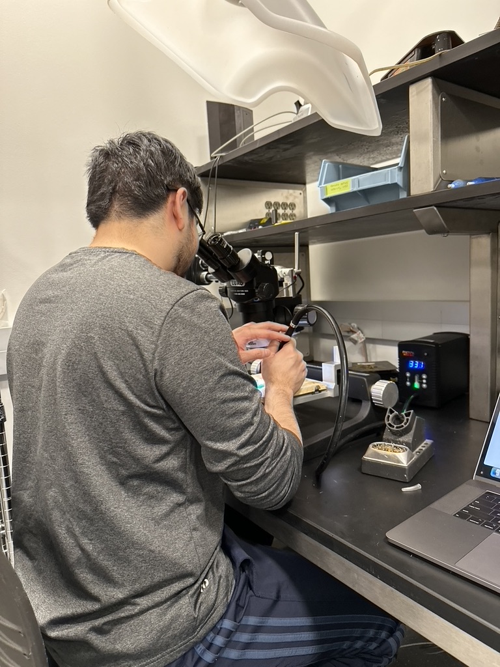
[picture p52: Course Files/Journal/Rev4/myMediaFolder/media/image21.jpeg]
{width="4.714285870516186in"
height="6.285714129483814in"}

# Monday, April 1, 2024

**Objective: Update parts list**

Jalen and I update the parts list one more time. This time, we color
coded where parts are from and did final adjustments to the quantity.

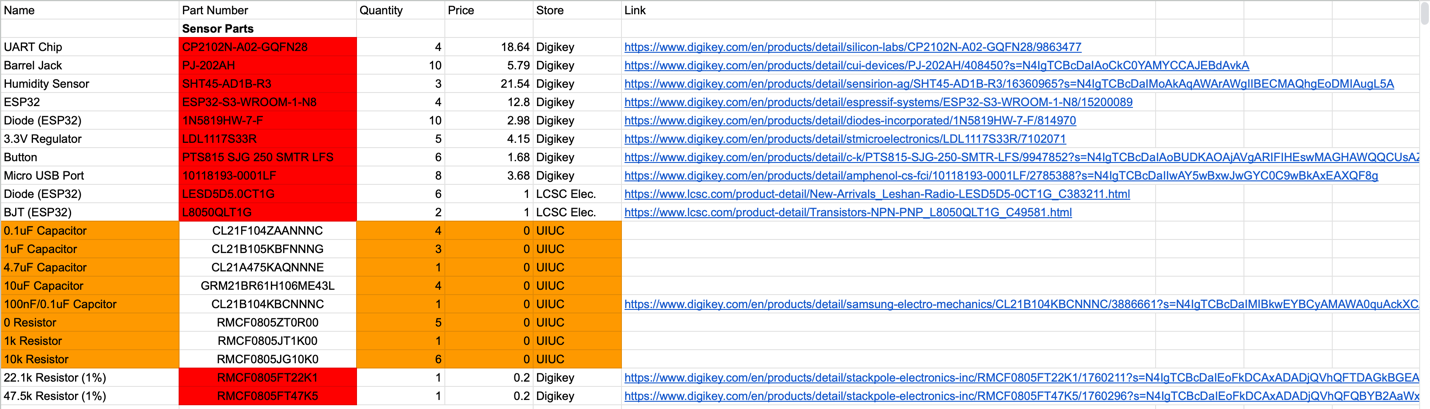
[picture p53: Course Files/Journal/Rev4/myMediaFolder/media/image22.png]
{width="6.5in"
height="1.85625in"}

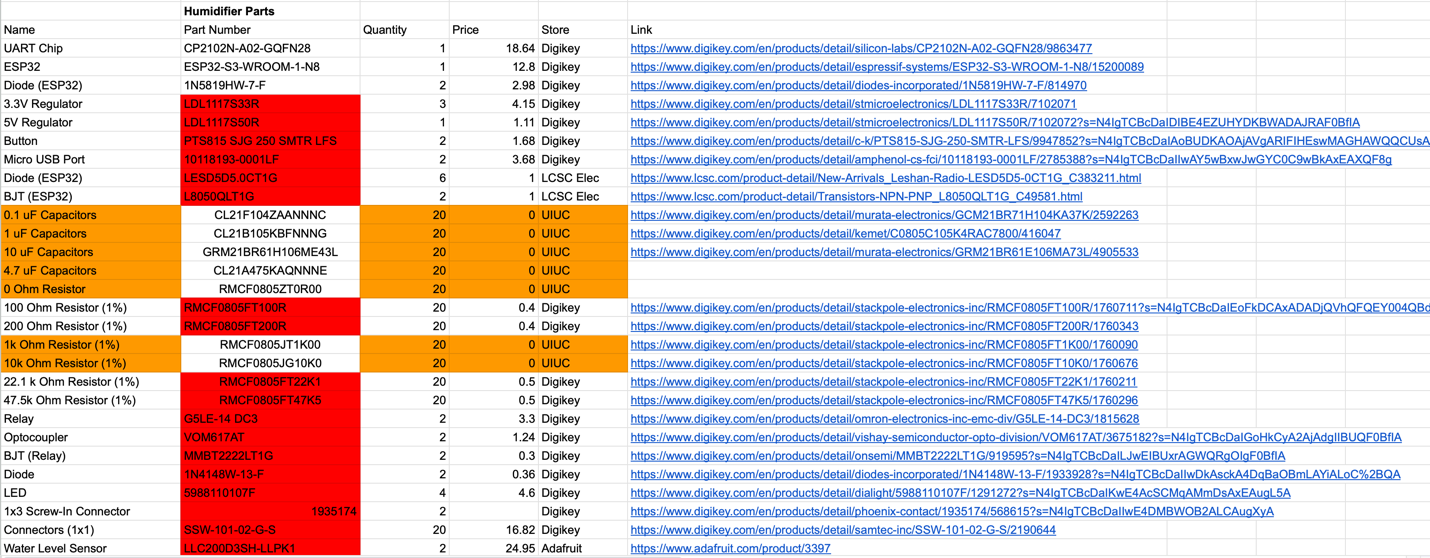
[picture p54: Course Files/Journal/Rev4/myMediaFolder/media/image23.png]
{width="6.5in"
height="2.5375in"}

# Tuesday, April 2, 2024

**Objective: Meet Surya, show Surya our PCB, address issues with PCB**

Meeting with Surya today, we told him that we will be working on our PCB
ASAP since parts are here. Surya also asked us to check in with the
machine shop, and we told him that the machine shop is working on our
parts, but there is delay. However, the machine shop did tell us to not
worry.

Tonight, Jalen and I worked on soldering the rest of the first sensor
subsystem PCB. It turned out to be a bad idea to not do all the
soldering at once, as we had to remove all the old solder off the pads
before laying new paste.

After fixing some bridging in certain parts of the chip, we were able to
plug the PCB into our 12V wall power supply. This 12V was from my
previous class in Fall 2023. We were able to program a basic program to
the ESP32.

However, when I tried to program a sample Wi-Fi access point code to the
ESP32, the ESP32 initially worked then started crashing. The symptom is
that, on the serial monitor, it would show that it was connecting and
disconnecting. Also, the voltage regulator and the surrounding
capacitors got really hot. In fact, it got so hot that it was
uncomfortable to the touch. Ultimately, the voltage regulator fried
itself and stopped outputting 3.3V. Thankfully, it output 1.5V, so it
did not fry the ESP32.

We think that the regulator might be defective, so we changed it for
another one. Though the new one did not fry itself, it still had the
issue where the ESP32 would keep connecting and disconnecting.

It was 3-4am, so we decided to go home and solve it the next day.

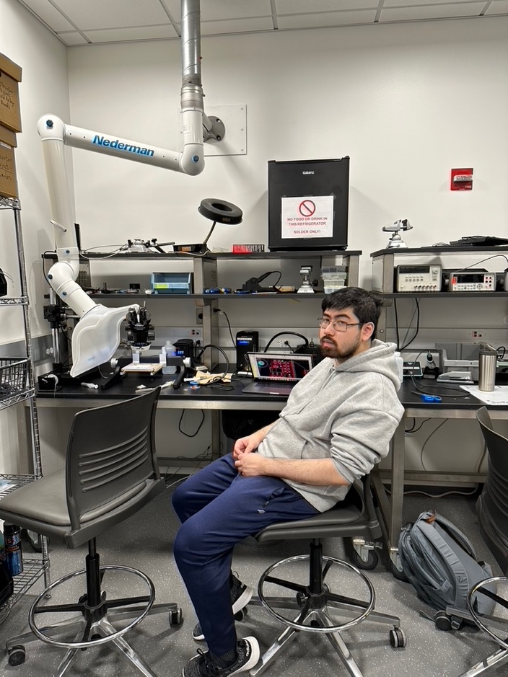
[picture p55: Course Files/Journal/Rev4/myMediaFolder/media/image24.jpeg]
A person sitting in a chair in a room with a desk and a robot Description automatically generated
{width="5.913580489938758in"
height="7.884771434820648in"}

**\
**

# Wednesday, April 3, 2024

**Objective: Debug PCB, why it is constantly restarting**

I started a Reddit post on r/ESP32 to ask why I was experiencing this
problem.

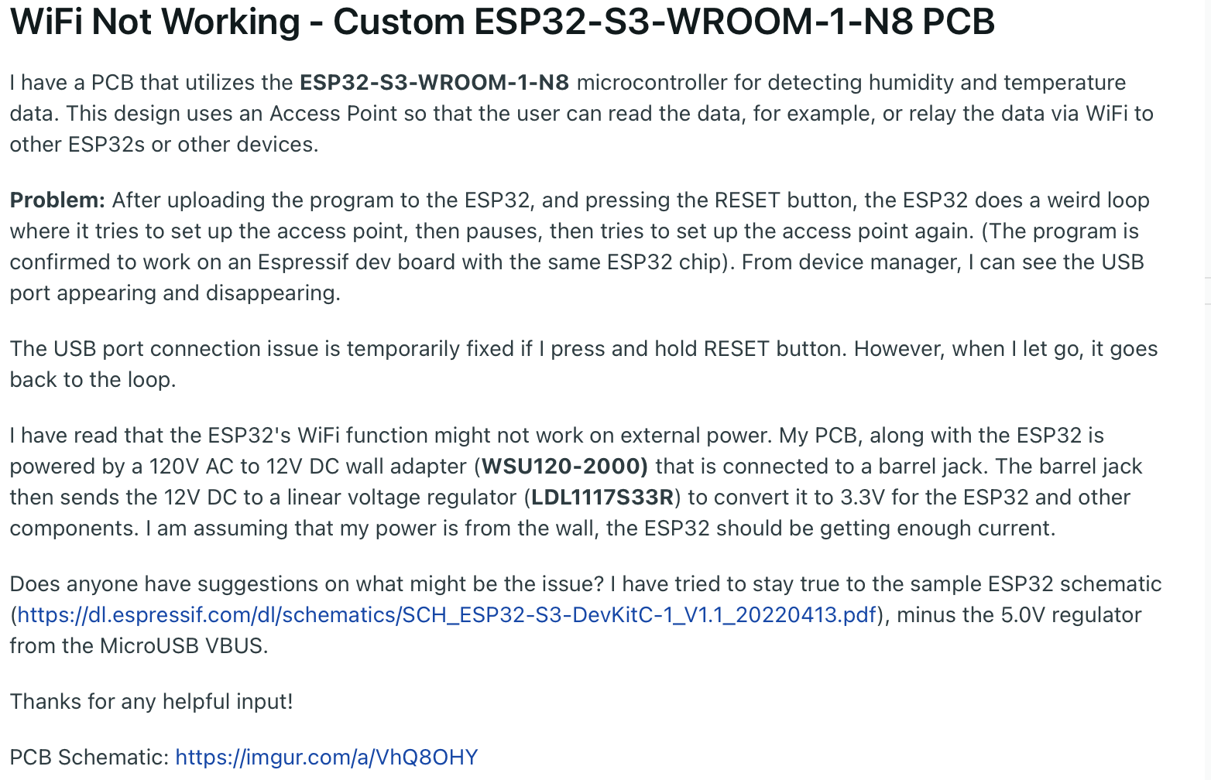
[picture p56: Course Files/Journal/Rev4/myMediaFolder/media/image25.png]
{width="6.5in"
height="4.189583333333333in"}

I did some research on why this might be. There are similar symptoms
online. It seems like the reason for this is because the Wi-Fi module on
the ESP32 draws a lot of current. As a result, the power draw through
the voltage regulator is high. Maybe with a better power supply, the
ESP32 will not "throttle".

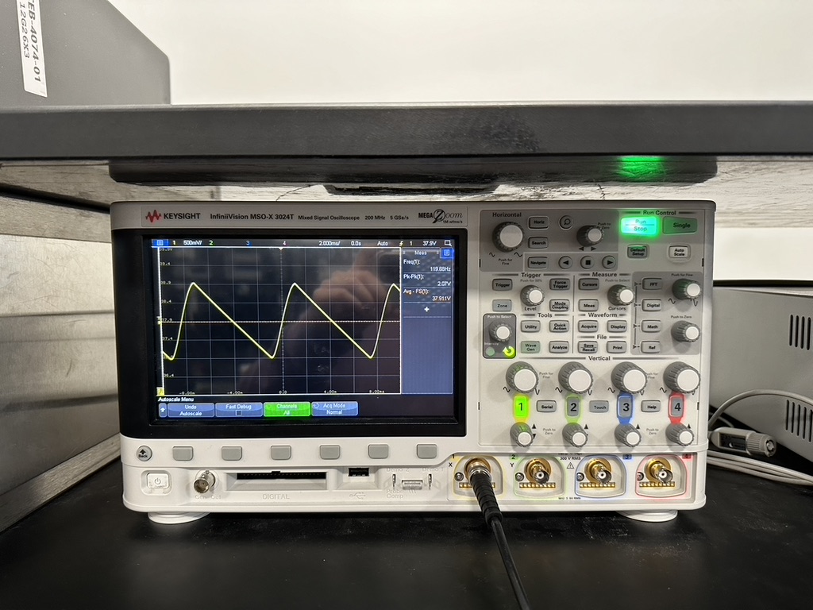
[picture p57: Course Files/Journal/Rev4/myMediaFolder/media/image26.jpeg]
A white electronic device with a screen and buttons Description automatically generated
{width="6.5in"
height="4.875in"}

A Reddit user suggested using the power supply from the lab bench and
using a lower voltage. The reason is with a high voltage difference in
the input and output of the linear voltage regulator, the difference is
dissipated as heat.

As a result, I first tested the bench power supply at 12V. It still had
the throttling issue, even though enough current was supplied. Next, I
started decreasing the voltage by 1V increments. I noticed that starting
at 8.0V and below, the ESP32 would no longer throttle. This means that
we should figure out a way to decrease the voltage supply.

I talked to Stephen Messing, a PhD student from the Laser Optics Physics
Laboratory research group (Andrey Mironov and Gary Eden), and he
suggested putting linear voltage regulators in series, with increment
decreases in voltage. This will decrease the voltage drop and balance
out the power draw through each regulator.

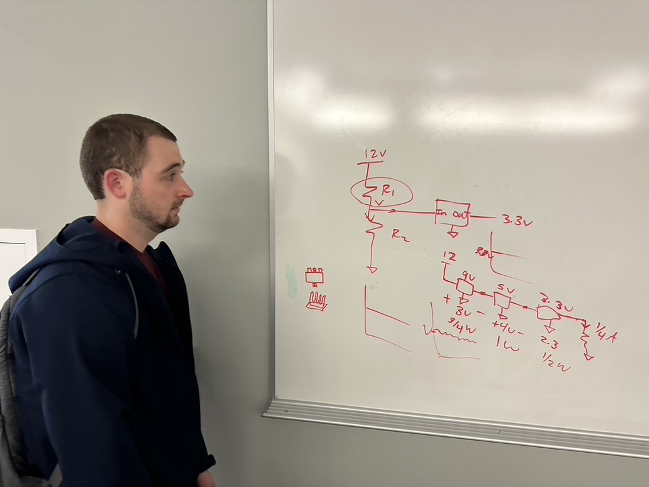
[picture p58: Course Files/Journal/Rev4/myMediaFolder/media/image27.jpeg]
A person standing next to a whiteboard Description automatically generated
{width="6.5in"
height="4.875in"}

Ultimately, I decided to use a 5V wall plug the power the sensor
subsystem, and a RS-15-5 AC/DC converter to power the humidifier
subsystem's PCB. I also bought a new AC/DC converter. Instead of the
previous one, this one has an isolation case. Also, the inputs and
outputs are screws. This makes it easier to wire.

# Thursday, April 4, 2024

**Objective: Draw diagram so Woojin can understand, solder humidifier subsystem PCB**

In ECE343's lab, I drew this diagram detailing the idea behind the
humidifier subsystem.

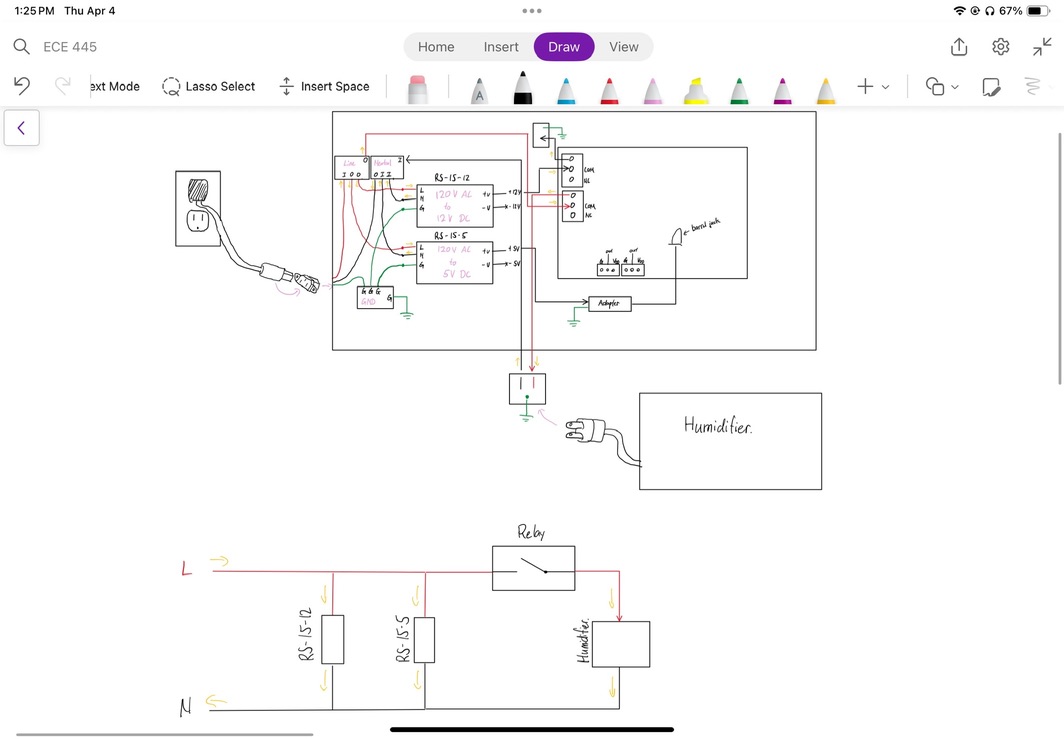
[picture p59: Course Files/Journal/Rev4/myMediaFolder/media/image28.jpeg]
{width="6.5in"
height="4.508333333333334in"}

The diagram above shows the inputs and how the different components will
be powered. I hope that this will help Woojin understand how everything
goes together better.

Later that night, I took the burden upon myself to solder the PCB for
the humidifier subsystem. Jalen said he can help on Saturday, but that
is already too late. This is because I may need to order parts on
Friday.

# Friday, April 5, 2024

**Objective: Solder PCB for humidifier subsystem, debug PCB**

I finished the PCB early Friday morning. I just soldered one relay and
one water level sensor input.

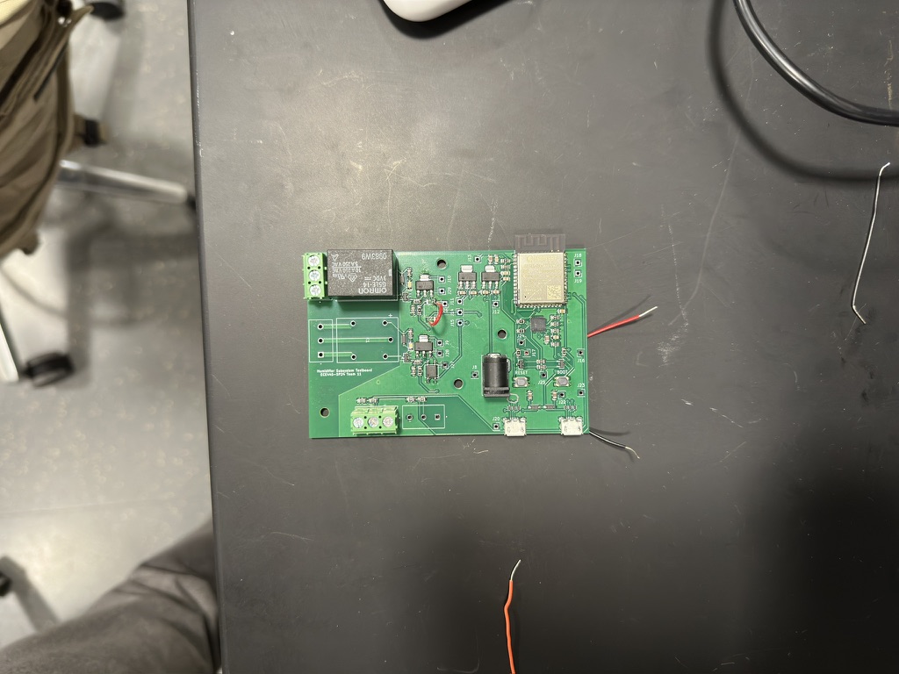
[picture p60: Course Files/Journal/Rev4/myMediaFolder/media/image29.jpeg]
A green circuit board on a black surface Description automatically generated
{width="6.5in"
height="4.875in"}

When I programmed it, the PCB works with Wi-Fi with a 5V input. However,
GPIO 19 and 20 were not outputting signals to the relays. I think that
the ESP32 was not soldered on properly. So, I tried to remove the ESP32.
I think I heated the board too hot because there was smoke. Also, upon
inspection, the UART chip had a hole in it and the push buttons were
disintegrated. At 5:40am, I gave up and decided to go home.

When I got home, I also worked on ordering new parts. I ordered a couple
more ESP32s, relays, UART chips, and other various parts that can be
used on the sensor and humidifier subsystems. This is so that we don't
need to wait for parts if we need any.

At night, I went to Home Depot with Taiyuan (Daniel) Hu to get some
parts. I got some 14 gauge Romex wires, 5 input WAGO connectors, 2 input
WAGO connectors, Klein no-contact voltage tester and IR thermometer, and
a Milwaukee wire stripper and crimper.

# Sunday, April 7, 2024

**Objective: Make revisions for humidifier PCB, improve design on final round**

Today, I worked on some PCB revisions to the humidifier PCB. Because
Tuesday, April 9, 2024, is the fifth round of PCB orders, we needed a
fail-safe for our humidifier subsystem. I made 5 PCBs. The first order
is another order of our, already working, sensor subsystem. The next is
an order of our humidifier subsystem from the second round. The third
board is the same, but with the GPIOs for the relays moved. The fourth
board is a re-routing of the traces in the third board. The fifth board
contains cutouts for the high voltage. I spent the whole night doing
this and finished early in the morning.

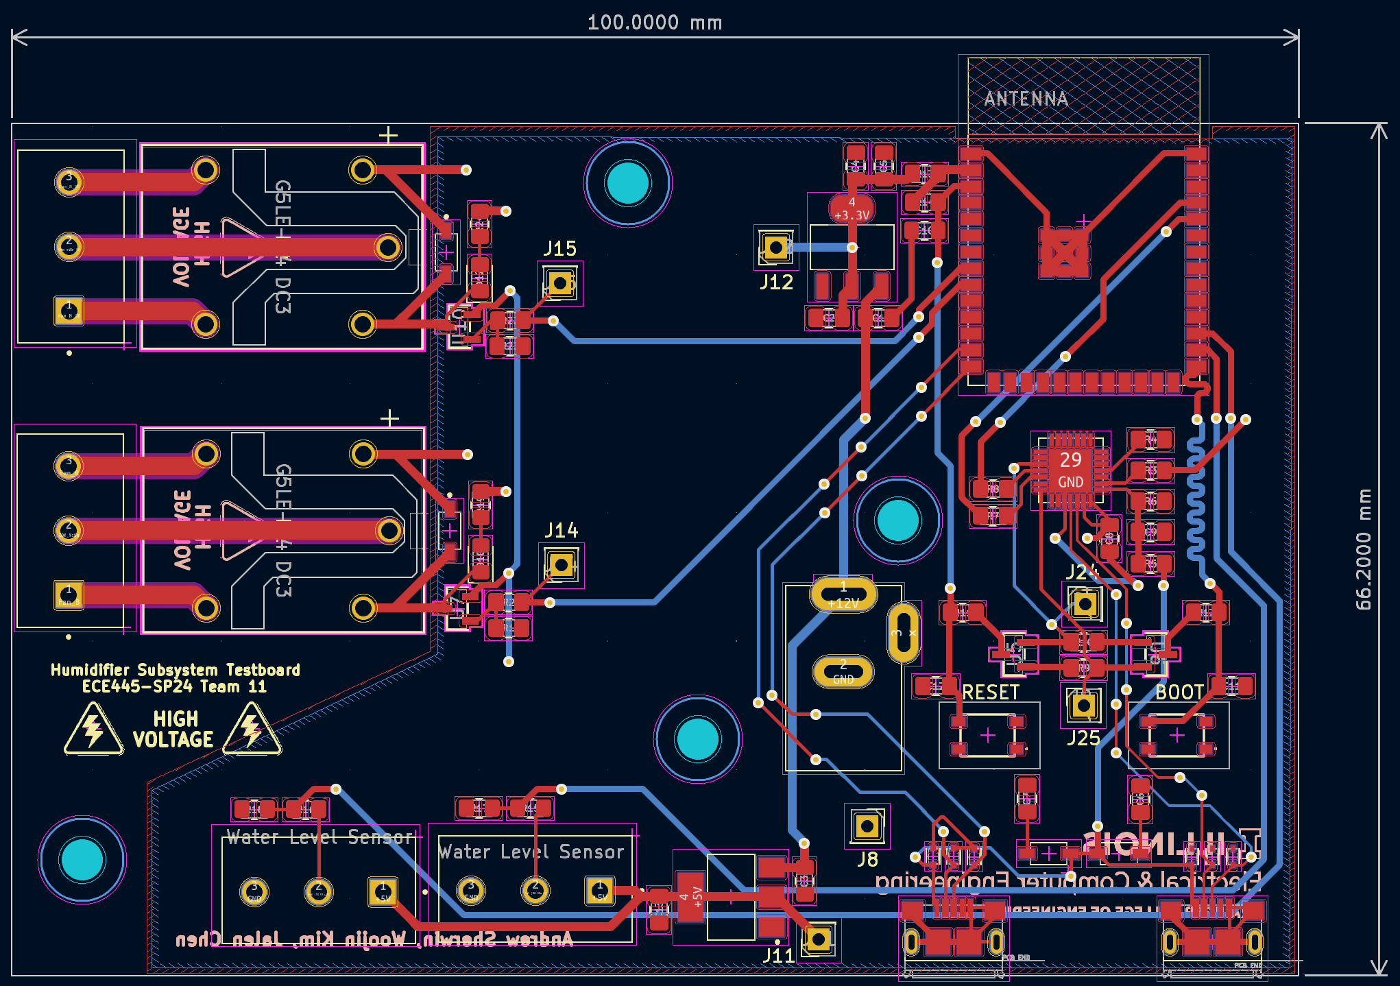
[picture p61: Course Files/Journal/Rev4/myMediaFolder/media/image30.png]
{width="6.5in"
height="4.577083333333333in"}

# Monday, April 8, 2024

**Objective: Talk to machine shop about our project**

Today, I talked with the machine shop. I needed to talk to Gregg about
our project, as he sent us an email saying he came back from vacation.

When I went in to talk to Gregg, it turns out that he was involved in a
car accident in the morning of March 22, 2024. As a result, he was not
able to come back to ECEB. He had a scar on his upper right eyebrow. I
went over the project with him, and he said I should get a call in the
next few days to the end of the week.

# Wednesday April 10, 2024

**Objective: Meet Surya, talk to him about machine shop, solder remaining PCBs**

Today we met with Surya. Surya asked how the PCBs were going, and I told
him that we are working on it. After the meeting, Woojin and I decided
to solder the remaining two sensor subsystem boards. I taught Woojin how
to place the components and paste the board with the stencil.

A person looking through a microscope Description automatically generated{width="3.4175251531058617in"
height="4.556700568678915in"}

I did the ESP32 chip, as Woojin does not have experience to do it, and I
don't want him to mess up. We finished early Thursday morning. We tested
the boards with the programs, and they all work on the first try.

A group of green electronic components on a black surface Description automatically generated{width="6.5in"
height="4.875in"}

# Thursday April 11, 2024

**Objective: Test humidifier PCB, figure out what is wrong**

Today, I decided to solder the humidifier board with our replenished
parts. The reason why I did not want to wait until Saturday to do it
with Jalen is because there will be no time to buy new parts on Saturday
and have it ship.

I finished soldering the board with just one relay like last time.
However, before soldering the ESP32, I tested the voltage divider from
the water level sensor to make sure it outputs 3.3V to the ESP32.

$$V_{out} = \ V_{in}*\frac{100}{100 + 200}$$

$$V_{out} = 3.333V$$

After the verification with the multimeter, I was comfortable to solder
the ESP32 on.

A green circuit board with black wires Description automatically generated{width="6.5in"
height="4.875in"}

Upon testing the board, I can see that it is fully working. I realized
that the first time that I did it, the board fully works. Maybe it was
late that night, but I got GPIO number, and the pin number confused on
the program.

I also bridged the connection in the through holes. This will avoid the
optocoupler, which did not work. Also, because the ground is shared, the
optocoupler was pointless.

In the day, I went to the machine shop the bring them my new AC/DC
converters with the isolation cage. Also, it was to check in with Gregg
on when they will start working on the project.

Gregg asked around the shop for who was interested and available to work
on our project. He assigned us to Skee Aldrich. I went over the
components with Skee and the functionality. We picked a clear box for
the humidifier subsystem. This was the only box left that can fit the
components. It looks good.

# Friday, April 12, 2024

**Objective: Work on the box containing humidifier PCB, test input voltage**

Today, Jalen and I was going to wire the board up. We needed to test the
AC components. At around 15:50, I went to the machine shop to get some
parts for us to use. Skee had already left, but I asked Gregg if I could
borrow the parts. Gregg said sure, but I had to return it Monday morning
at 8:00am. I promised him that I will do it.

With the box, Jalen and I mock-placed the components. A close-up of a device Description automatically generated{width="6.5in"
height="4.875in"}

We also tested the functionality of the transformers. We determined that
the 5V transformer was not working, as the adjuster only output 4.2V.

I updated the block diagram again. This time, I am reflecting the
switching regulated supply. There will be two switching regulated
supply. The first one will take in 120V and output 5V, while the other
takes in 120V and outputs 12V.

A screenshot of a computer Description automatically generated{width="6.5in"
height="5.486111111111111in"}

**\
**

# Sunday, April 14, 2024

**Objective: Resolder second humidifier subsystem PCB with new parts**

Today, I finished up soldering the rest of the humidifier subsystem's
PCB. I added the remaining relay and the water level sensor input. This
was because we have a mock demo on Tuesday. A hand holding a green circuit board Description automatically generated{width="5.304124015748031in"
height="7.072165354330709in"}

Tonight, Woojin got the HTML webpage up. Our data can be read on the
website, though a little bit low.

# Monday, April 15, 2024

**Objective: Give parts to Skee, wire up box**

I went to ECEB at 7:55am to hand the parts to Skee. Gregg was very happy
that I showed up on time in the morning.

Skee finished up the boxes today, so I can work on wiring them up today.
However, he still needed to work on the water tank for us to demo. I
also noticed that he did not make holes for the sensor subsystem boxes.
The holes are for the power cables to go through. I will bring it to him
tomorrow morning.

I spent the night wiring the humidifier box up.

# Tuesday, April 16, 2024

**Objective: Test enclosure for PCB in the humidifier subsystem, meet Surya for mock demo**

Early this morning, I finished wiring the whole humidifier subsystem.
Prior to plugging the humidifier in, I used the non-contact voltage
tester to see if there are voltage leakage. There was not, so I plugged
the humidifier in. Using Woojin's webpage, the fan was able to be turned
on and off. I was happy with this result.

A computer and a phone on a desk Description automatically generated{width="6.5in"
height="4.875in"}

In the afternoon, I spent my time wiring the water level sensors and the
wires for the water valve. I bought the parts from the ECE supply store.
I also heat-shrunk the wires. Later in the afternoon, we did a practice
presentation with Surya. Surya told us to clean up the wiring. I will
heat shrink the wiring some more.

A machine with wires connected to it Description automatically generated{width="6.5in"
height="4.875in"}

# Wednesday, April 17, 2024

**Objective: Heat shrink wires, join some wires**

I cleaned up the wiring a bit with ½ inch heat shrink. However, the heat
shrink was only 6 inches long. As a result, I had to use multiple
sections. The heat shrink was from different manufacturers, so the
colors were different. I was not pleased with the result, so I bought
some marine grade waterproof heat shrink from Amazon. The order will
arrive Friday.

A hand holding a black wire Description automatically generated{width="6.5in"
height="8.666666666666666in"}

# Friday, April 19, 2024 and Saturday, April 20, 2024

**Objective: Heat shrink wires, test voltage and temperature output, make tables and graphs**

Lingxian Cai, a friend of mines fried their ESP32, and a new one will
not arrive until Monday. So, I gave our last spare one to him.

With the new 10ft long heat shrink, I worked on heat shrinking the wires
into one. I also planned to connect the water level sensors.

The heat shrink was horrible to get on the wires. The waterproof heat
shrink had a tacky layer inside. As a result, sliding the heat shrink
over the wires was very difficult. It took me 2 hours to get it over our
2.5 feet of wire.

After that, I connected the water level sensors to the wires I just heat
shrunk. Originally, I wanted to crimp the wires, as that allows the
proper connection. It is used in aerospace. However, the crimps were too
large for the heat shrink. As a result, to keep the clean look, I
soldered the wires. I stripped it 2 inches so that the contact surface
will be maximized.

Close-up of several wires Description automatically generated{width="5.511482939632546in"
height="4.133612204724409in"}

After soldering, I did continuity testing to make sure the connections
were good before heat shrinking the connections. A black and blue device with wires Description automatically generated{width="6.5in"
height="4.875in"}

The result was very clean. For the water valve wires, I need to go to
the supply store to get two new female connectors, as the original was
damaged when I was pulling the heat shrink over the wires.

Later at night, I worked with Woojin and Jalen on our presentations and
handouts for the demonstration. The demonstration is April 23, 2024, at
9:30am in 2072.

Woojin also worked on verifying the runtime and proving that 44ns is
unrealistic. He also updated the water level sensor algorithm. I
discovered a couple days ago when demonstrating to Surya on the mock
demo that the algorithm did not make sense. Previously, it would only
fill water when both sensors detect no water. However, when the lowest
sensor detects water, it will stop filling. As a result, the water level
will never go to the top sensor. Woojin also made an offset algorithm
for the humidity data and the temperature to compensate for the box
design.

Jalen and I also did our RV table verifications. Below are the graphs of
data that we collected for the voltage input over 1 hour:

A graph of a graph of a graph of a graph of a graph of a graph of a graph of a graph of a graph of a graph of a graph of a graph of a graph of Description automatically generated{width="6.5in"
height="2.2098764216972877in"}A graph of a graph of a graph of a graph of a graph of a graph of a graph of a graph of a graph of a graph of a graph of a graph of a graph of Description automatically generated{width="6.5in"
height="2.0740737095363078in"}

A table of numbers with numbers Description automatically generated{width="6.5in"
height="5.999305555555556in"}

We were also able to confirm that our three sensor readings matched that
of the commercial humidity and temperature sensor from Amazon.

A hand holding a phone over a digital device Description automatically generated{width="5.19807852143482in"
height="3.5688538932633422in"}

Woojin did the runtime test, and the runtime was 90,000ns for a two way
communication. This is around 45,000ns for SHT45 to the humidifier
subsystem's ESP32. This is because there is a lot of data to pack and
unpack, as well as other delays when running the code. Therefore, we
verified that the 44ns was unrealistic theory.

# Monday, April 22, 2024

**Objective: Print handout at FedEx, buy parts at Home Depot, finish wiring**

Today, I printed 4 copies of the handout at FedEx. I printed the copies
using 32g paper for a more professional and premium feel.

I also went to Home Depot again to pick up heat shrink, 0.250 female
connectors for 18-22 gauge wires, and water resistant heat shrink.

At night, we double checked the PowerPoint and did some practice
presentations. Woojin added 8 sources to the bibliography. Woojin needs
more practice on the presentation.

While Woojin left early, Jalen and I finished the water pump's wiring.
We tested everything in the humidifier subsystem and confirmed
everything worked.

# Tuesday, April 23, 2024

**Objective: Present demonstration**

After going home, I continued to look through the PowerPoint to make
sure everything looks correct. I added descriptions to the photos in the
PowerPoint. I also told Woojin what to say for the 44ns. I made sure all
our verifications were met. I also practiced speaking every slide on the
PowerPoint, so that I know everything.

In the morning, I arrived at ECEB at 8:30. I got the study room across
the ECE411 OH room. I plugged the sensors in and made sure everything
worked. Woojin came in, but Jalen was really late. Luckily, he arrived
on time for the presentation.

The presentation went spectacularly. Professor Schuh and the second TA
were impressed with our project. The professor's face lit up when we
unplugged one sensor, and the average was recomputed with just two
sensors. Surya said in text that we earned 10 points for complexity!

A screenshot of a chat Description automatically generated{width="4.525773184601925in"
height="3.2439523184601926in"}

A group of men standing in a room Description automatically generated{width="6.5in"
height="4.875in"}

# Friday, April 26, 2024

**Objective: Film extra credit video**

Today Jalen and I filmed the extra credit video together. The reason why
Woojin could not attend was because he had badminton.

It was originally hard to get it under 2 minutes, but we made it 2x speed. 

# Saturday, April 27, 2024

**Objective: Prepare for final presentation, 3D scan product**

We met today to work on the final presentation PowerPoint. There was not
a lot of things to add, as our previous PowerPoints already had graphs
and data. We did, however, add schematics of our PCB and added a slide
about the challenges we faced. On top of that, I 3D scanned our
humidifier and the sensors. This will be used on the PowerPoint as a
looping video.

# Monday, April 29, 2024

**Objective: Present final presentation**

Today was our final presentation. We spoke for 20-21 minutes, so the
timing was very good. However, Professor Schuh asked a very tricky
question at the end of the presentation. We had one bullet point stating
that we can modularize our humidifier by removing the water level
sensors and the water valve. However, Schuh brought up doesn't that
point negate one of our high levels. I did not want to answer his
question directly, so I danced around the question. The reason why I put
the bullet point was because we need to design a new humidifier from the
ground up to have our full working project. However, we do not have the
funding for that.

# Tuesday, April 30, 2024

**Objective: Work on final report**

Today, we worked on the final report with Woojin and Jalen. Most of our
report was a carry-over from the design document. However, some things
had to be updated, as we are now using relays and 5V as input to the
PCB, for example. We updated our labor table, as seen below:

A table with numbers and a group of men Description automatically generated{width="6.5in"
height="3.026388888888889in"}

We estimated that there are 24 hours of work done by the machine shop.
This is because the machine shop worked on our project for three 8-hour
workdays. We also discussed the total amount of hours we each put in the
project. There were some slight discomforts when discussing the hours
that Woojin spent on work. Though we agreed to put 2 hours and 0.5 hours
for Circuit Design and PCB Design for Woojin, this is just a "show of
face" to Woojin. The reason is that he basically did 0 hours for both of
those two categories. He does not even have the KiCad files on his
computer and is not clear about how the circuit works. He did do
software engineering, but 78 hours is a stretch. The software he wrote
was primarily using libraries and example code. He claimed it took him 5
hours to figure out GPIO signals, but not only did I send him example
code at the beginning of the semester, but GPIO read and write only
takes 15-30 minutes to learn. Woojin did help solder for 5 hours and did
help with troubleshooting. But the amount of work he performed was not
satisfactory, as he was always busy with other classes.

Jalen's hours are accurate, as I worked closely with him all semester.

At the end of the night, we realized that we still had to
cross-reference figures and citations. We decided to finish that the
next day.

# Wednesday, May 1, 2024

**Objective: Conflict between members on labor table, turn in final report**

Woojin was not able to make it to help us do the cross-reference, so
Jalen and I worked on it earlier. It took us two hours to finish, and it
was just as I predicted yesterday.

We submitted the paper. However, at 17:30, Woojin called me and asked me
to take down the labor table. He says that while some teams like Fall
2022's CHARM has it, many other teams do not have it. I got the feeling
that he was uncomfortable and embarrassed with the amount of work that
he did. I did not like his idea because that would discredit all the
work that Jalen and I did. Woojin says that we can just include the
total hours, in fact he can even decrease his hours to 145. I told him
to talk to Jalen about it. If Jalen agrees, then I will change it. Jalen
agrees since he did not want to cause trouble, and I updated it to the
table below:

A black line with black text Description automatically generated{width="6.5in"
height="1.0138888888888888in"}

I kept it at 155 hours for Woojin as I feel like it honors his work.
However, Jalen and I are not very satisfied with this. However, I did
push it on the website as we agreed on. I left the first version as
"confidential".

Woojin went on Discord to ask us to remove the original version from the
server. I said I will not do that, as it is already confidential. He
tried calling me, but I ignored his call.

A screenshot of a chat Description automatically generated{width="5.148148512685914in"
height="4.598133202099738in"}

I suggested we do a group call at 22:00 so that he can beat around the
bush and tell us what he really wants.

During the call, I suggested that we make a compromise where Jalen and I
keep our breakdown of hours, but Woojin will have his blanked out. He
also stated that he though 155 hours is too much and should decrease his
software engineering hours to 40 hours. This will make his new total 117
hours. Jalen and I agreed to this. Also, we removed the original
document from the ECE445 page as requested by Woojin. I think Woojin
does not want the public to know what parts he worked on specifically.
Below is the final table:

A table with numbers and letters Description automatically generated{width="6.444444444444445in"
height="3.115054680664917in"}

To upload this Word document to GitHub, I had to find a way to convert
the text to MarkDown, which is GitHub's text file format. I found Pandoc
that can do it for you. By using the command:

"pandoc \--extract-media ./myMediaFolder input.docx -o output.md"

I can export the text and media and push it to GitHub.

# References

1.  F. Hecht, "Wifi Propagation," *freedom*, 2017.
    https://doc.freefem.org/tutorials/wifiPropagation.html (accessed
    Mar. 29, 2024).

2.  M. Marwell, "Issues with the I^2^C (Inter-IC) Bus and How to Solve
    Them," *DigiKey*, Aug. 09, 2018. Accessed: Mar. 29, 2024.
    \[Online\]. Available:
    https://www.digikey.com/en/articles/issues-with-the-i2c-bus-and-how-to-solve-them

3.  MetaGeek, "Wi-Fi and Non Wi-Fi Interference," *MetaGeek*, 2024.
    https://www.metageek.com/training/resources/wifi-and-non-wifi-interference/
    (accessed Mar. 29, 2024).

4.  A. V. Arundel, E. M. Sterling, J. H. Biggin, and T. D. Sterling,
    "Indirect health effects of relative humidity in indoor
    environments.," *Environmental Health Perspectives*, vol. 65, no.
    65, pp. 351--361, Mar. 1986, doi: 10.1289/ehp.8665351.

5.  V. Perrone *et al.*, "The Epidemiology, Treatment Patterns and
    Economic Burden of Different Phenotypes of Multiple Sclerosis in
    Italy: Relapsing-Remitting Multiple Sclerosis and Secondary
    Progressive Multiple Sclerosis," *Clinical Epidemiology*, vol.
    Volume 14, no. 14, pp. 1327--1337, Nov. 2022, doi:
    10.2147/clep.s376005.

6.  IEEE, "IEEE Code of Ethics," *IEEE Code of Ethics*, 2020.
    https://www.ieee.org/about/corporate/governance/p7-8.html (accessed
    Mar. 29, 2024).

7.  University of Illinois, "Salary Averages," *UIUC*, 2022.
    https://ece.illinois.edu/admissions/why-ece/salary-averages
    (accessed Mar. 29, 2024).

8.  Environmental Protection Agency, "Care for your air: A guide to
    indoor air quality," *US EPA*, Aug. 07, 2023.
    https://www.epa.gov/indoor-air-quality-iaq/care-your-air-guide-indoor-air-quality
    (accessed Mar. 25, 2024).

9.  Sensirion, "Datasheet -SHT4x," *Sensirion*, Aug. 2023.
    https://sensirion.com/media/documents/33FD6951/6555C40E/Sensirion_Datasheet_SHT4x.pdf

10. A. Sherwin, *ECE445 Team 11 - Sensor Subsystem Schematic*. 2024.

11. A. Sherwin, *ECE445 Team 11 - Humidifier Subsystem Schematic*. 2024.

12. Espressif, "ESP32-S3-WROOM-1 ESP32-S3-WROOM-1U
    Datasheet," *Espressif*, 2023.
    https://www.espressif.com/sites/default/files/documentation/esp32-s3-wroom-1_wroom-1u_datasheet_en.pdf

13. IEEE, "IEEE Code of Ethics," *IEEE Code of Ethics*, Jun. 2020.
    https://www.ieee.org/about/corporate/governance/p7-8.html (accessed
    Mar. 26, 2024).

14. Espressif, "sch_esp32-s3-devkitc-1_v1_20210," *Espressif*, Apr.
    13, 2022.
    https://dl.espressif.com/dl/schematics/SCH_ESP32-S3-DevKitC-1_V1.1_20220413.pdf
    (accessed Mar. 26, 2024).

15. A. Sherwin, *Sensor Subsystem Block Diagram (Close-Up)*. 2024.

16. A. Sherwin, Humidity Subsystem Block Diagram (Close-Up). 2024.

17. D. Workshop, "ESP NOW - Peer to Peer ESP32 Communications," DroneBot
    Workshop, Apr. 03, 2022. https://dronebotworkshop.com/esp-now/

18. K. Rembor, "Adafruit Sensirion SHT40, SHT41 & SHT45 Temperature &
    Humidity Sensors," Adafruit Learning System, Feb. 04, 2021.
    https://learn.adafruit.com/adafruit-sht40-temperature-humidity-sensor/arduino

19. cplusplus, "std::chrono::high_resolution_clock::now," cplusplus.
    https://cplusplus.com/reference/chrono/high_resolution_clock/now/
    (accessed Apr. 20, 2024).

20. cplusplus, "std::chrono::nanoseconds," cplusplus.
    https://cplusplus.com/reference/chrono/nanoseconds/ (accessed Apr.
    20, 2024).

21. me-no-dev, "ESPAsyncWebServer/README.md at master ·
    me-no-dev/ESPAsyncWebServer," GitHub.
    https://github.com/me-no-dev/ESPAsyncWebServer/blob/master/README.md

22. Tea, "ESP32 Web Server periodic updating problem," Stack Overflow.
    https://stackoverflow.com/questions/64610221/esp32-web-server-periodic-updating-problem

23. antepher, "ESP32 Arduino: HTTP server over soft AP," techtutorialsx,
    Jan. 07, 2018.
    https://techtutorialsx.com/2018/01/07/esp32-arduino-http-server-over-soft-ap/

24. ESPRESSIF, "ESP-NOW - ESP32 - --- ESP-IDF Programming Guide v5.2.1
    documentation," espressif.com.
    https://docs.espressif.com/projects/esp-idf/en/stable/esp32/api-reference/network/esp_now.html

25. Center for Drug Evaluation and Research, "Use Caution When Giving
    Cough and Cold Products to Kids," *U.S. Food and Drug
    Administration*, 2018.
    <https://www.fda.gov/drugs/special-features/use-caution-when-giving-cough-and-cold-products-kids>
    (accessed May 01, 2024).

26. A. Sherwin, Consumer Visual Aid. 2024.

27. A. Sherwin, Component Visual Aid. 2024.

28. A. Sherwin, Overall Block Diagram. 2024.

29. A. Sherwin, Humidity Subsystem PCB. 2024.

30. A. Sherwin, Webserver Webpage. 2024.

31. A. Sherwin, Sensor Subsystem PCB. 2024.

32. A. Sherwin, RV Table A-1. 2024.

33. A. Sherwin, RV Table A-2. 2024.

34. A. Sherwin, RV Table A-3. 2024.

35. A. Sherwin, RV Table A-4. 2024.

36. A. Sherwin, RV Table A-5. 2024.

37. A. Sherwin, RV Table A-6. 2024.

38. A. Sherwin, RV Table A-7. 2024.

39. A. Sherwin, RV Table A-8. 2024.

40. A. Sherwin, RV Table A-9. 2024.

41. A. Sherwin, RV Table A-10. 2024.

42. A. Sherwin, RV Table A-11. 2024.

43. A. Sherwin, RV Table A-12. 2024.

44. A. Sherwin, Sensor Subsystem Parts. 2024.

45. A. Sherwin, Humidifier Subsystem Parts. 2024.

46. A. Sherwin, Estimated Development Hours. 2024.

47. A. Sherwin, Total Cost. 2024.

48. Engineering IT Shared Services, "Lab :: ECE 445," *Senior Design
    Laboratory*, 2020.
    https://courses.engr.illinois.edu/ece445/lab/index.asp (accessed May
    01, 2024).

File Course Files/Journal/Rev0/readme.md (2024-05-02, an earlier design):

**Tuesday, February 06, 2024**

A notebook with writing on it Description automatically generated{width="6.361111111111111in"
height="8.481481846019248in"}

**Wednesday, February 07, 2024**

Today, we talked to the machine shop. Prior to going, I made a
PowerPoint describing what we wanted to do. In the PowerPoint, I
included some images, such as a visual aid, and images of parts that we
may use.

In the machine shop, Gregg told us that they will not build a new
humidifier for us. However, they will be happy to modify one from
Amazon. He suggests that we get one that is simple, with a manual on-off
function. Also, it is preferred that it is square, so that it will be
easier to mount things without leaks.

A notebook with writing on it Description automatically generated{width="6.5in"
height="8.666666666666666in"}**\
**

**Thursday, February 08, 2024**

A notebook with writing on it Description automatically generated{width="8.36111111111111in"
height="6.270833333333333in"}

**Wednesday, February 14, 2024**

**Objective: Meeting with Surya, discuss machine shop, discuss using
GitHub for journal**

Today we had a meeting with Surya. We went over our meeting with the
machine shop. I told Surya that we are not able to have a rotating head
as originally proposed. The reason is that the machine shop does not
want to build a humidifier ground up for us. Also, the machine shop just
wants to modify a humidifier to fit our needs. Surya told us to think of
another high level to fill in for the rotating head. We said that we may
do automatic water refilling. Surya also reminded us to sign up for the
design review, which is opening on Friday.

I also asked Surya if, instead of writing physically on a journal, I can
change to GitHub. He says yes, and to make sure to submit the journal at
the end of the semester.

**Thursday, February 15, 2024**

**Objective: Pick part with Jalen, what sensor and ESP32 to use**

I worked to Jalen picking out parts for our project. We needed to figure
out what water level sensor to use and what humidity sensor to use. We
did a lot of research to see what sensors met our needs in price and in
function. Also, we had to decide on what microcontroller we should use.
There are many versions of the ESP32, and we need to decide on one.

After doing research, we are leaning on using the ESP32-S3-WROOM-1-N8.
The reason for this is because we don't need the extra DRAM from other
versions, and the S3 has a UART-USB chip.

**Friday, February 16, 2024**

**Objective: Text Surya about buying ESP32 board**

Today, I texted Surya about ordering a development board. He says that
there are some ESP32 development boards that we can check out in ECE445.
He will get back to me about it next week. I told Surya that we will
check it out in our meeting next week.

**Tuesday, February 20, 2024**

**Objective: Meet with Surya, discuss proposal, place order for sensor,
rent ESP32 Dev Board**

Today we met with Surya. We talked about our progress with the project
and the due dates coming up. Surya told us about our scores for our
proposal report. It was a bit low, but he says we can still make changes
to it and submit it on Friday. He says that the other TA who graded the
paper was strict about the scores. We were missing some requirements,
which we will update. He also told us to look at CHARM's paper. We
originally did that too, but this time we will also reference the
rubric. We will continue working on the project. We told Surya we are in
the process of picking parts for the project.

We told Surya that our new high level will be to read the water level
and automatically fill the water tank.

Today, we also placed the order for our water level sensor. We chose the
Optomax Digital Liquid Level Sensor as it seems easy to work with and is
well waterproofed. The only downside is that it is \$24.99. We only
ordered one to make sure it works.

Aside from that, we borrowed 4 ESP32-S3 development boards from ECE445.
Surya helped sign it out for us. Jason asked why we needed so many
boards. We told Surya that I needed two to work on two ESP32's
communicating over Wi-Fi. Jalen needs one to work on the water level
sensor and motor controller. Woojin needs one for the humidity sensor.

**Wednesday, February 21, 2024**

**Objective: Write design document, make table for parts and labor**

We worked on our design document today. Woojin, Jalen, and I had a Zoom
call. We worked on the paper together. We wonder why this class takes so
much time on the writing. It is more than 4 credit hours. We were able
to transfer a lot of our paper from the proposal over to the design
document. We also made an estimated labor table, as well as the
estimated parts list as shown below:

A screenshot of a spreadsheet Description automatically generated{width="6.5in"
height="2.4618055555555554in"}

**Friday, February 23, 2024**

**Objective: Update proposal and rebsubmit**

Today, I worked on updating the proposal. I updated the block diagram on
the proposal as well and the citations.

Later in the day, I started working on the PowerPoint for the design
review on Wednesday next week.

**Monday, February 26, 2024**

**Objective: Ask Surya if schematics are needed for design review**

Today, I texted Surya if we needed schematic diagrams on our
presentation. He says that we do not. So, I did not make any edits to
our presentation.

**Wednesday, February 28, 2024**

**Objective: Present design review, meet Surya.**

Today, we the design review. There was no meeting for this week. Thanks
for Surya, we dressed up for the design review and came prepared for the
presentation. Professor Schuh did not ask us many questions. The only
suggestions that he had were to include temperature in the algorithm for
the humidifier, update the block diagram, and looks at built in
humidifiers in houses for inspiration. Surya says that we were the first
team to get full marks on the professionalism category.

A chat message with text Description automatically generated with medium confidence{width="6.5in"
height="2.013888888888889in"}

We went to a peer review, and they just read off their Google Doc. I am
glad we make a PowerPoint.

**Sunday, March 03, 2024**

**Objective: Work on PCB for sensor subsystem**

Today, I began working on the PCB schematic for the sensor subsystem.
Yesterday, Woojin showed me his completed work on the Adafruit SHT45
development board. He showed me the output and proved that the ESP32 can
communicate with the SHT45 and read data from it.

Because we want to make it to the first PCB order group (coming
Tuesday), I will make a draft of the PCB schematic today.

The first thing that I did was find the ESP32-S3 microcontroller on our
ESP32-S3 development board. Doing some research, I believe that it is
the ESP32-S3-VROOM-1-N8. I downloaded the CAD file on Digikey, so that I
can import it to KiCAD.

Next, I looked at the SHT45 sensor. I went on Sensirion's website and
looked through the documentation. They had a sample circuit. I think I
will base my schematic on that, as the Adafruit development board has a
lot of "fluff" on it. I also downloaded a CAD model on Digikey for the
SHT45 sensor. I will be using the SHT45-AD1B-R3 sensor.

A diagram of a device Description automatically generated{width="6.055555555555555in"
height="2.6829199475065617in"}

Aside from the two components mentioned above, we also need the power
components. I will be using a fixed 3.3V voltage regulator that accepts
up to 18V input. Looking through the documentation, I decided to choose
the LDL1117S33R chip.

For the voltage input, I will be inputting 12V via a barrel jack to the
PCB board. The input will be from a WSU 120-2000 AC/DC wall mount. The
barrel jack will be a PJ-202AH jack.

We will also have decoupling capacitors throughout the circuit for the
signals.

There are some issues with the voltage regulator on KiCAD. The reason is
that there are two 3.3V output pins. It is not exactly passing the
Inspection Test. If it still does not work, I will simply change to a
different voltage regulator.

Aside from that, I still need to wire the BOOT and RESET buttons, as
well as the USB bridge.

I found a good link from Espressif regarding wiring the ESP32. It has
the USB-UART and USB-Bridge wiring too, as well as the buttons. It is
the same ESP32-S3-Devkit-C board with the VROOM-1. I was going to do the
USB-UART, but looking at the schematic, it looks like it has too many
components, and is difficult. I will probably figure out how to program
the USB-Bridge instead.

**Monday, March 4, 2024**

**Objective: Work on PCB and improve yesterday's design**

Today, I will continue working on the PCB design. I will working on the
micro-usb-b part.

Looking at the Espressif schematic, I can see that the micro usb
provides a 5V connection. We will not be using the 5V, therefore, I will
be omitting that. I am following the Espressif schematic below to do
most of the PCB schematic. I hope to use the same parts also, even
though they may be from China.

I am getting some errors for the ESP32 footprint. There are some
through-holes in the middle of the chip. Talking to Peter, a friend from
ECE395, he says that they are for heat dissipation. I can ignore it or
remove the holes in the footprint editor. For the first revision of this
board, I will remove it. This is the prevent extra costs. I will talk to
Jason about the holes.

I have finished the prototype. I have submitted the board to PCB-Way,
and it passed all tests and is ready for production.

**Tuesday, March 5, 2024**

**Objective: Turn in PCB design, meet Surya.**

Early today, I finished the schematic and PCB layout. I will review it
with Jalen this afternoon before we email the file to Surya.

During the meeting with Jalen, we did not find any issues with the
schematic. Everything looks ok.

I have sent the email to Surya.

In the meeting with Surya, we also told him our plan for Spring Break.
We hope to finish the humidifier subsystem's PCB over Spring Break.
Surya says he is quite happy with our progress on our PCB when compared
to the other groups.

Order some parts for PCB, primarily BJT and Diode from China. It will
take two weeks to arrive, so it will arrive on time after Spring Break.

**Monday, March 18, 2024**

**Objective: Work on Humidifier PCB, talk to Jalen**

Today, I am working with Jalen on the humidifier PCB. We have previous
communicated on what needs to be done. Right now, my first problem is
converting my KiCAD 8.0 file t0 KiCAD 7.0. The reason is because KiCAD
8.0 is less than a month old, and it has [a lot]{.underline} of bugs.

I tried finding ways to directly convert the files, and it seems like it
is not possible. Also, the symbol and footprint library has already been
converted to KiCAD 8.0 version. So, I will have to re-import all the
symbols and footprints again. This will be a bit tedious. I think I will
have to redraw the schematic and PCB again.

After redrawing the circuit from the sensor subsystem, I fixed any
errors.

Next, I helped Jalen with the relay. He said that we needed an
optocoupler. This is used to prevent noise. I did some research and
decided "why not". It was a bit difficult finding parts for the
optocoupler, as we were not sure what to look for. Furthermore, most of
the parts on Digikey that we clicked on did not have EDA files. I ended
up going to SnapEDA and searching for optocoupler and clicking the first
item. The first was the VOM617AT. The specs looked ok, and it had a
stock of over 6000 on Digikey, so it must be decent. I suggested it to
Jalen. He thinks we should try it out.

A diagram of a circuit Description automatically generated{width="5.152777777777778in"
height="2.75in"}

After more discussion, it seems like Jalen's initial understanding of
what the relay does was flawed. He thought that the relay also provided
power for the ESP32. However, it is the ESP32 that powers the relay. The
120V on the end of the relay does not go to the low power side.

We will be using a premade transformer to power the ESP32. We decided
that it was not worth the time and trouble to make one. We will be using
the EPS-15-12 120V AC to 12V DC transformer. I will also connect the DC
end to a barrel jack for the PCB.

A table with numbers and symbols Description automatically generated{width="6.5in"
height="2.2006944444444443in"}

Order some more parts from Digikey for the humidifier PCB. Total was
around \$67.00.

**Tuesday, March 19, 2024**

**Objective: Work on humidifier PCB, turn in PCB, meet Surya, discuss
water valve**

Today, when talking to Jalen about the water valve, we discovered that
our water valve might not work for the demonstration. The problem is
that the water valve requires a minimum pressure for it to activate. It
does not work by gravitational water pressure. We will have to find a
different valve that has no pressure rating.

We found a new valve on Amazon that require little to no pressure to
work. The downside is that this controller uses quick connect. Also, we
don't know how much pressure will be during the demo.

This new valve requires 12V DC to power. Originally, we were going to
use some kind of motor controller to control it. However, it occurred to
me that the relay could use 12V DC. This will be perfect for the ESP32
sending 3.3V activation signal, activating the switch, and sending 12V
to the motor.

The only uncertain thing is how does the valve close. Looking at the
description, it seems like the valve will close on its own. We will try
it out later.

When meeting with Surya today, we told him about our progress. He told
us that we should start talking to the machine shop. I told him that I
will do it this week. He says that the machine shop should be working on
our parts now. However, he is still happy that we are making good
progress compared to the other teams.

**Thursday, March 21, 2024**

**Objective: Talk to machine shop**

Today, I brought the humidifier and PCB parts to the machine shop. I
also drew some diagrams to show the machine shop what needs to be done.

A white paper with blue writing on it Description automatically generated

A white paper with blue writing on it Description automatically generated

I think that Gregg understands the idea. However, because we are still
waiting for parts, he cannot begin working on it yet. Gregg requested
that I give him a sample of our PCB and the water valve. He says he will
be on vacation for a week starting the coming Monday. I told him I will
get it to him tomorrow, as the valve is arriving tomorrow.

**Friday, March 22, 2024**

**Objective: Parts did not arrive**

The valve did not arrive today yet. I think some motherfucker stole my
package. I went to see Gregg to report the bad news, and apparently, he
had already left for his vacation!?

**Sunday, March 24, 2024**

**Objective: Woojin got ESP32s to send data**

Today, Woojin announced that he got the communication between two ESP32s
to work. The original plan was to control the LED of one ESP32 from
another ESP32 over 2.4GHz Wi-Fi. However, Woojin went above and beyond
by being able to send the SHT45's data to another ESP32 and being able
to read it.

**Monday, March 25, 2024**

**Objective: Order parts from funding**

Order parts for humidifier subsystem. I think that this will be the last
order from the \$150.00 budget that we have. This order is mainly UART
chips and plugs for the transformer that we missed.

**Tuesday, March 26, 2024**

**Objective: Meet Surya, test water valve**

Today, the water valve arrived. I tried to test it. However, initially,
I was confused on how it works. I can hear it clicking, but looking in
the hole, I did not see the valve opening. As a result, I took it apart
and found the below:

A small white and blue device Description automatically generated{width="5.536082677165354in"
height="7.381443569553806in"}

As seen in the picture, this is not really a valve, but a plunger. It
works with a coil. When there is a current through the coil, a magnetic
field will be created and the valve will be sucked upwards, thus opening
the valve. The valve is normally closed when there is no current going
to it. The manufacture's specification says that it draws around 4.8W.
This means that there is 0.4 amps flowing through it.

$$4.8W = I*12V$$

$$I = 0.2A$$

This should be enough for our applications. The only worry is that the
seal might not be great. However, since our real valve will not be like
this, as this is an "unpressured valve", it will not be a real problem.

We met with Surya; I told him to good news about Woojin getting the
sensors to send data over Wi-Fi. Surya tells us to contact the machine
shop to see how progress is. Surprisingly, we still have around \$30 of
budget left. We may use it to order our second water level sensor.

**Wednesday, March 27, 2024**

**Objective: Order parts for humidifier, determine power input for
humidifier subsystem**

Today I had to order some parts for the humidifier subsystem. I had to
figure out a way to power the PCB, and I thought that the best way would
be to use a switching regulator. I thought about making our own power
supply, however, with the limited cost and time, I think it would be too
difficult. Also, it is highly unlikely that we can build one for cheaper
than buying one at around \$6.00. Furthermore, the pre-built ones have
surge protection built in, and this is important for voltage spikes. We
will not be sure if our own design can protect against this, and it is
too risky frying all the other components.

We only need a 12V input in our humidifier subsystem. As a result, over
multiple hours of research, I decided on the ESP-15-12 AC/DC converter.
This can provide a 12V DC output with a 1.25A current output. I estimate
that this should be enough for the PCB and the water valve. Looking at
the diagram below, I will also need to buy some plugs for the input and
output.

A diagram of a circuit board Description automatically generated{width="6.5in"
height="4.848611111111111in"}

I was able to find some suggested ones on Digikey with a crimp
connection. I hope that this will work.

Aside from that, I also must think about a way to send the 120V AC into
the subsystem, and a way to power the humidifier. I did not want to make
any difficult changes to the humidifier's fan. As a result, I came up
with the idea below:

There would be a box. There will be an input power into the box through
a wire. This wire can be unplugged anytime. This leads to the
portability of the box. There will be a the 12V AC/DC converter in the
box. This converter will go feed the PCB and other components.

Along with the AC/DC converter, I bought a couple varying parts for the
idea above. This was in Digikey order: 860944423.

Aside from that, I also ordered a relay development board from Digikey.
This was part number 1528-1738-ND. I wanted Woojin to start working on
developing the GPIO functionality as soon as possible.

Finally, we paid for 2 day shipping on the order, so that it can get
here by the weekend.

We also used our remaining budget by ordering another Optomax Digital
Liquid Level Sensor. This will use up all our remaining budget.

**Friday, March 29, 2024**

**Objective: Solder relay dev-board**

Today, the parts and the relay arrived. I could not really do anything
with the parts, as the machine shop still needs to work on the project.
We will need to talk to them soon. The development board for the PCB
seems pretty compact, so our PCB will also be compact.

A small black electronic device on a silver surface Description automatically generated{width="5.273611111111111in"
height="7.031481846019248in"}

**\
**

**Saturday, March 30, 2024**

**Objective: Solder PCB for sensor subsystem**

Today, Jalen and I started soldering the humidity sensor PCB. However,
we discovered that we were still missing some SMD components from the
ECE Electronics Supply Shop. I immediately sent an email to Surya so
that we can get some. However, since we were already at ECEB, Jalen and
I laid the paste and soldered with the parts we have on hand. We took a
while, as I was teaching Jalen how to lay the parts on the PCB. But we
were finished.

The ESP32 was a little bit hard to solder. The ground pads were hard to
heat up. Maybe the iron was not powerful enough. We will finish
soldering in another day when the parts arrive.

A person looking through a microscope Description automatically generated{width="4.714285870516186in"
height="6.285714129483814in"}

**Tuesday, April 2, 2024**

**Objective: Meet Surya, show Surya our PCB, address issues with PCB**

Meeting with Surya today, we told him that we will be working on our PCB
ASAP since parts are here. Surya also asked us to check in with the
machine shop, and we told him that the machine shop is working on our
parts, but there is delay. However, the machine shop did tell us to not
worry.

Tonight, Jalen and I worked on soldering the rest of the first sensor
subsystem PCB. It turned out to be a bad idea to not do all the
soldering at once, as we had to remove all the old solder off the pads
before laying new paste.

After fixing some bridging in certain parts of the chip, we were able to
plug the PCB into our 12V wall power supply. This 12V was from my
previous class in Fall 2023. We were able to program a basic program to
the ESP32.

However, when I tried to program a sample Wi-Fi access point code to the
ESP32, the ESP32 initially worked then started crashing. The symptom is
that, on the serial monitor, it would show that it was connecting and
disconnecting. Also, the voltage regulator and the surrounding
capacitors got really hot. In fact, it got so hot that it was
uncomfortable to the touch. Ultimately, the voltage regulator fried
itself and stopped outputting 3.3V. Thankfully, it output 1.5V, so it
did not fry the ESP32.

We think that the regulator might be defective, so we changed it for
another one. Though the new one did not fry itself, it still had the
issue where the ESP32 would keep connecting and disconnecting.

It was 3-4am, so we decided to go home and solve it the next day.

A person sitting in a chair in a room with a desk and a robot Description automatically generated{width="5.913580489938758in"
height="7.884771434820648in"}

**\
**

**Wednesday, April 3, 2024**

**Objective: Debug PCB, why it is constantly restarting**

I started a Reddit post on r/ESP32 to ask why I was experiencing this
problem.

A screenshot of a computer Description automatically generated{width="6.5in"
height="4.189583333333333in"}

I did some research on why this might be. There are similar symptoms
online. It seems like the reason for this is because the Wi-Fi module on
the ESP32 draws a lot of current. As a result, the power draw through
the voltage regulator is high. Maybe with a better power supply, the
ESP32 will not "throttle".

A white electronic device with a screen and buttons Description automatically generated{width="6.5in"
height="4.875in"}

A Reddit user suggested using the power supply from the lab bench and
using a lower voltage. The reason is with a high voltage difference in
the input and output of the linear voltage regulator, the difference is
dissipated as heat.

As a result, I first tested the bench power supply at 12V. It still had
the throttling issue, even though enough current was supplied. Next, I
started decreasing the voltage by 1V increments. I noticed that starting
at 8.0V and below, the ESP32 would no longer throttle. This means that
we should figure out a way to decrease the voltage supply.

I talked to Stephen Messing, a PhD student from the Laser Optics Physics
Laboratory research group (Andrey Mironov and Gary Eden), and he
suggested putting linear voltage regulators in series, with increment
decreases in voltage. This will decrease the voltage drop and balance
out the power draw through each regulator.

A person standing next to a whiteboard Description automatically generated

Ultimately, I decided to use a 5V wall plug the power the sensor
subsystem, and a RS-15-5 AC/DC converter to power the humidifier
subsystem's PCB. I also bought a new AC/DC converter. Instead of the
previous one, this one has an isolation case. Also, the inputs and
outputs are screws. This makes it easier to wire.

**Thursday, April 4, 2024**

**Objective: Draw diagram so Woojin can understand, solder humidifier
subsystem PCB**

In ECE343's lab, I drew this diagram detailing the idea behind the
humidifier subsystem.

A screenshot of a computer Description automatically generated{width="6.5in"
height="4.508333333333334in"}

The diagram above shows the inputs and how the different components will
be powered. I hope that this will help Woojin understand how everything
goes together better.

Later that night, I took the burden upon myself to solder the PCB for
the humidifier subsystem. Jalen said he can help on Saturday, but that
is already too late. This is because I may need to order parts on
Friday.

**Friday, April 5, 2024**

**Objective: Solder PCB for humidifier subsystem, debug PCB**

I finished the PCB early Friday morning. I just soldered one relay and
one water level sensor input.

A green circuit board on a black surface Description automatically generated

When I programmed it, the PCB works with Wi-Fi with a 5V input. However,
GPIO 19 and 20 were not outputting signals to the relays. I think that
the ESP32 was not soldered on properly. So, I tried to remove the ESP32.
I think I heated the board too hot because there was smoke. Also, upon
inspection, the UART chip had a hole in it and the push buttons were
disintegrated. At 5:40am, I gave up and decided to go home.

When I got home, I also worked on ordering new parts. I ordered a couple
more ESP32s, relays, UART chips, and other various parts that can be
used on the sensor and humidifier subsystems. This is so that we don't
need to wait for parts if we need any.

At night, I went to Home Depot with Taiyuan (Daniel) Hu to get some
parts. I got some 14 gauge Romex wires, 5 input WAGO connectors, 2 input
WAGO connectors, Klein no-contact voltage tester and IR thermometer, and
a Milwaukee wire stripper and crimper.

**Sunday, April 7, 2024**

**Objective: Make revisions for humidifier PCB, improve design on final
round**

Today, I worked on some PCB revisions to the humidifier PCB. Because
Tuesday, April 9, 2024, is the fifth round of PCB orders, we needed a
fail-safe for our humidifier subsystem. I made 5 PCBs. The first order
is another order of our, already working, sensor subsystem. The next is
an order of our humidifier subsystem from the second round. The third
board is the same, but with the GPIOs for the relays moved. The fourth
board is a re-routing of the traces in the third board. The fifth board
contains cutouts for the high voltage. I spent the whole night doing
this and finished early in the morning.

**Monday, April 8, 2024**

**Objective: Talk to machine shop about our project**

Today, I talked with the machine shop. I needed to talk to Gregg about
our project, as he sent us an email saying he came back from vacation.

When I went in to talk to Gregg, it turns out that he was involved in a
car accident in the morning of March 22, 2024. As a result, he was not
able to come back to ECEB. He had a scar on his upper right eyebrow. I
went over the project with him, and he said I should get a call in the
next few days to the end of the week.

**Wednesday April 10, 2024**

**Objective: Meet Surya, talk to him about machine shop, solder
remaining PCBs**

Today we met with Surya. Surya asked how the PCBs were going, and I told
him that we are working on it. After the meeting, Woojin and I decided
to solder the remaining two sensor subsystem boards. I taught Woojin how
to place the components and paste the board with the stencil.

A person looking through a microscope Description automatically generated{width="3.4175251531058617in"
height="4.556700568678915in"}

I did the ESP32 chip, as Woojin does not have experience to do it, and I
don't want him to mess up. We finished early Thursday morning. We tested
the boards with the programs, and they all work on the first try.

A group of green electronic components on a black surface Description automatically generated{width="6.5in"
height="4.875in"}

**Thursday April 11, 2024**

**Objective: Test humidifier PCB, figure out what is wrong**

Today, I decided to solder the humidifier board with our replenished
parts. The reason why I did not want to wait until Saturday to do it
with Jalen is because there will be no time to buy new parts on Saturday
and have it ship.

I finished soldering the board with just one relay like last time.
However, before soldering the ESP32, I tested the voltage divider from
the water level sensor to make sure it outputs 3.3V to the ESP32.

$$V_{out} = \ V_{in}*\frac{100}{100 + 200}$$

$$V_{out} = 3.333V$$

After the verification with the multimeter, I was comfortable to solder
the ESP32 on.

A green circuit board with black wires Description automatically generated

Upon testing the board, I can see that it is fully working. I realized
that the first time that I did it, the board fully works. Maybe it was
late that night, but I got GPIO number, and the pin number confused on
the program.

I also bridged the connection in the through holes. This will avoid the
optocoupler, which did not work. Also, because the ground is shared, the
optocoupler was pointless.

In the day, I went to the machine shop the bring them my new AC/DC
converters with the isolation cage. Also, it was to check in with Gregg
on when they will start working on the project.

Gregg asked around the shop for who was interested and available to work
on our project. He assigned us to Skee Aldrich. I went over the
components with Skee and the functionality. We picked a clear box for
the humidifier subsystem. This was the only box left that can fit the
components. It looks good.

**Friday, April 12, 2024**

**Objective: Work on the box containing humidifier PCB, test input
voltage**

Today, Jalen and I was going to wire the board up. We needed to test the
AC components. At around 15:50, I went to the machine shop to get some
parts for us to use. Skee had already left, but I asked Gregg if I could
borrow the parts. Gregg said sure, but I had to return it Monday morning
at 8:00am. I promised him that I will do it.

With the box, Jalen and I mock-placed the components. A close-up of a device Description automatically generated

We also tested the functionality of the transformers. We determined that
the 5V transformer was not working, as the adjuster only output 4.2V.

**\
**

**Sunday, April 14, 2024**

**Objective: Resolder second humidifier subsystem PCB with new parts**

Today, I finished up soldering the rest of the humidifier subsystem's
PCB. I added the remaining relay and the water level sensor input. This
was because we have a mock demo on Tuesday. A hand holding a green circuit board Description automatically generated{width="5.304124015748031in"
height="7.072165354330709in"}

Tonight, Woojin got the HTML webpage up. Our data can be read on the
website, though a little bit low.

**Monday, April 15, 2024**

**Objective: Give parts to Skee, wire up box**

I went to ECEB at 7:55am to hand the parts to Skee. Gregg was very happy
that I showed up on time in the morning.

Skee finished up the boxes today, so I can work on wiring them up today.
However, he still needed to work on the water tank for us to demo. I
also noticed that he did not make holes for the sensor subsystem boxes.
The holes are for the power cables to go through. I will bring it to him
tomorrow morning.

I spent the night wiring the humidifier box up.

**Tuesday, April 16, 2024**

**Objective: Test enclosure for PCB in the humidifier subsystem, meet
Surya for mock demo**

Early this morning, I finished wiring the whole humidifier subsystem.
Prior to plugging the humidifier in, I used the non-contact voltage
tester to see if there are voltage leakage. There was not, so I plugged
the humidifier in. Using Woojin's webpage, the fan was able to be turned
on and off. I was happy with this result.

A computer and a phone on a desk Description automatically generated

In the afternoon, I spent my time wiring the water level sensors and the
wires for the water valve. I bought the parts from the ECE supply store.
I also heat-shrunk the wires. Later in the afternoon, we did a practice
presentation with Surya. Surya told us to clean up the wiring. I will
heat shrink the wiring some more.

A machine with wires connected to it Description automatically generated

**Wednesday, April 17, 2024**

**Objective: Heat shrink wires, join some wires**

I cleaned up the wiring a bit with ½ inch heat shrink. However, the heat
shrink was only 6 inches long. As a result, I had to use multiple
sections. The heat shrink was from different manufacturers, so the
colors were different. I was not pleased with the result, so I bought
some marine grade waterproof heat shrink from Amazon. The order will
arrive Friday.

A hand holding a black wire Description automatically generated{width="6.5in"
height="8.666666666666666in"}

**Friday, April 19, 2024 and Saturday, April 20, 2024**

**Objective: Heat shrink wires, test voltage and temperature output,
make tables and graphs**

Lingxian Cai, a friend of mines fried their ESP32, and a new one will
not arrive until Monday. So, I gave our last spare one to him.

With the new 10ft long heat shrink, I worked on heat shrinking the wires
into one. I also planned to connect the water level sensors.

The heat shrink was horrible to get on the wires. The waterproof heat
shrink had a tacky layer inside. As a result, sliding the heat shrink
over the wires was very difficult. It took me 2 hours to get it over our
2.5 feet of wire.

After that, I connected the water level sensors to the wires I just heat
shrunk. Originally, I wanted to crimp the wires, as that allows the
proper connection. It is used in aerospace. However, the crimps were too
large for the heat shrink. As a result, to keep the clean look, I
soldered the wires. I stripped it 2 inches so that the contact surface
will be maximized.

Close-up of several wires Description automatically generated{width="5.511482939632546in"
height="4.133612204724409in"}

After soldering, I did continuity testing to make sure the connections
were good before heat shrinking the connections. A black and blue device with wires Description automatically generated

The result was very clean. For the water valve wires, I need to go to
the supply store to get two new female connectors, as the original was
damaged when I was pulling the heat shrink over the wires.

Later at night, I worked with Woojin and Jalen on our presentations and
handouts for the demonstration. The demonstration is April 23, 2024, at
9:30am in 2072.

Woojin also worked on verifying the runtime and proving that 44ns is
unrealistic. He also updated the water level sensor algorithm. I
discovered a couple days ago when demonstrating to Surya on the mock
demo that the algorithm did not make sense. Previously, it would only
fill water when both sensors detect no water. However, when the lowest
sensor detects water, it will stop filling. As a result, the water level
will never go to the top sensor. Woojin also made an offset algorithm
for the humidity data and the temperature to compensate for the box
design.

Jalen and I also did our RV table verifications. Below are the graphs of
data that we collected for the voltage input over 1 hour:

A graph of a graph of a graph of a graph of a graph of a graph of a graph of a graph of a graph of a graph of a graph of a graph of a graph of Description automatically generated{width="6.5in"
height="2.2098764216972877in"}A graph of a graph of a graph of a graph of a graph of a graph of a graph of a graph of a graph of a graph of a graph of a graph of a graph of Description automatically generated{width="6.5in"
height="2.0740737095363078in"}

A table of numbers with numbers Description automatically generated{width="6.5in"
height="5.999305555555556in"}

We were also able to confirm that our three sensor readings matched that
of the commercial humidity and temperature sensor from Amazon.

A hand holding a phone over a digital device Description automatically generated{width="5.19807852143482in"
height="3.5688538932633422in"}

Woojin did the runtime test, and the runtime was 90,000ns for a two way
communication. This is around 45,000ns for SHT45 to the humidifier
subsystem's ESP32. This is because there is a lot of data to pack and
unpack, as well as other delays when running the code. Therefore, we
verified that the 44ns was unrealistic theory.

**Monday, April 22, 2024**

**Objective: Print handout at FedEx, buy parts at Home Depot, finish
wiring**

Today, I printed 4 copies of the handout at FedEx. I printed the copies
using 32g paper for a more professional and premium feel.

I also went to Home Depot again to pick up heat shrink, 0.250 female
connectors for 18-22 gauge wires, and water resistant heat shrink.

At night, we double checked the PowerPoint and did some practice
presentations. Woojin added 8 sources to the bibliography. Woojin needs
more practice on the presentation.

While Woojin left early, Jalen and I finished the water pump's wiring.
We tested everything in the humidifier subsystem and confirmed
everything worked.

**Tuesday, April 23, 2024**

**Objective: Present demonstration**

After going home, I continued to look through the PowerPoint to make
sure everything looks correct. I added descriptions to the photos in the
PowerPoint. I also told Woojin what to say for the 44ns. I made sure all
our verifications were met. I also practiced speaking every slide on the
PowerPoint, so that I know everything.

In the morning, I arrived at ECEB at 8:30. I got the study room across
the ECE411 OH room. I plugged the sensors in and made sure everything
worked. Woojin came in, but Jalen was really late. Luckily, he arrived
on time for the presentation.

The presentation went spectacularly. Professor Schuh and the second TA
were impressed with our project. The professor's face lit up when we
unplugged one sensor, and the average was recomputed with just two
sensors. Surya said in text that we earned 10 points for complexity!

A screenshot of a chat Description automatically generated{width="4.525773184601925in"
height="3.2439523184601926in"}

A group of men standing in a room Description automatically generated

**Saturday, April 27, 2024**

**Objective: Prepare for final presentation, 3D scan product**

We met today to work on the final presentation PowerPoint. There was not
a lot of things to add, as our previous PowerPoints already had graphs
and data. We did, however, add schematics of our PCB and added a slide
about the challenges we faced. On top of that, I 3D scanned our
humidifier and the sensors. This will be used on the PowerPoint as a
looping video.

**Monday, April 29, 2024**

**Objective: Present final presentation**

Today was our final presentation. We spoke for 20-21 minutes, so the
timing was very good. However, Professor Schuh asked a very tricky
question at the end of the presentation. We had one bullet point stating
that we can modularize our humidifier by removing the water level
sensors and the water valve. However, Schuh brought up doesn't that
point negate one of our high levels. I did not want to answer his
question directly, so I danced around the question. The reason why I put
the bullet point was because we need to design a new humidifier from the
ground up to have our full working project. However, we do not have the
funding for that.

**Tuesday, April 30, 2024**

**Objective: Work on final report**

Today, we worked on the final report with Woojin and Jalen. Most of our
report was a carry-over from the design document. However, some things
had to be updated, as we are now using relays and 5V as input to the
PCB, for example. We updated our labor table, as seen below:

A table with numbers and a group of men Description automatically generated{width="6.5in"
height="3.026388888888889in"}

We estimated that there are 24 hours of work done by the machine shop.
This is because the machine shop worked on our project for three 8-hour
workdays. We also discussed the total amount of hours we each put in the
project. There were some slight discomforts when discussing the hours
that Woojin spent on work. Though we agreed to put 2 hours and 0.5 hours
for Circuit Design and PCB Design for Woojin, this is just a "show of
face" to Woojin. The reason is that he basically did 0 hours for both of
those two categories. He does not even have the KiCad files on his
computer and is not clear about how the circuit works. He did do
software engineering, but 78 hours is a stretch. The software he wrote
was primarily using libraries and example code. He claimed it took him 5
hours to figure out GPIO signals, but not only did I send him example
code at the beginning of the semester, but GPIO read and write only
takes 15-30 minutes to learn. Woojin did help solder for 5 hours and did
help with troubleshooting. But the amount of work he performed was not
satisfactory, as he was always busy with other classes.

Jalen's hours are accurate, as I worked closely with him all semester.

At the end of the night, we realized that we still had to
cross-reference figures and citations. We decided to finish that the
next day.

**Wednesday, May 1, 2024**

**Objective: Conflict between members on labor table, turn in final
report**

Woojin was not able to make it to help us do the cross-reference, so
Jalen and I worked on it earlier. It took us two hours to finish, and it
was just as I predicted yesterday.

We submitted the paper. However, at 17:30, Woojin called me and asked me
to take down the labor table. He says that while some teams like Fall
2022's CHARM has it, many other teams do not have it. I got the feeling
that he was uncomfortable and embarrassed with the amount of work that
he did. I did not like his idea because that would discredit all the
work that Jalen and I did. Woojin says that we can just include the
total hours, in fact he can even decrease his hours to 145. I told him
to talk to Jalen about it. If Jalen agrees, then I will change it. Jalen
agrees since he did not want to cause trouble, and I updated it to the
table below:

A black line with black text Description automatically generated{width="6.5in"
height="1.0138888888888888in"}

I kept it at 155 hours for Woojin as I feel like it honors his work.
However, Jalen and I are not very satisfied with this. However, I did
push it on the website as we agreed on. I left the first version as
"confidential".

Woojin went on Discord to ask us to remove the original version from the
server. I said I will not do that, as it is already confidential. He
tried calling me, but I ignored his call.

A screenshot of a chat Description automatically generated{width="5.148148512685914in"
height="4.598133202099738in"}

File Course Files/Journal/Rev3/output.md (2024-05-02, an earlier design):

**Tuesday, February 06, 2024**

A notebook with writing on it Description automatically generated{width="6.361111111111111in"
height="8.481481846019248in"}

**Wednesday, February 07, 2024**

Today, we talked to the machine shop. Prior to going, I made a
PowerPoint describing what we wanted to do. In the PowerPoint, I
included some images, such as a visual aid, and images of parts that we
may use.

In the machine shop, Gregg told us that they will not build a new
humidifier for us. However, they will be happy to modify one from
Amazon. He suggests that we get one that is simple, with a manual on-off
function. Also, it is preferred that it is square, so that it will be
easier to mount things without leaks.

A notebook with writing on it Description automatically generated{width="6.5in"
height="8.666666666666666in"}**\
**

**Thursday, February 08, 2024**

A notebook with writing on it Description automatically generated{width="8.36111111111111in"
height="6.270833333333333in"}

**Wednesday, February 14, 2024**

**Objective: Meeting with Surya, discuss machine shop, discuss using
GitHub for journal**

Today we had a meeting with Surya. We went over our meeting with the
machine shop. I told Surya that we are not able to have a rotating head
as originally proposed. The reason is that the machine shop does not
want to build a humidifier ground up for us. Also, the machine shop just
wants to modify a humidifier to fit our needs. Surya told us to think of
another high level to fill in for the rotating head. We said that we may
do automatic water refilling. Surya also reminded us to sign up for the
design review, which is opening on Friday.

I also asked Surya if, instead of writing physically on a journal, I can
change to GitHub. He says yes, and to make sure to submit the journal at
the end of the semester.

**Thursday, February 15, 2024**

**Objective: Pick part with Jalen, what sensor and ESP32 to use**

I worked to Jalen picking out parts for our project. We needed to figure
out what water level sensor to use and what humidity sensor to use. We
did a lot of research to see what sensors met our needs in price and in
function. Also, we had to decide on what microcontroller we should use.
There are many versions of the ESP32, and we need to decide on one.

After doing research, we are leaning on using the ESP32-S3-WROOM-1-N8.
The reason for this is because we don't need the extra DRAM from other
versions, and the S3 has a UART-USB chip.

**Friday, February 16, 2024**

**Objective: Text Surya about buying ESP32 board**

Today, I texted Surya about ordering a development board. He says that
there are some ESP32 development boards that we can check out in ECE445.
He will get back to me about it next week. I told Surya that we will
check it out in our meeting next week.

**Tuesday, February 20, 2024**

**Objective: Meet with Surya, discuss proposal, place order for sensor,
rent ESP32 Dev Board**

Today we met with Surya. We talked about our progress with the project
and the due dates coming up. Surya told us about our scores for our
proposal report. It was a bit low, but he says we can still make changes
to it and submit it on Friday. He says that the other TA who graded the
paper was strict about the scores. We were missing some requirements,
which we will update. He also told us to look at CHARM's paper. We
originally did that too, but this time we will also reference the
rubric. We will continue working on the project. We told Surya we are in
the process of picking parts for the project.

We told Surya that our new high level will be to read the water level
and automatically fill the water tank.

Today, we also placed the order for our water level sensor. We chose the
Optomax Digital Liquid Level Sensor as it seems easy to work with and is
well waterproofed. The only downside is that it is \$24.99. We only
ordered one to make sure it works.

Aside from that, we borrowed 4 ESP32-S3 development boards from ECE445.
Surya helped sign it out for us. Jason asked why we needed so many
boards. We told Surya that I needed two to work on two ESP32's
communicating over Wi-Fi. Jalen needs one to work on the water level
sensor and motor controller. Woojin needs one for the humidity sensor.

**Wednesday, February 21, 2024**

**Objective: Write design document, make table for parts and labor**

We worked on our design document today. Woojin, Jalen, and I had a Zoom
call. We worked on the paper together. We wonder why this class takes so
much time on the writing. It is more than 4 credit hours. We were able
to transfer a lot of our paper from the proposal over to the design
document. We also made an estimated labor table, as well as the
estimated parts list as shown below:

A screenshot of a spreadsheet Description automatically generated{width="6.5in"
height="2.4618055555555554in"}

**Friday, February 23, 2024**

**Objective: Update proposal and rebsubmit**

Today, I worked on updating the proposal. I updated the block diagram on
the proposal as well and the citations.

Later in the day, I started working on the PowerPoint for the design
review on Wednesday next week.

**Monday, February 26, 2024**

**Objective: Ask Surya if schematics are needed for design review**

Today, I texted Surya if we needed schematic diagrams on our
presentation. He says that we do not. So, I did not make any edits to
our presentation.

**Wednesday, February 28, 2024**

**Objective: Present design review, meet Surya.**

Today, we the design review. There was no meeting for this week. Thanks
for Surya, we dressed up for the design review and came prepared for the
presentation. Professor Schuh did not ask us many questions. The only
suggestions that he had were to include temperature in the algorithm for
the humidifier, update the block diagram, and looks at built in
humidifiers in houses for inspiration. Surya says that we were the first
team to get full marks on the professionalism category.

A chat message with text Description automatically generated with medium confidence{width="6.5in"
height="2.013888888888889in"}

We went to a peer review, and they just read off their Google Doc. I am
glad we make a PowerPoint.

I also made some edits to the block diagram. I updated the signals for
the DC motor controller, as the ones in the proposal did not make sense.
I also made the data and power lines more readable with new colors
added.

A screenshot of a computer Description automatically generated{width="6.5in"
height="5.455555555555556in"}

**Sunday, March 03, 2024**

**Objective: Work on PCB for sensor subsystem**

Today, I began working on the PCB schematic for the sensor subsystem.
Yesterday, Woojin showed me his completed work on the Adafruit SHT45
development board. He showed me the output and proved that the ESP32 can
communicate with the SHT45 and read data from it.

Because we want to make it to the first PCB order group (coming
Tuesday), I will make a draft of the PCB schematic today.

The first thing that I did was find the ESP32-S3 microcontroller on our
ESP32-S3 development board. Doing some research, I believe that it is
the ESP32-S3-VROOM-1-N8. I downloaded the CAD file on Digikey, so that I
can import it to KiCAD.

Next, I looked at the SHT45 sensor. I went on Sensirion's website and
looked through the documentation. They had a sample circuit. I think I
will base my schematic on that, as the Adafruit development board has a
lot of "fluff" on it. I also downloaded a CAD model on Digikey for the
SHT45 sensor. I will be using the SHT45-AD1B-R3 sensor.

A diagram of a device Description automatically generated{width="6.055555555555555in"
height="2.6829199475065617in"}

Aside from the two components mentioned above, we also need the power
components. I will be using a fixed 3.3V voltage regulator that accepts
up to 18V input. Looking through the documentation, I decided to choose
the LDL1117S33R chip.

For the voltage input, I will be inputting 12V via a barrel jack to the
PCB board. The input will be from a WSU 120-2000 AC/DC wall mount. The
barrel jack will be a PJ-202AH jack.

We will also have decoupling capacitors throughout the circuit for the
signals.

There are some issues with the voltage regulator on KiCAD. The reason is
that there are two 3.3V output pins. It is not exactly passing the
Inspection Test. If it still does not work, I will simply change to a
different voltage regulator.

Aside from that, I still need to wire the BOOT and RESET buttons, as
well as the USB bridge.

I found a good link from Espressif regarding wiring the ESP32. It has
the USB-UART and USB-Bridge wiring too, as well as the buttons. It is
the same ESP32-S3-Devkit-C board with the VROOM-1. I was going to do the
USB-UART, but looking at the schematic, it looks like it has too many
components, and is difficult. I will probably figure out how to program
the USB-Bridge instead.

**Monday, March 4, 2024**

**Objective: Work on PCB and improve yesterday's design**

Today, I will continue working on the PCB design. I will working on the
micro-usb-b part.

Looking at the Espressif schematic, I can see that the micro usb
provides a 5V connection. We will not be using the 5V, therefore, I will
be omitting that. I am following the Espressif schematic below to do
most of the PCB schematic. I hope to use the same parts also, even
though they may be from China.

I am getting some errors for the ESP32 footprint. There are some
through-holes in the middle of the chip. Talking to Peter, a friend from
ECE395, he says that they are for heat dissipation. I can ignore it or
remove the holes in the footprint editor. For the first revision of this
board, I will remove it. This is the prevent extra costs. I will talk to
Jason about the holes.

I have finished the prototype. I have submitted the board to PCB-Way,
and it passed all tests and is ready for production.

**Tuesday, March 5, 2024**

**Objective: Turn in PCB design, meet Surya.**

Early today, I finished the schematic and PCB layout. I will review it
with Jalen this afternoon before we email the file to Surya.

During the meeting with Jalen, we did not find any issues with the
schematic. Everything looks ok.

I have sent the email to Surya.

In the meeting with Surya, we also told him our plan for Spring Break.
We hope to finish the humidifier subsystem's PCB over Spring Break.
Surya says he is quite happy with our progress on our PCB when compared
to the other groups.

Order some parts for PCB, primarily BJT and Diode from China. It will
take two weeks to arrive, so it will arrive on time after Spring Break.

A blueprint of a circuit board Description automatically generated{width="6.5in"
height="7.838888888888889in"}

**Monday, March 18, 2024**

**Objective: Work on Humidifier PCB, talk to Jalen**

Today, I am working with Jalen on the humidifier PCB. We have previous
communicated on what needs to be done. Right now, my first problem is
converting my KiCAD 8.0 file t0 KiCAD 7.0. The reason is because KiCAD
8.0 is less than a month old, and it has [a lot]{.underline} of bugs.

I tried finding ways to directly convert the files, and it seems like it
is not possible. Also, the symbol and footprint library has already been
converted to KiCAD 8.0 version. So, I will have to re-import all the
symbols and footprints again. This will be a bit tedious. I think I will
have to redraw the schematic and PCB again.

After redrawing the circuit from the sensor subsystem, I fixed any
errors.

Next, I helped Jalen with the relay. He said that we needed an
optocoupler. This is used to prevent noise. I did some research and
decided "why not". It was a bit difficult finding parts for the
optocoupler, as we were not sure what to look for. Furthermore, most of
the parts on Digikey that we clicked on did not have EDA files. I ended
up going to SnapEDA and searching for optocoupler and clicking the first
item. The first was the VOM617AT. The specs looked ok, and it had a
stock of over 6000 on Digikey, so it must be decent. I suggested it to
Jalen. He thinks we should try it out.

A diagram of a circuit Description automatically generated{width="5.152777777777778in"
height="2.75in"}

After more discussion, it seems like Jalen's initial understanding of
what the relay does was flawed. He thought that the relay also provided
power for the ESP32. However, it is the ESP32 that powers the relay. The
120V on the end of the relay does not go to the low power side.

We will be using a premade transformer to power the ESP32. We decided
that it was not worth the time and trouble to make one. We will be using
the EPS-15-12 120V AC to 12V DC transformer. I will also connect the DC
end to a barrel jack for the PCB.

A table with numbers and symbols Description automatically generated{width="6.5in"
height="2.2006944444444443in"}

Order some more parts from Digikey for the humidifier PCB. Total was
around \$67.00.

A computer screen shot of a circuit board Description automatically generated{width="6.5in"
height="4.634722222222222in"}

**Tuesday, March 19, 2024**

**Objective: Work on humidifier PCB, turn in PCB, meet Surya, discuss
water valve**

Today, when talking to Jalen about the water valve, we discovered that
our water valve might not work for the demonstration. The problem is
that the water valve requires a minimum pressure for it to activate. It
does not work by gravitational water pressure. We will have to find a
different valve that has no pressure rating.

We found a new valve on Amazon that require little to no pressure to
work. The downside is that this controller uses quick connect. Also, we
don't know how much pressure will be during the demo.

This new valve requires 12V DC to power. Originally, we were going to
use some kind of motor controller to control it. However, it occurred to
me that the relay could use 12V DC. This will be perfect for the ESP32
sending 3.3V activation signal, activating the switch, and sending 12V
to the motor.

The only uncertain thing is how does the valve close. Looking at the
description, it seems like the valve will close on its own. We will try
it out later.

When meeting with Surya today, we told him about our progress. He told
us that we should start talking to the machine shop. I told him that I
will do it this week. He says that the machine shop should be working on
our parts now. However, he is still happy that we are making good
progress compared to the other teams.

I told Jalen to help create a spreadsheet of the parts that we have
ordered and the parts that we need to still order. The spreadsheet
should have a total of parts needed for each PCB. Also, the list should
have vendor links of where the parts are from.

A screenshot of a spreadsheet Description automatically generated{width="6.416666666666667in"
height="4.375in"}

I updated the block diagram once more. This time, the block diagram has
electrical relays instead of the motor controller. This is because I
think the design will be more modular. When changing this, I also
updated the GPIO lines. The idea behind the relays is when the switch is
activated, the circuit for the water valve and the humidifier will be
complete. As a result, they turn on.

A screenshot of a computer Description automatically generated{width="6.5in"
height="5.469444444444444in"}

**Thursday, March 21, 2024**

**Objective: Talk to machine shop**

Today, I brought the humidifier and PCB parts to the machine shop. I
also drew some diagrams to show the machine shop what needs to be done.

A white paper with blue writing on it Description automatically generated{width="6.5in"
height="4.875in"}

A white paper with blue writing on it Description automatically generated{width="6.5in"
height="4.875in"}

I think that Gregg understands the idea. However, because we are still
waiting for parts, he cannot begin working on it yet. Gregg requested
that I give him a sample of our PCB and the water valve. He says he will
be on vacation for a week starting the coming Monday. I told him I will
get it to him tomorrow, as the valve is arriving tomorrow.

Jalen and I continued to work on the parts list. Below is the updated
list. It consists of parts for the sensor and the humidifier subsystem:

A screenshot of a computer Description automatically generated{width="6.5in"
height="2.515972222222222in"}

A screenshot of a computer Description automatically generated{width="6.5in"
height="3.154861111111111in"}

**Friday, March 22, 2024**

**Objective: Parts did not arrive**

The valve did not arrive today yet. I think some motherfucker stole my
package. I went to see Gregg to report the bad news, and apparently, he
had already left for his vacation!?

**Sunday, March 24, 2024**

**Objective: Woojin got ESP32s to send data**

Today, Woojin announced that he got the communication between two ESP32s
to work. The original plan was to control the LED of one ESP32 from
another ESP32 over 2.4GHz Wi-Fi. However, Woojin went above and beyond
by being able to send the SHT45's data to another ESP32 and being able
to read it.

**Monday, March 25, 2024**

**Objective: Order parts from funding**

Order parts for humidifier subsystem. I think that this will be the last
order from the \$150.00 budget that we have. This order is mainly UART
chips and plugs for the transformer that we missed.

**Tuesday, March 26, 2024**

**Objective: Meet Surya, test water valve**

Today, the water valve arrived. I tried to test it. However, initially,
I was confused on how it works. I can hear it clicking, but looking in
the hole, I did not see the valve opening. As a result, I took it apart
and found the below:

A small white and blue device Description automatically generated{width="5.536082677165354in"
height="7.381443569553806in"}

As seen in the picture, this is not really a valve, but a plunger. It
works with a coil. When there is a current through the coil, a magnetic
field will be created and the valve will be sucked upwards, thus opening
the valve. The valve is normally closed when there is no current going
to it. The manufacture's specification says that it draws around 4.8W.
This means that there is 0.4 amps flowing through it.

$$4.8W = I*12V$$

$$I = 0.2A$$

This should be enough for our applications. The only worry is that the
seal might not be great. However, since our real valve will not be like
this, as this is an "unpressured valve", it will not be a real problem.

We met with Surya; I told him to good news about Woojin getting the
sensors to send data over Wi-Fi. Surya tells us to contact the machine
shop to see how progress is. Surprisingly, we still have around \$30 of
budget left. We may use it to order our second water level sensor.

**Wednesday, March 27, 2024**

**Objective: Order parts for humidifier, determine power input for
humidifier subsystem**

Today I had to order some parts for the humidifier subsystem. I had to
figure out a way to power the PCB, and I thought that the best way would
be to use a switching regulator. I thought about making our own power
supply, however, with the limited cost and time, I think it would be too
difficult. Also, it is highly unlikely that we can build one for cheaper
than buying one at around \$6.00. Furthermore, the pre-built ones have
surge protection built in, and this is important for voltage spikes. We
will not be sure if our own design can protect against this, and it is
too risky frying all the other components.

We only need a 12V input in our humidifier subsystem. As a result, over
multiple hours of research, I decided on the ESP-15-12 AC/DC converter.
This can provide a 12V DC output with a 1.25A current output. I estimate
that this should be enough for the PCB and the water valve. Looking at
the diagram below, I will also need to buy some plugs for the input and
output.

A diagram of a circuit board Description automatically generated{width="6.5in"
height="4.848611111111111in"}

I was able to find some suggested ones on Digikey with a crimp
connection. I hope that this will work.

Aside from that, I also must think about a way to send the 120V AC into
the subsystem, and a way to power the humidifier. I did not want to make
any difficult changes to the humidifier's fan. As a result, I came up
with the idea below:

There would be a box. There will be an input power into the box through
a wire. This wire can be unplugged anytime. This leads to the
portability of the box. There will be a the 12V AC/DC converter in the
box. This converter will go feed the PCB and other components.

Along with the AC/DC converter, I bought a couple varying parts for the
idea above. This was in Digikey order: 860944423.

Aside from that, I also ordered a relay development board from Digikey.
This was part number 1528-1738-ND. I wanted Woojin to start working on
developing the GPIO functionality as soon as possible.

Finally, we paid for 2 day shipping on the order, so that it can get
here by the weekend.

We also used our remaining budget by ordering another Optomax Digital
Liquid Level Sensor. This will use up all our remaining budget.

**Friday, March 29, 2024**

**Objective: Solder relay dev-board**

Today, the parts and the relay arrived. I could not really do anything
with the parts, as the machine shop still needs to work on the project.
We will need to talk to them soon. The development board for the PCB
seems pretty compact, so our PCB will also be compact.

A small black electronic device on a silver surface Description automatically generated{width="5.273611111111111in"
height="7.031481846019248in"}

**\
**

**Saturday, March 30, 2024**

**Objective: Solder PCB for sensor subsystem**

Today, Jalen and I started soldering the humidity sensor PCB. However,
we discovered that we were still missing some SMD components from the
ECE Electronics Supply Shop. I immediately sent an email to Surya so
that we can get some. However, since we were already at ECEB, Jalen and
I laid the paste and soldered with the parts we have on hand. We took a
while, as I was teaching Jalen how to lay the parts on the PCB. But we
were finished.

The ESP32 was a little bit hard to solder. The ground pads were hard to
heat up. Maybe the iron was not powerful enough. We will finish
soldering in another day when the parts arrive.

A person looking through a microscope Description automatically generated{width="4.714285870516186in"
height="6.285714129483814in"}

**Monday, April 1, 2024**

Jalen and I update the parts list one more time. This time, we color
coded where parts are from and did final adjustments to the quantity.

A screenshot of a computer Description automatically generated{width="6.5in"
height="1.85625in"}

A screenshot of a computer Description automatically generated{width="6.5in"
height="2.5375in"}

**Tuesday, April 2, 2024**

**Objective: Meet Surya, show Surya our PCB, address issues with PCB**

Meeting with Surya today, we told him that we will be working on our PCB
ASAP since parts are here. Surya also asked us to check in with the
machine shop, and we told him that the machine shop is working on our
parts, but there is delay. However, the machine shop did tell us to not
worry.

Tonight, Jalen and I worked on soldering the rest of the first sensor
subsystem PCB. It turned out to be a bad idea to not do all the
soldering at once, as we had to remove all the old solder off the pads
before laying new paste.

After fixing some bridging in certain parts of the chip, we were able to
plug the PCB into our 12V wall power supply. This 12V was from my
previous class in Fall 2023. We were able to program a basic program to
the ESP32.

However, when I tried to program a sample Wi-Fi access point code to the
ESP32, the ESP32 initially worked then started crashing. The symptom is
that, on the serial monitor, it would show that it was connecting and
disconnecting. Also, the voltage regulator and the surrounding
capacitors got really hot. In fact, it got so hot that it was
uncomfortable to the touch. Ultimately, the voltage regulator fried
itself and stopped outputting 3.3V. Thankfully, it output 1.5V, so it
did not fry the ESP32.

We think that the regulator might be defective, so we changed it for
another one. Though the new one did not fry itself, it still had the
issue where the ESP32 would keep connecting and disconnecting.
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

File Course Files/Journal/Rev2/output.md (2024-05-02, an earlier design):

**Tuesday, February 06, 2024**

A notebook with writing on it Description automatically generated{width="6.361111111111111in"
height="8.481481846019248in"}

**Wednesday, February 07, 2024**

Today, we talked to the machine shop. Prior to going, I made a
PowerPoint describing what we wanted to do. In the PowerPoint, I
included some images, such as a visual aid, and images of parts that we
may use.

In the machine shop, Gregg told us that they will not build a new
humidifier for us. However, they will be happy to modify one from
Amazon. He suggests that we get one that is simple, with a manual on-off
function. Also, it is preferred that it is square, so that it will be
easier to mount things without leaks.
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

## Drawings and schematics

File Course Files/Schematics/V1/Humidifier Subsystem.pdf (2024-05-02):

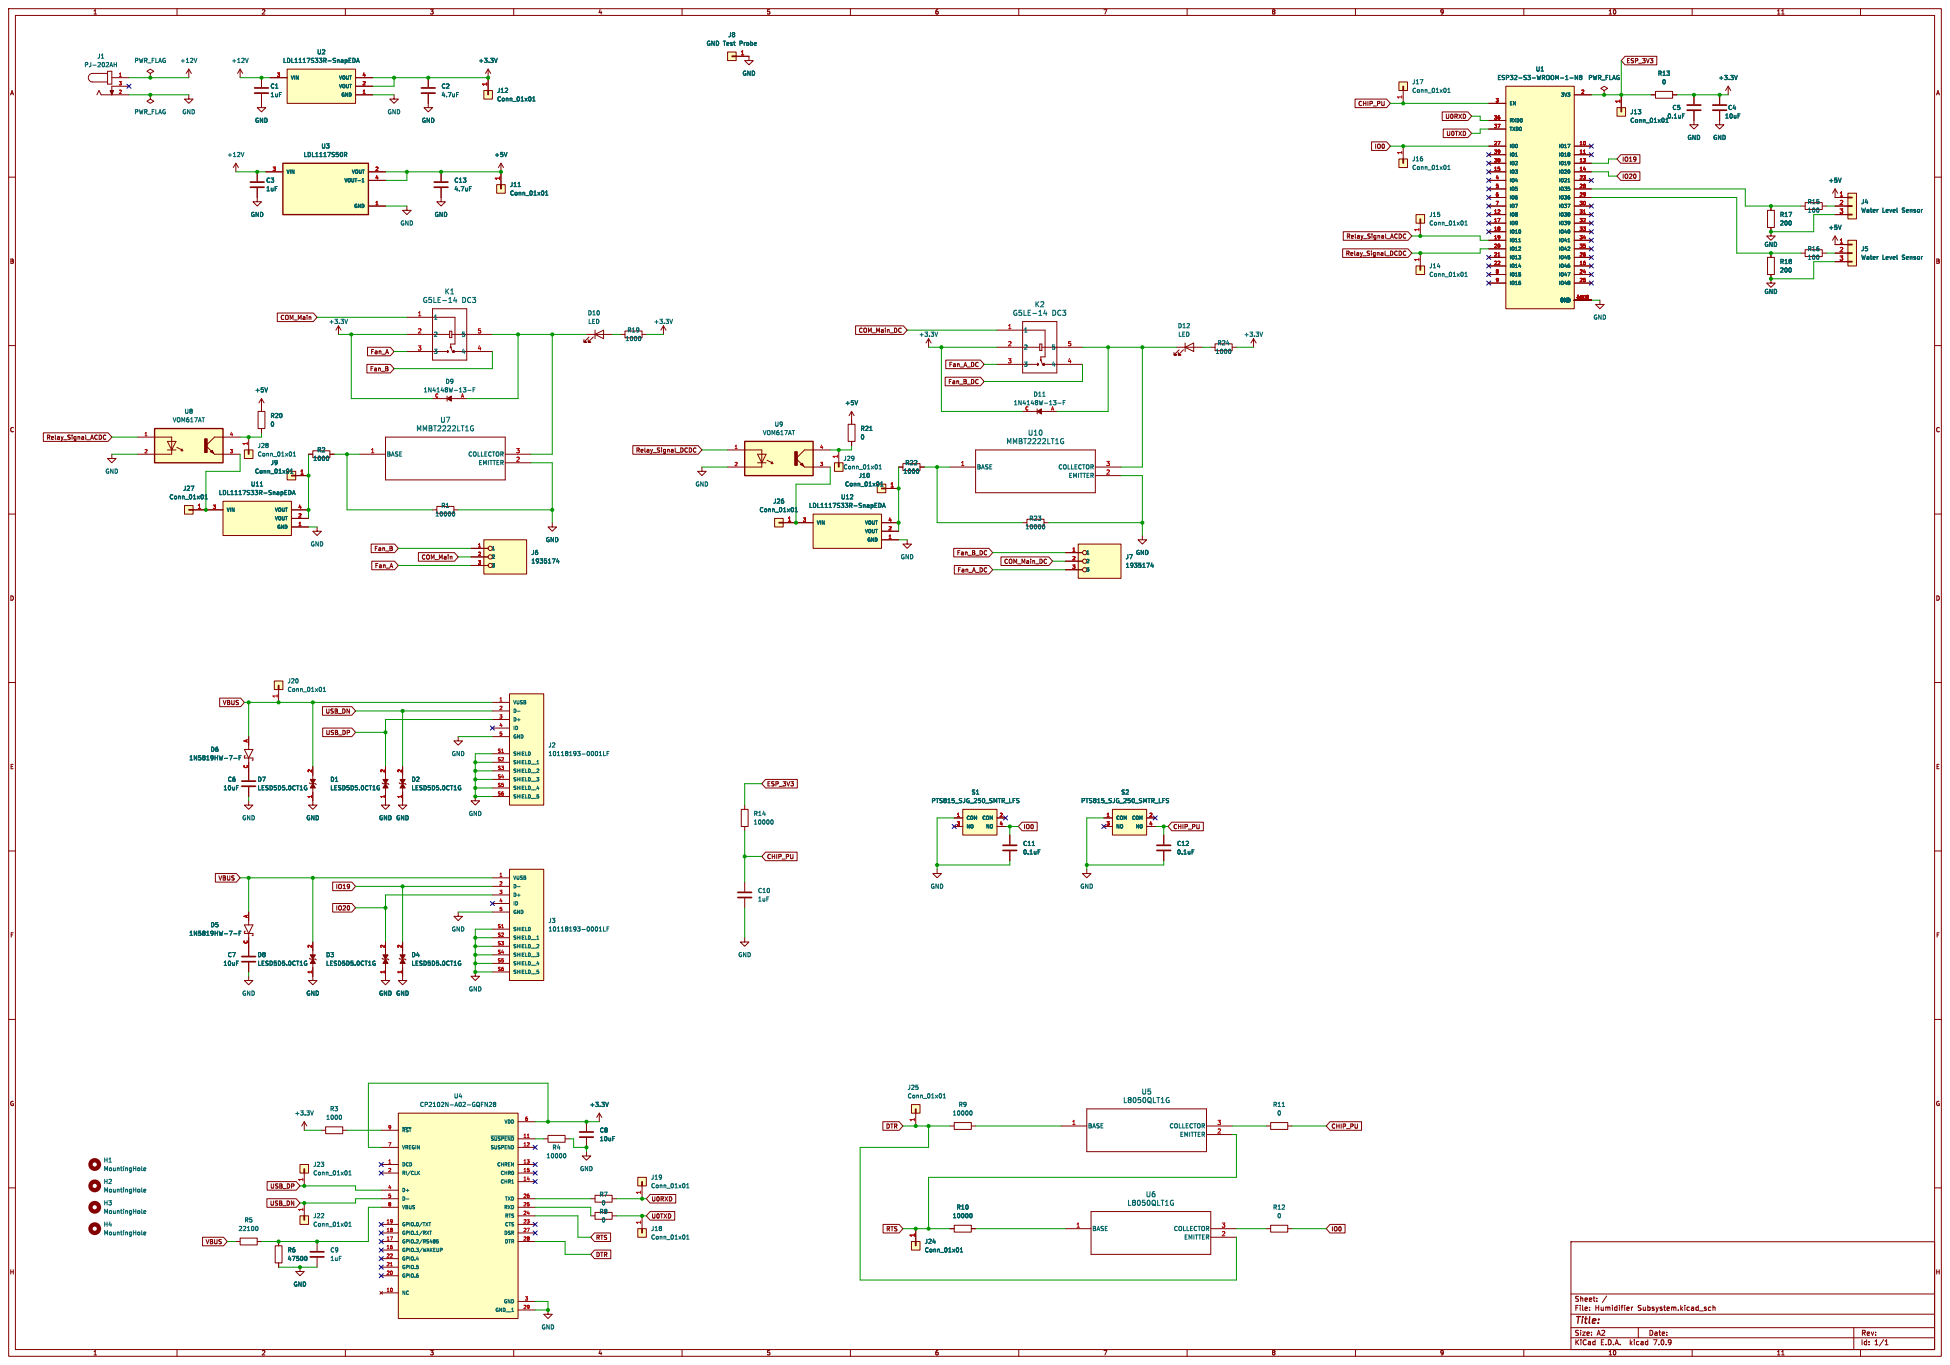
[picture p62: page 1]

J8 GND Test Probe GND

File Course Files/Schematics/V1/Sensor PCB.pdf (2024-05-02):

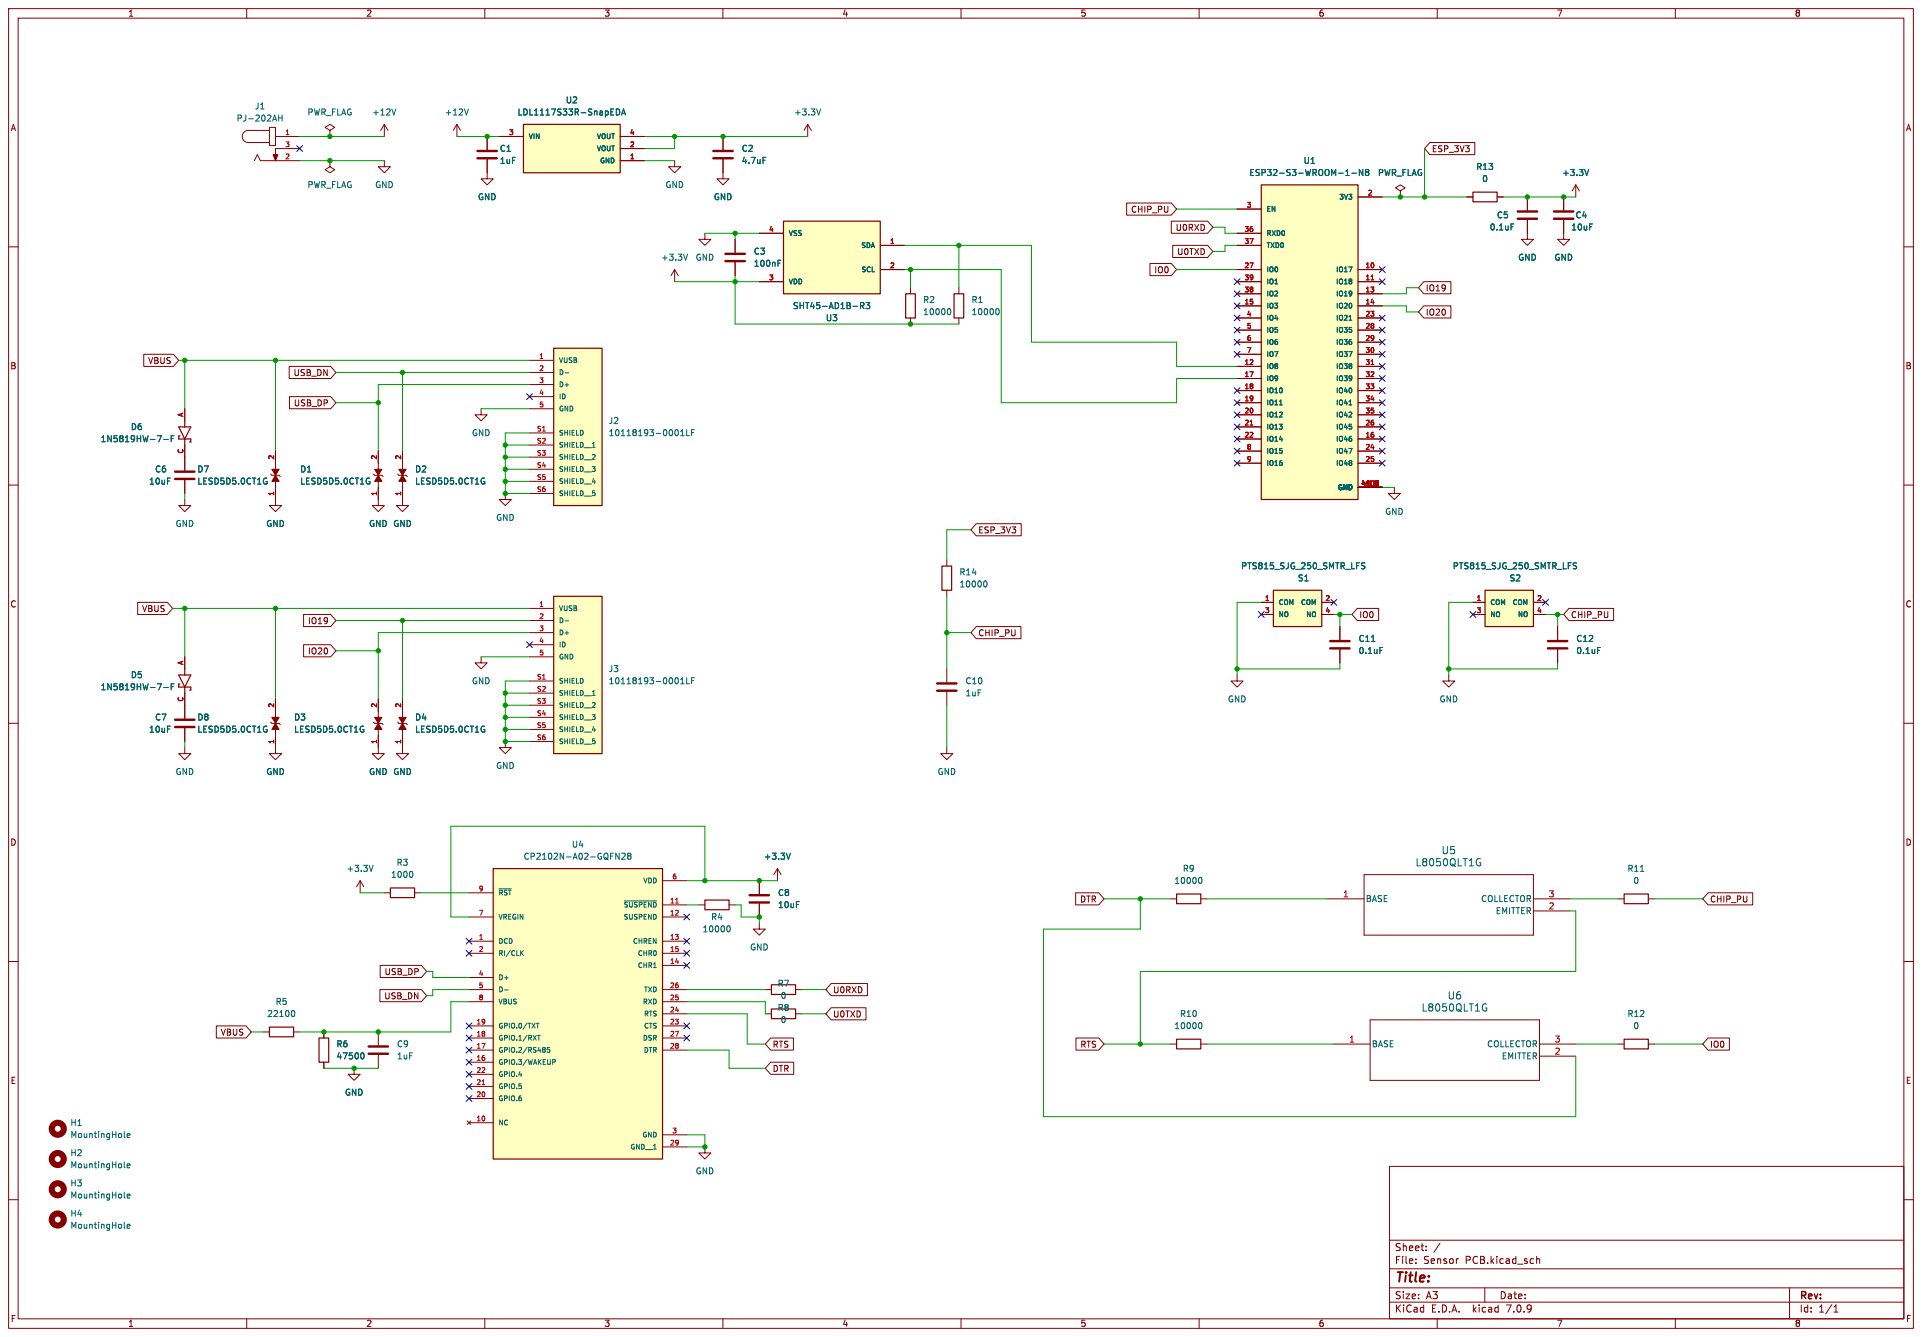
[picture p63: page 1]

10uF H1 MountingHole H2 MountingHole H3 MountingHole H4 MountingHole

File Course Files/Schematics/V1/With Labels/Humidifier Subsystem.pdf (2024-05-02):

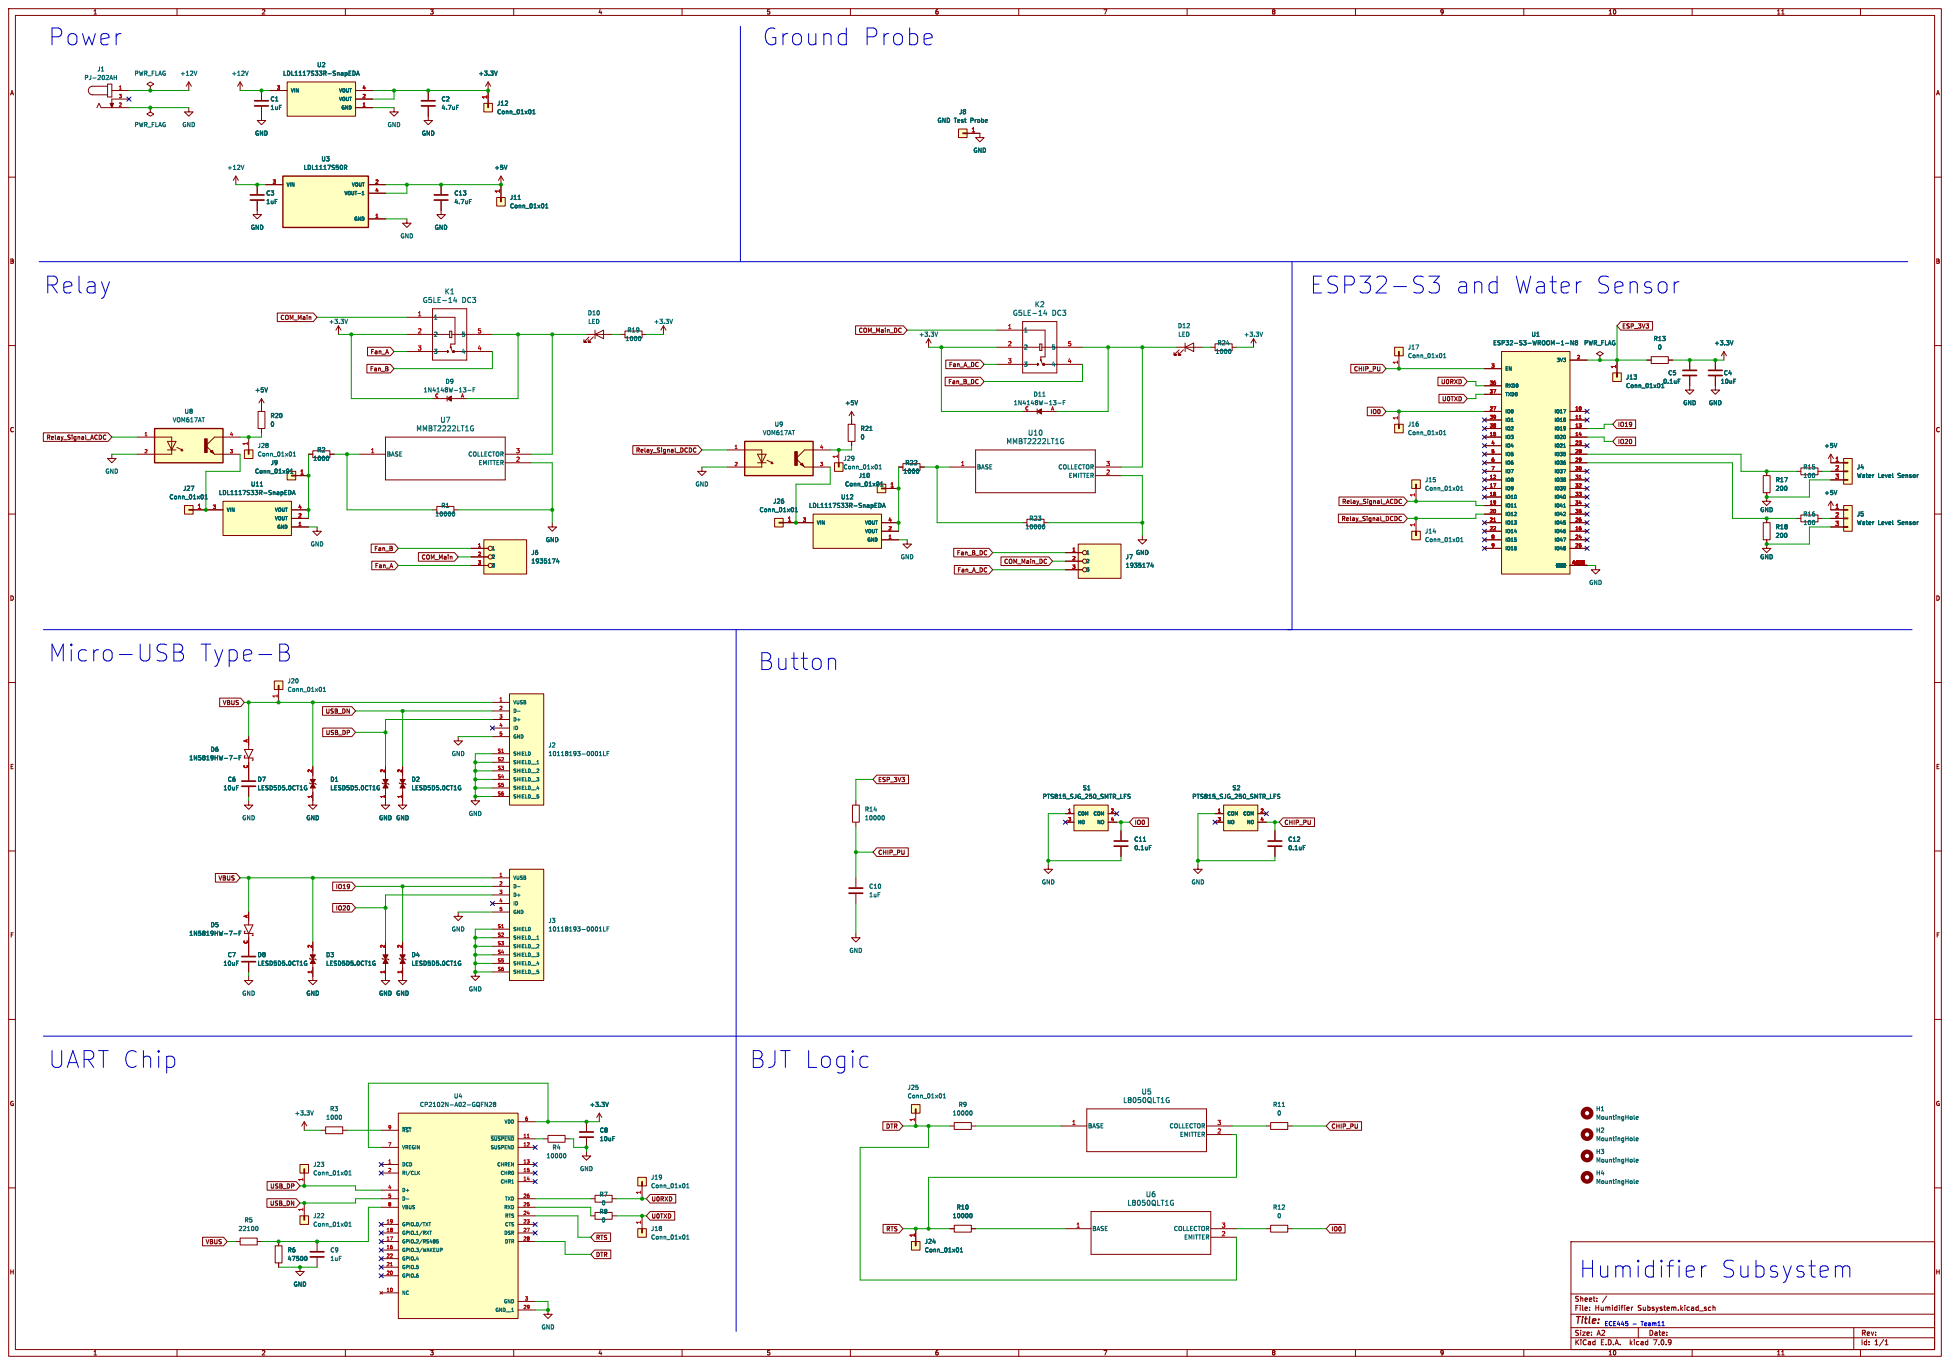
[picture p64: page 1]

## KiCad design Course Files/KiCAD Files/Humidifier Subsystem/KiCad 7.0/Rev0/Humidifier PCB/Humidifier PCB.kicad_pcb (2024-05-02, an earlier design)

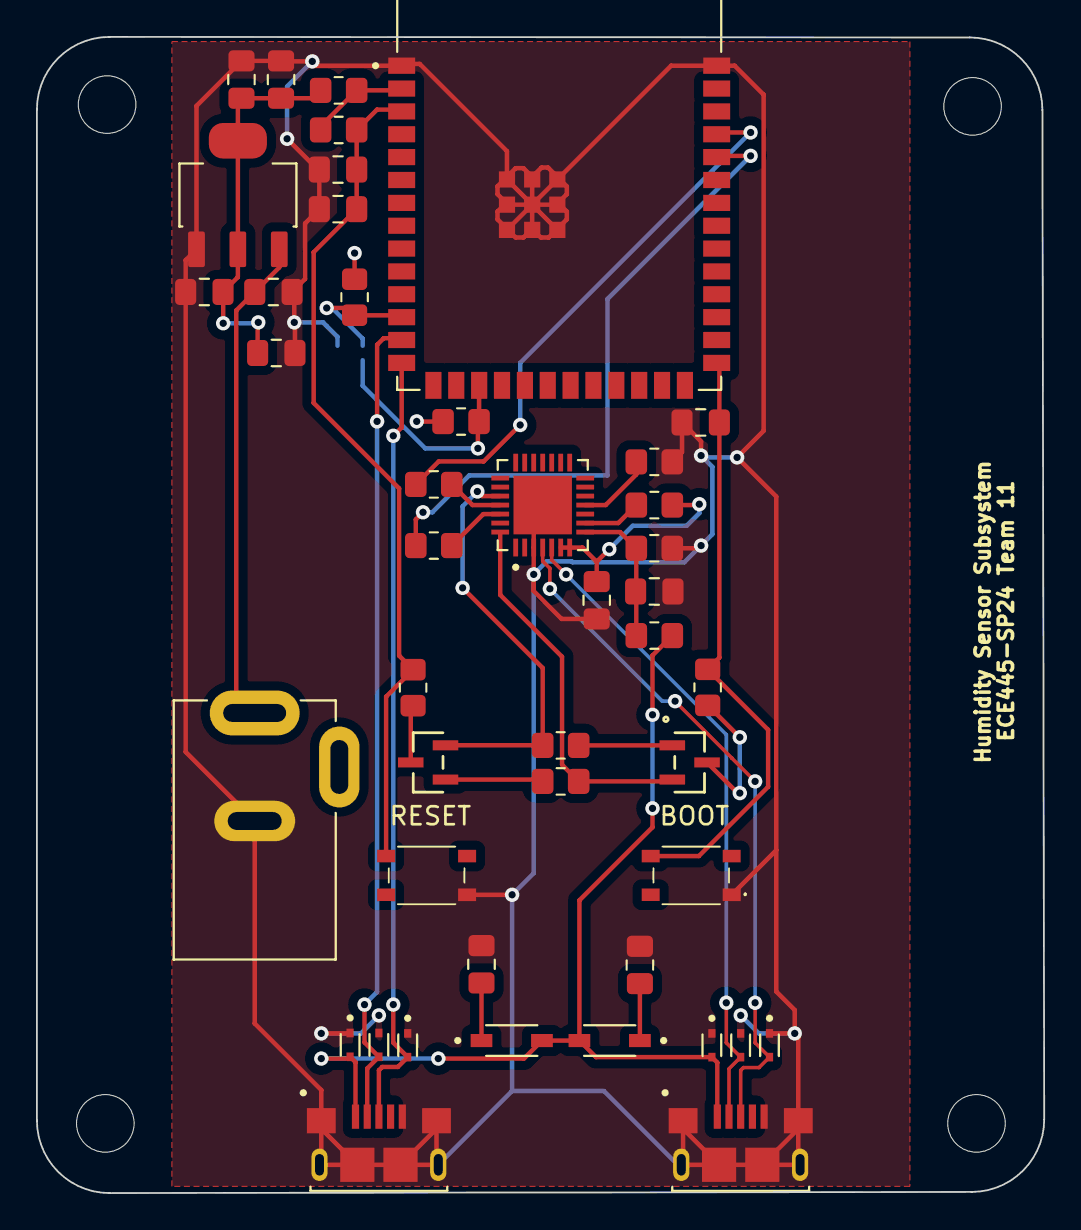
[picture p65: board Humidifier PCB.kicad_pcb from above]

Board: 2 copper layers, 56.0 x 64.2 mm, 49 parts (1 on the bottom side), 19 nets.

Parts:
C1, C9, C10: 1uF; C_0805_2012Metric_Pad1.18x1.45mm_HandSolder
C2: 4.7uF; C_0805_2012Metric_Pad1.18x1.45mm_HandSolder
C3: 100nF; C_0805_2012Metric_Pad1.18x1.45mm_HandSolder
C4, C6, C7, C8: 10uF; C_0805_2012Metric_Pad1.18x1.45mm_HandSolder
C5, C11, C12: 0.1uF; C_0805_2012Metric_Pad1.18x1.45mm_HandSolder
D1, D2, D3, D4, D7, D8: LESD5D5.0CT1G; LESD5D5_0CT1G
D5, D6: 1N5819HW-7-F
H1, H2, H3, H4: MountingHole; MountingHole_3.2mm_M3
J1: PJ-202AH
J2, J3: 10118193-0001LF
R1, R2, R4, R9, R10, R14: 10000; R_0805_2012Metric_Pad1.20x1.40mm_HandSolder
R3: 1000; R_0805_2012Metric_Pad1.20x1.40mm_HandSolder
R5: 22100; R_0805_2012Metric_Pad1.20x1.40mm_HandSolder
R6: 47500; R_0805_2012Metric_Pad1.20x1.40mm_HandSolder
R7, R8, R11, R12, R13: 0; R_0805_2012Metric_Pad1.20x1.40mm_HandSolder
S1, S2: PTS815_SJG_250_SMTR_LFS; PTS815 SJG 250 SMTR LFS
U1: ESP32-S3-WROOM-1-N8; ESP32-S3-WROOM-1-N8-SnapEDA
U2: LDL1117S33R-SnapEDA
U3: SHT45-AD1B-R3
U4: CP2102N-A02-GQFN28
U5, U6: L8050QLT1G; SOT-23_ONS

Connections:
+3.3V: C2.1, C3.2, C4.1, C5.1, C8.1, R1.2, R2.2, R3.1, R13.2, U2.2 (VOUT), U2.4 (VOUT), U3.3 (VDD), U4.6 (VDD), U4.7 (VREGIN)
+12V: C1.1, J1.1, U2.3 (VIN)
CHIP_PU: C10.1, C12.1, R11.2, R14.2, S2.4 (NO), U1.3 (EN)
DTR: R9.1, U4.28 (DTR), U6.2 (EMITTER)
ESP_3V3: R13.1, R14.1, U1.2 (3V3)
GND: C1.2, C2.2, C3.1, C4.2, C5.2, C6.2, C7.2, C8.2, C9.2, C10.2, C11.2, C12.2, D1.1, D2.1, D3.1, D4.1, D7.1, D8.1, J1.2, J2.5 (GND), J2.S1 (SHIELD), J2.S2 (SHIELD__1), J2.S3 (SHIELD__2), J2.S4 (SHIELD__3), J2.S5 (SHIELD__4), J2.S6 (SHIELD__5), J3.5 (GND), J3.S1 (SHIELD), J3.S2 (SHIELD__1), J3.S3 (SHIELD__2), J3.S4 (SHIELD__3), J3.S5 (SHIELD__4), J3.S6 (SHIELD__5), R4.1, R6.1, S1.1 (COM), S2.1 (COM), U1.1 (GND), U1.40 (GND), U1.41_1 (GND), U1.41_2 (GND), U1.41_3 (GND), U1.41_4 (GND), U1.41_5 (GND), U1.41_6 (GND), U1.41_7 (GND), U1.41_8 (GND), U1.41_9 (GND), U2.1 (GND), U3.4 (VSS), U4.3 (GND), U4.29 (GND__1)
IO0: C11.1, R12.2, S1.4 (NO), U1.27 (IO0)
IO19: D4.2, J3.2 (D-), U1.13 (IO19)
IO20: D3.2, J3.3 (D+), U1.14 (IO20)
unnamed: R9.2, U5.1 (BASE)
unnamed: R11.1, U5.3 (COLLECTOR)
unnamed: R10.2, U6.1 (BASE)
unnamed: R12.1, U6.3 (COLLECTOR)
RTS: R10.1, U4.24 (RTS), U5.2 (EMITTER)
U0RXD: R7.2, U1.36 (RXD0)
U0TXD: R8.2, U1.37 (TXD0)
USB_DN: D2.2, J2.2 (D-), U4.5 (D-)
USB_DP: D1.2, J2.3 (D+), U4.4 (D+)
VBUS: D5.A, D6.A, D7.2, D8.2, J2.1 (VUSB), J3.1 (VUSB), R5.1

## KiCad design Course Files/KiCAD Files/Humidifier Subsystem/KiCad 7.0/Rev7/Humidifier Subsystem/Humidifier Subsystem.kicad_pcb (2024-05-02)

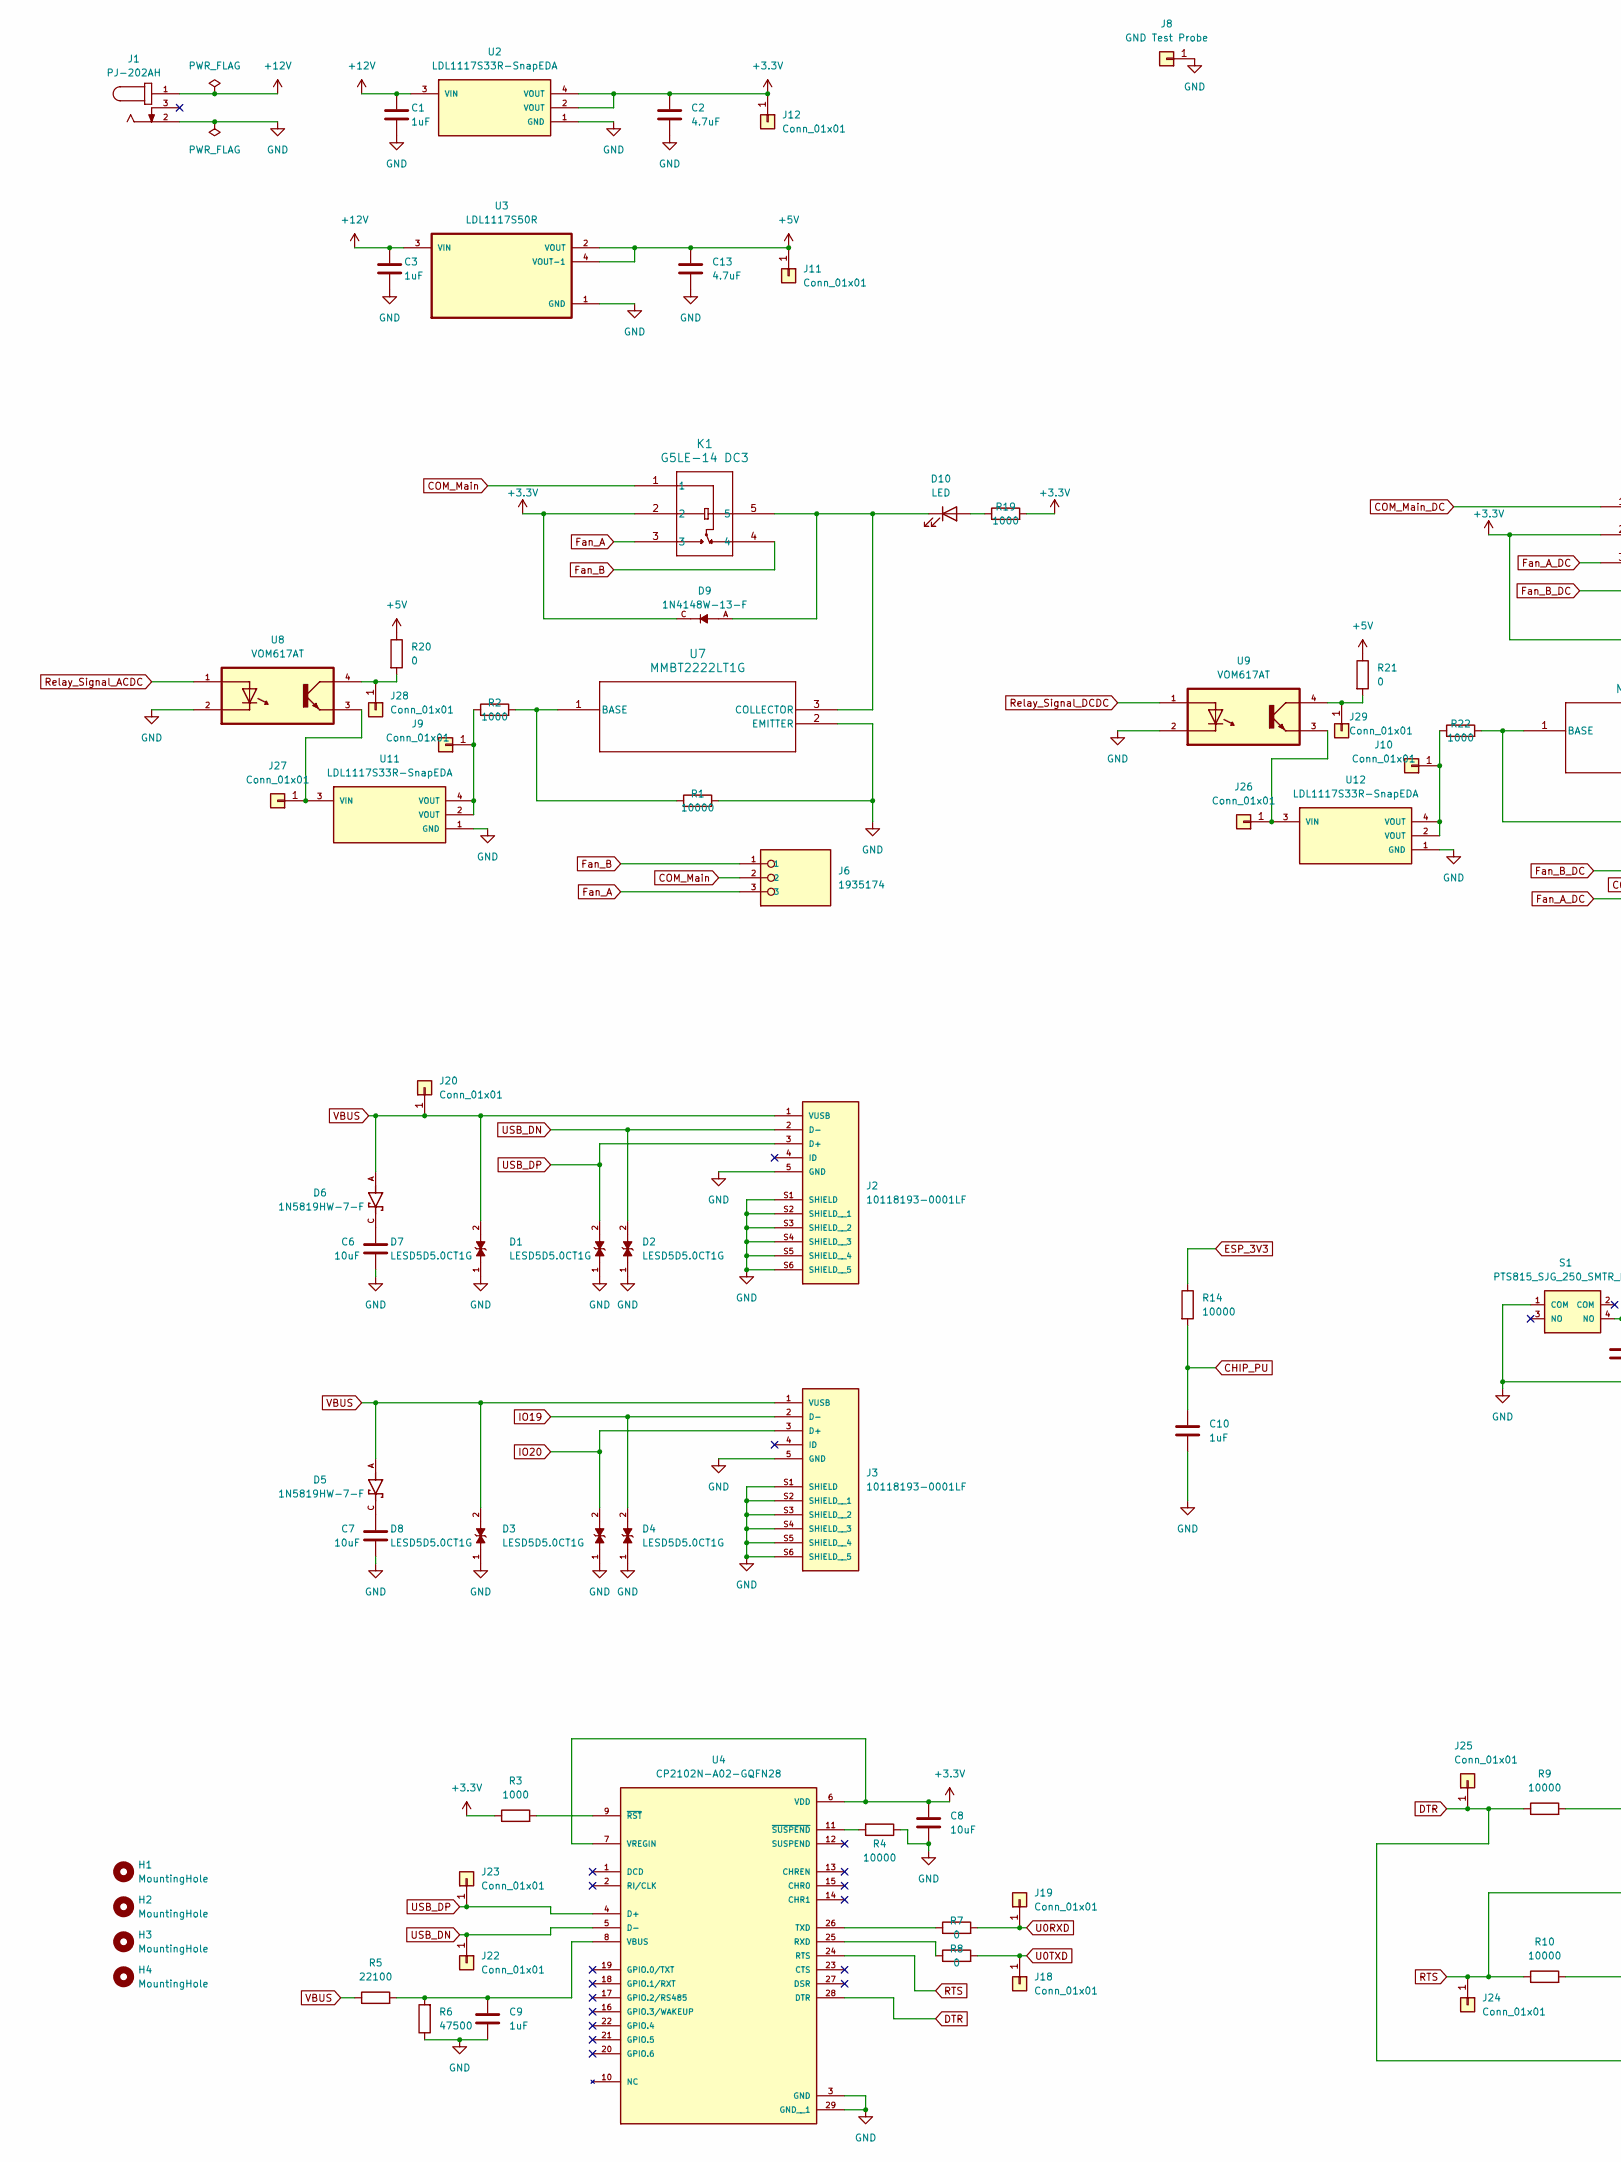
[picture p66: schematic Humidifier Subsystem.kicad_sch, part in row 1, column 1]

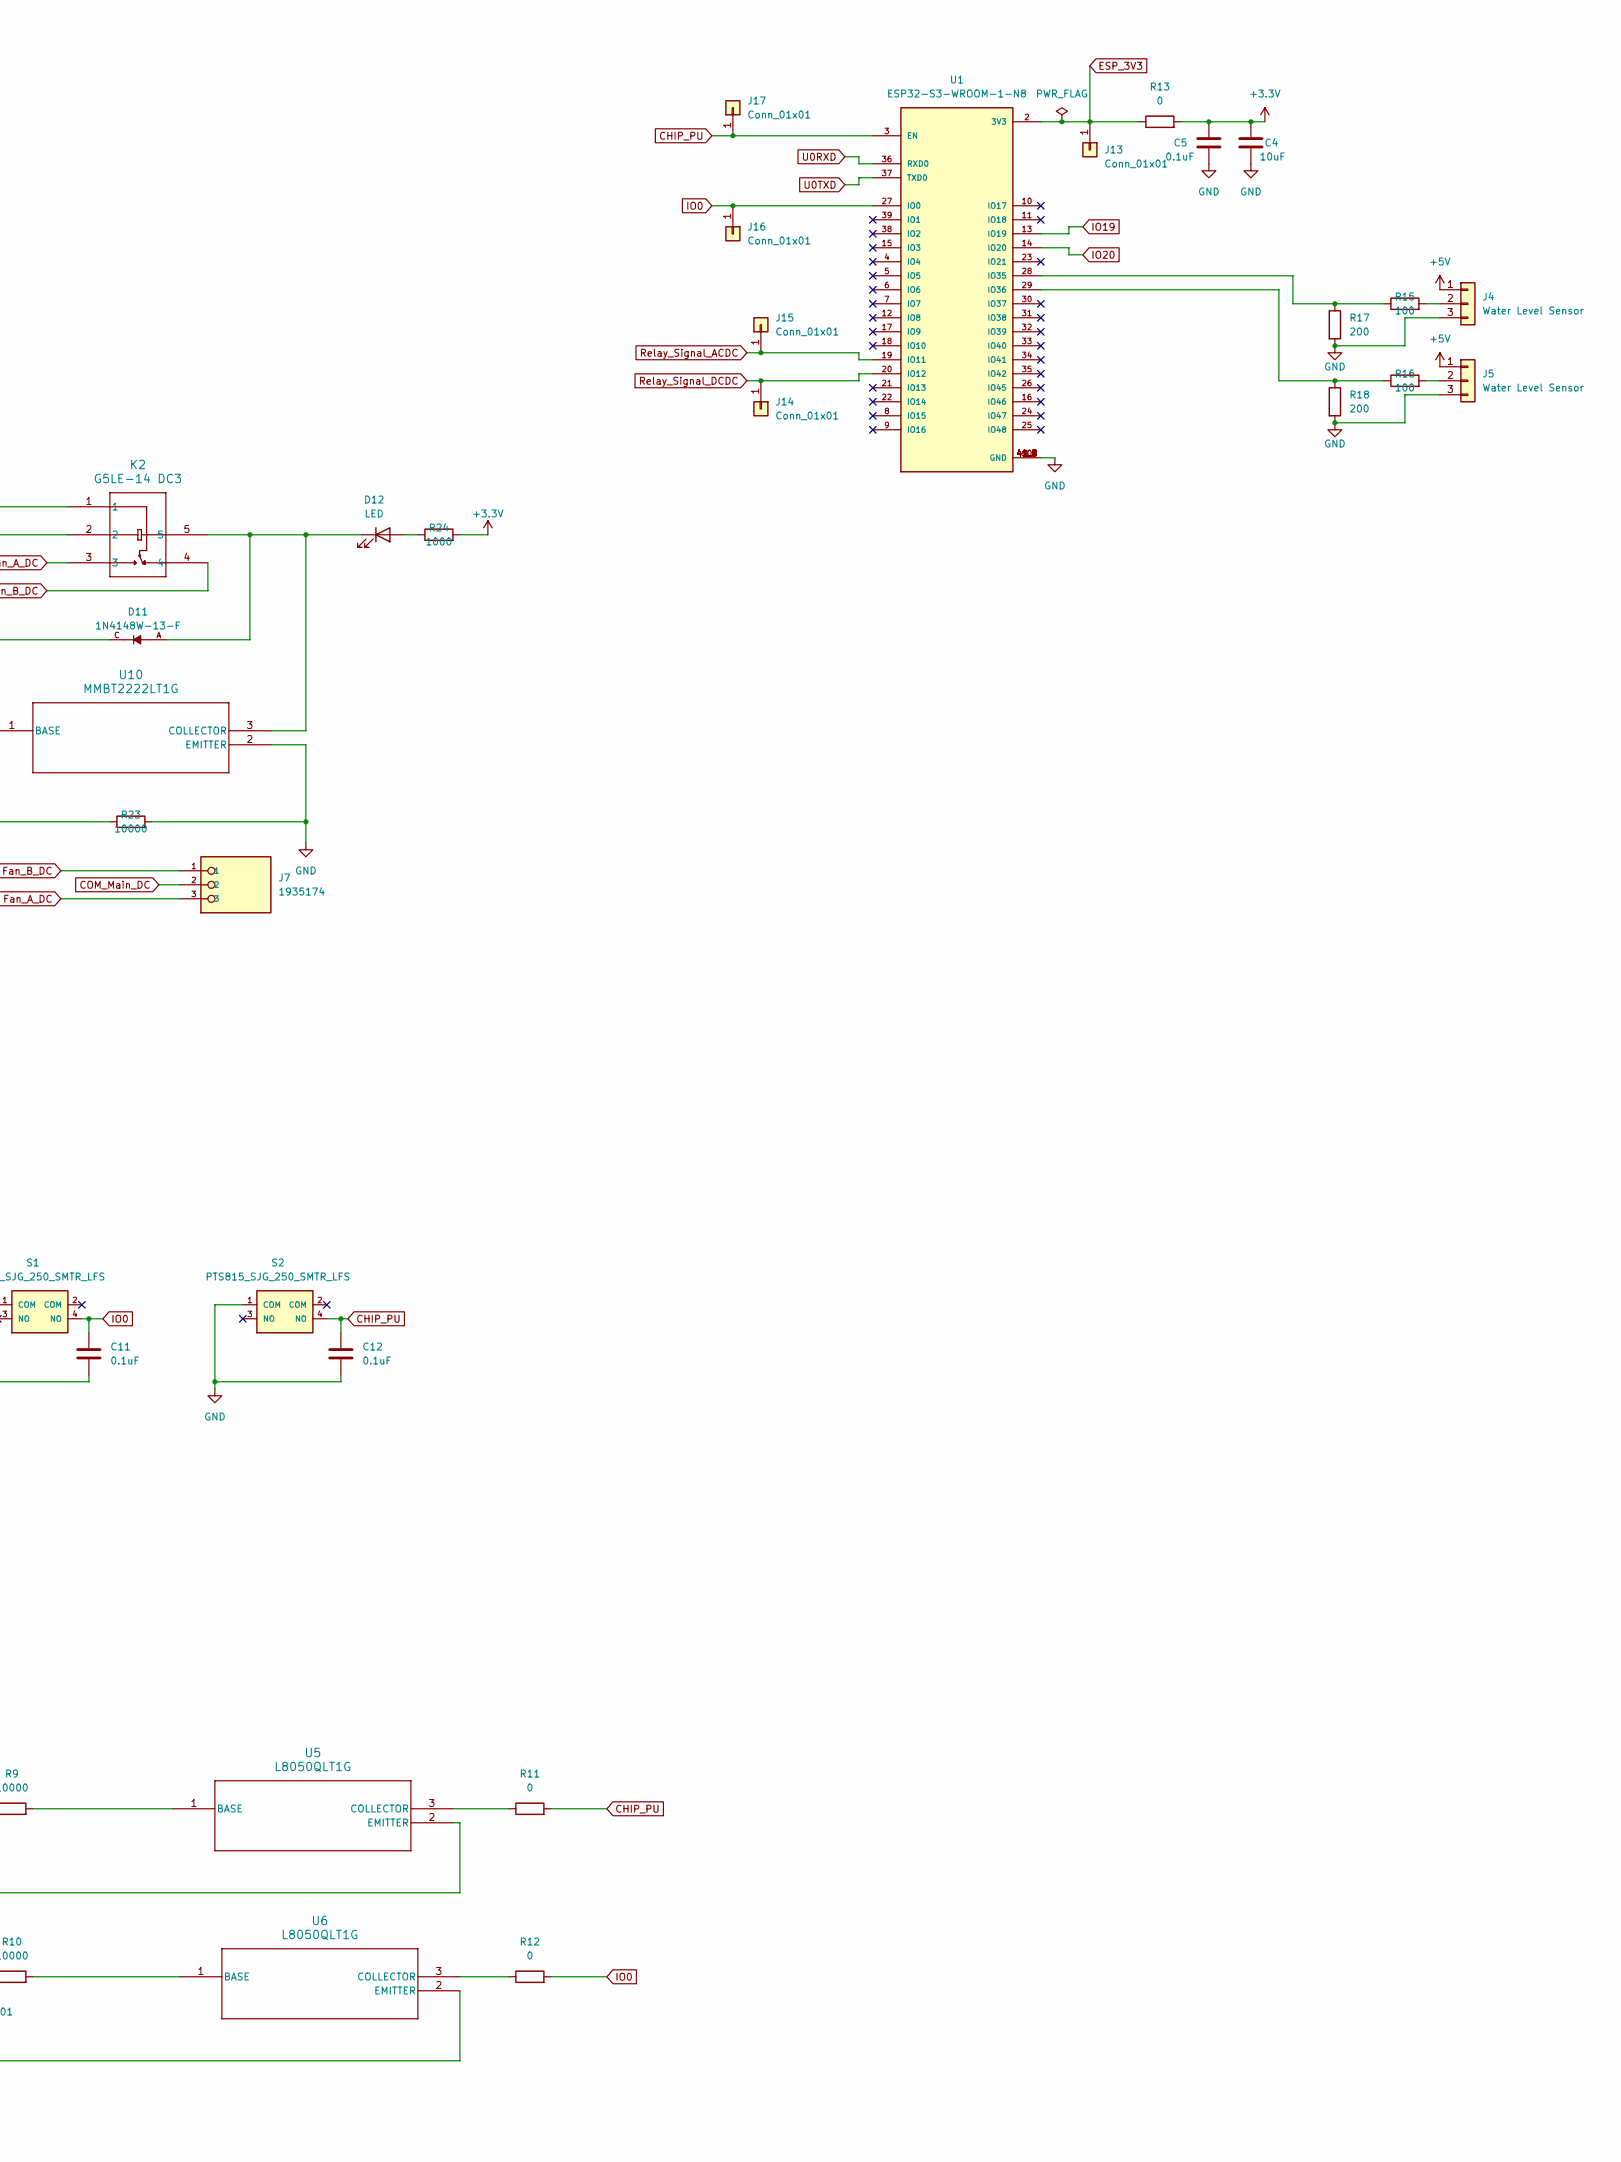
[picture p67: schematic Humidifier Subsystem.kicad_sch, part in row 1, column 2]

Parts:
C1, C3, C9, C10: 1uF; C_0805_2012Metric_Pad1.18x1.45mm_HandSolder
C2, C13: 4.7uF; C_0805_2012Metric_Pad1.18x1.45mm_HandSolder
C4, C6, C7, C8: 10uF; C_0805_2012Metric_Pad1.18x1.45mm_HandSolder
C5, C11, C12: 0.1uF; C_0805_2012Metric_Pad1.18x1.45mm_HandSolder
D1, D2, D3, D4, D7, D8: LESD5D5.0CT1G; LESD5D5_0CT1G; PARTREV O
D5, D6: 1N5819HW-7-F; PARTREV 18-2
D9, D11: 1N4148W-13-F; PARTREV 28-2
D10, D12: LED; D_0805_2012Metric_Pad1.15x1.40mm_HandSolder
H1, H2, H3, H4: MountingHole; MountingHole_3.2mm_M3
J1: PJ-202AH; PART_REV 1.02
J2, J3: 10118193-0001LF; PARTREV E
J4, J5: Water Level Sensor; 1935174
J6, J7: 1935174
J8: GND Test Probe; PinSocket_1x01_P2.54mm_Vertical
J9, J10, J11, J12, J13, J14, J15, J16, J17, J18, J19, J20, J22, J23, J24, J25, J26, J27, J28, J29: Conn_01x01; PinSocket_1x01_P2.54mm_Vertical
K1, K2: G5LE-14 DC3; G5LE-1 DC3
R1, R4, R9, R10, R14, R23: 10000; R_0805_2012Metric_Pad1.20x1.40mm_HandSolder
R2, R3, R19, R22, R24: 1000; R_0805_2012Metric_Pad1.20x1.40mm_HandSolder
R5: 22100; R_0805_2012Metric_Pad1.20x1.40mm_HandSolder
R6: 47500; R_0805_2012Metric_Pad1.20x1.40mm_HandSolder
R7, R8, R11, R12, R13, R20, R21: 0; R_0805_2012Metric_Pad1.20x1.40mm_HandSolder
R15, R16: 100; R_0805_2012Metric_Pad1.20x1.40mm_HandSolder
R17, R18: 200; R_0805_2012Metric_Pad1.20x1.40mm_HandSolder
S1, S2: PTS815_SJG_250_SMTR_LFS; PTS815 SJG 250 SMTR LFS; MOUSER_PART_NUMBER 611-PTS815SJG250SMTR
U1: ESP32-S3-WROOM-1-N8; ESP32-S3-WROOM-1-N8-SnapEDA; DigiKey_Part_Number 1965-ESP32-S3-WROOM-1-N8TR-ND
U2, U11, U12: LDL1117S33R-SnapEDA; PARTREV 7; DigiKey_Part_Number 497-17239-2-ND
U3: LDL1117S50R
U4: CP2102N-A02-GQFN28; PARTREV 1.5
U5, U6: L8050QLT1G; SOT-23_ONS
U7, U10: MMBT2222LT1G
U8, U9: VOM617AT

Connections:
+3.3V: C2.1, C4.1, C5.1, C8.1, D9.C, D11.C, J12.1, K1.2, K2.2, R3.1, R13.2, R19.2, R24.2, U2.2 (VOUT), U2.4 (VOUT), U4.6 (VDD), U4.7 (VREGIN)
+5V: C13.1, J4.1, J5.1, J11.1, R20.1, R21.1, U3.2 (VOUT), U3.4 (VOUT-1)
+12V: C1.1, C3.1, J1.1, U2.3 (VIN), U3.3 (VIN)
CHIP_PU: C10.1, C12.1, J17.1, R11.2, R14.2, S2.4 (NO), U1.3 (EN)
COM_Main: J6.2, K1.1
COM_Main_DC: J7.2, K2.1
DTR: J25.1, R9.1, U4.28 (DTR), U6.2 (EMITTER)
ESP_3V3: J13.1, R13.1, R14.1, U1.2 (3V3)
Fan_A: J6.3, K1.3
Fan_A_DC: J7.3, K2.3
Fan_B: J6.1, K1.4
Fan_B_DC: J7.1, K2.4
GND: C1.2, C2.2, C3.2, C4.2, C5.2, C6.2, C7.2, C8.2, C9.2, C10.2, C11.2, C12.2, C13.2, D1.1, D2.1, D3.1, D4.1, D7.1, D8.1, J1.2, J2.5 (GND), J2.S1 (SHIELD), J2.S2 (SHIELD__1), J2.S3 (SHIELD__2), J2.S4 (SHIELD__3), J2.S5 (SHIELD__4), J2.S6 (SHIELD__5), J3.5 (GND), J3.S1 (SHIELD), J3.S2 (SHIELD__1), J3.S3 (SHIELD__2), J3.S4 (SHIELD__3), J3.S5 (SHIELD__4), J3.S6 (SHIELD__5), J4.3, J5.3, J8.1, R1.2, R4.1, R6.1, R17.2, R18.2, R23.2, S1.1 (COM), S2.1 (COM), U1.1 (GND), U1.40 (GND), U1.41_1 (GND), U1.41_2 (GND), U1.41_3 (GND), U1.41_4 (GND), U1.41_5 (GND), U1.41_6 (GND), U1.41_7 (GND), U1.41_8 (GND), U1.41_9 (GND), U2.1 (GND), U3.1 (GND), U4.3 (GND), U4.29 (GND__1), U7.2 (EMITTER), U8.2, U9.2, U10.2 (EMITTER), U11.1 (GND), U12.1 (GND)
IO0: C11.1, J16.1, R12.2, S1.4 (NO), U1.27 (IO0)
IO19: D4.2, J3.2 (D-), U1.13 (IO19)
IO20: D3.2, J3.3 (D+), U1.14 (IO20)
unnamed: C6.1, D6.C
unnamed: C7.1, D5.C
unnamed: D10.2 (A), R19.1
unnamed: D9.A, D10.1 (K), K1.5, U7.3 (COLLECTOR)
unnamed: D12.2 (A), R24.1
unnamed: D11.A, D12.1 (K), K2.5, U10.3 (COLLECTOR)
unnamed: J4.2, R15.2
unnamed: J5.2, R16.2
unnamed: J9.1, R2.1, U11.2 (VOUT), U11.4 (VOUT)
unnamed: J10.1, R22.1, U12.2 (VOUT), U12.4 (VOUT)
unnamed: J26.1, U9.3, U12.3 (VIN)
unnamed: J27.1, U8.3, U11.3 (VIN)
unnamed: J28.1, R20.2, U8.4
unnamed: J29.1, R21.2, U9.4
unnamed: R15.1, R17.1, U1.28 (IO35)
unnamed: R16.1, R18.1, U1.29 (IO36)
unnamed: R8.1, U4.25 (RXD)
unnamed: R7.1, U4.26 (TXD)
unnamed: C9.1, R5.2, R6.2, U4.8 (VBUS)
unnamed: R3.2, U4.9 (~RST)
unnamed: R4.2, U4.11 (~SUSPEND)
unnamed: R9.2, U5.1 (BASE)
unnamed: R11.1, U5.3 (COLLECTOR)
unnamed: R10.2, U6.1 (BASE)
unnamed: R12.1, U6.3 (COLLECTOR)
unnamed: R1.1, R2.2, U7.1 (BASE)
unnamed: R22.2, R23.1, U10.1 (BASE)
RTS: J24.1, R10.1, U4.24 (RTS), U5.2 (EMITTER)
Relay_Signal_ACDC: J15.1, U1.19 (IO11), U8.1
Relay_Signal_DCDC: J14.1, U1.20 (IO12), U9.1
U0RXD: J19.1, R7.2, U1.36 (RXD0)
U0TXD: J18.1, R8.2, U1.37 (TXD0)
USB_DN: D2.2, J2.2 (D-), J22.1, U4.5 (D-)
USB_DP: D1.2, J2.3 (D+), J23.1, U4.4 (D+)
VBUS: D5.A, D6.A, D7.2, D8.2, J2.1 (VUSB), J3.1 (VUSB), J20.1, R5.1

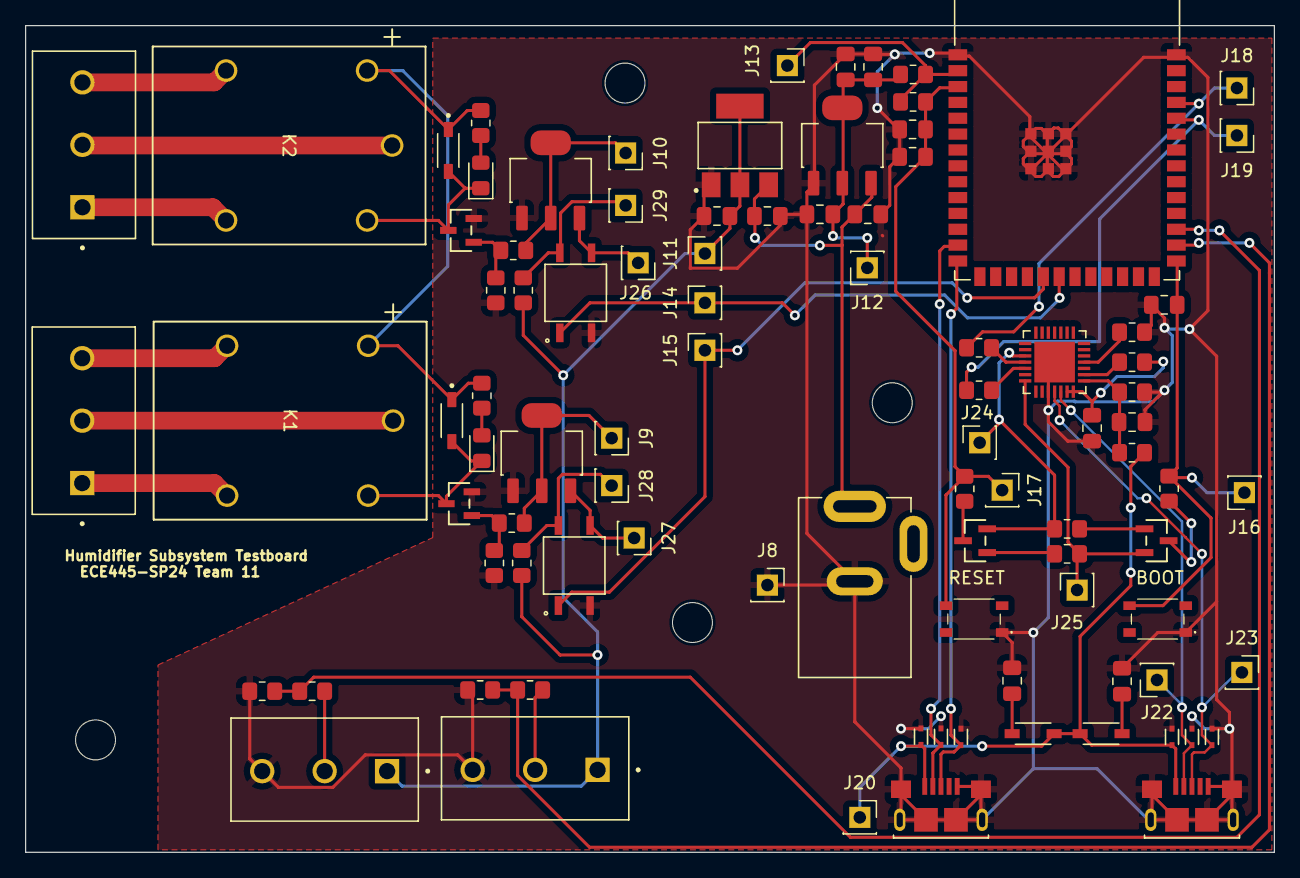
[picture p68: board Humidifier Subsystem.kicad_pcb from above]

Board: 2 copper layers, 100.0 x 66.2 mm, 97 parts (0 on the bottom side), 51 nets.

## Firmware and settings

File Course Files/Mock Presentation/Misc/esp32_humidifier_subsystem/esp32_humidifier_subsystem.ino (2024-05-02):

/*
University of Illinois at Urbana-Champaign, ECE 445 Senior Design Laboratory (Spring 2024)
  Team No. 11, Automatic Humidity Sensing and Water Refilling Cool-Mist Humidifier
    Team Info.: Andrew Sherwin (zyxie2@illinois.edu), Woojin Kim (wkim51@illinois.edu), Jalen Chen (jalenc3@illinois.edu) 
    TA: Surya Vasanth
    Professor: Dr. Jonathon Schuh

Code for programming Humidifier Subsystem's ESP32
  List of functionalities (Provides Auto/Manual control of the Humidifier)
    A1. Auto Mode
      1. Receives Humiditity/Temperature data from Humidity Sensor Subsystem's ESP32 (through 2.4 GHz Wi-Fi)
      2. Set correspoding min-max (ideal range) target humiditity range based on the indoor temperature
        2.1 (strech-out goal) User can define the range between each sensor and the humidifier, based on the distance, reading will be more/less weighted in the calculation of ideal target range
      3. If humidity falls below the min, turn on (or maintain) the Fan operation
      4. If humidity goes beyond the max, turn off the Fan operation

    A2. Manual Mode
      1. Ignore the sensor data, user gets to control operation (On/Off) of the Fan

    Common functionality for Auto/Manual Mode (Water Tank)
      1. Open the water valve, if the water level reaches the bottom water level sensor
      2. Close the water valve, if the water level reaches the top water level sensor

    Common functionality for Auto/Manual Mode (Visualization and Auto/Manual Control)
      1. Visualize current readings of Humidity/Temperature of each (three) sensors on the Web
      2. User can select Auto/Manual mode through the Web
*/

#include <esp_now.h>
#include <WiFi.h>
#include <WiFiClient.h>
#include <WebServer.h>
#include <ESPAsyncWebServer.h>
#include <ESPmDNS.h>

// Variables to hold each sensor's humidity and temperature data
float humidity1;
float temperature1;

float humidity2;
float temperature2;

float humidity3;
float temperature3;

// Variables for GPIO pins
int fanPin = 12;
int valvePin = 11;

int bottomWaterLevelPin = 36;
int topWaterLevelPin = 35;

// HIGH = 1, LOW = 0
int fanState;
int valveState;

// HIGH = 1, LOW = 0
int manualFanState = 0;
int manualValveState = 0;

// Variables to hold average temp/humidity
float avgTemperature;
float avgHumidity;

// Flag for Manual/Auto Mode
int autoMode = 1;

// Flag for fill the water tank until the top sensor once started to fill
int fillToEnd = 1;

// timestamp for take avg. from only 1-2 sensors and for malfunction detection
unsigned long timestamp1 = 0;
unsigned long timestamp2 = 0;
unsigned long timestamp3 = 0;

// sensor On/Off flag for take avg. from only 1-2 sensors and for malfunction detection
int sensor1OnOFF = 0;
int sensor2OnOFF = 0;
int sensor3OnOFF = 0;

float ho1 = 12;

float to1 = 0;
float to2 = 0;
float to3 = 0;

// Web Server Access (ssid and password)
const char *ssid = "SmartHumidifer";
const char *password = "ECE445GROUP11";

// Web server port to 80, listens to the connected device request
AsyncWebServer server(80);

// Structure of message that will be sent (contains sender id, humidity, and temperature data)
typedef struct msg {
  int sensorNumber; // include unique identification of the sender in the message, so that the receiver can identify where the data came from
  float humidity; // include humidity data in the packet
  float temperature; // include temperature data in the packet
} msg;

// Define variable that will be used for the message
msg message;

// Callback function that is called every message received, acquire received data and save into the local variables
void DataRecvCb(const uint8_t *macAddr, const uint8_t *receiving, int size) {
  memcpy(&message, receiving, sizeof(message)); // memory copy the receiving data into the message structure to decode
  if (message.sensorNumber == 1) {
    // malfunction detection
    timestamp1 = millis();
    Serial.print("timestamp1 millis: ");
    Serial.println(timestamp1);
    sensor1OnOFF = 1;

    Serial.println("Message received from Humidity Sensor1");
    humidity1 = message.humidity + ho1;
    // Serial.print("Sensor #1 Humidity: ");
    // Serial.print(humidity1);
    // Serial.println("% rH");
    if (message.temperature < 25) {
      to1 = 0;
    }
    else if (25 <= message.temperature and message.temperature < 43) {
      to1 = -2 * (int((message.temperature + 1) / 2) - 12);
    }
    else {
      to1 = -20;
    }
    temperature1 = message.temperature + to1;
    // Serial.print("Sensor #1 Temperature: ");
    // Serial.print(temperature1);
    // Serial.println("'C");
    // Serial.println();
  }
  else if (message.sensorNumber == 2) {
    // malfunction detection
    timestamp2 = millis();
    Serial.print("timestamp2 millis: ");
    Serial.println(timestamp2);
    sensor2OnOFF = 1;

    Serial.println("Message received from Humidity Sensor2");
    humidity2 = message.humidity + ho1;
    // Serial.print("Sensor #2 Humidity: ");
    // Serial.print(humidity2);
    // Serial.println("% rH");
    if (message.temperature < 25) {
      to2 = 0;
    }
    else if (25 <= message.temperature and message.temperature < 43) {
      to2 = -2 * (int((message.temperature + 1) / 2) - 12);
    }
    else {
      to2 = -20;
    }
    temperature2 = message.temperature + to2;
    // Serial.print("Sensor #2 Temperature: ");
    // Serial.print(temperature2);
    // Serial.println("'C");
    // Serial.println();
  }
  else if (message.sensorNumber == 3) {
    // malfunction detection
    timestamp3 = millis();
    Serial.print("timestamp3 millis: ");
    Serial.println(timestamp3);
    sensor3OnOFF = 1;

    Serial.println("Message received from Humidity Sensor3");
    humidity3 = message.humidity + ho1;
    // Serial.print("Sensor #3 Humidity: ");
    // Serial.print(humidity3);
    // Serial.println("% rH");
    if (message.temperature < 25) {
      to3 = 0;
    }
    else if (25 <= message.temperature and message.temperature < 43) {
      to3 = -2 * (int((message.temperature + 1) / 2) - 12);
    }
    else {
      to3 = -20;
    }
    temperature3 = message.temperature + to3;
    // Serial.print("Sensor #3 Temperature: ");
    // Serial.print(temperature3);
    // Serial.println("'C");
    // Serial.println();
  }
}

void ManualMode() {
  autoMode = 0;
}
void AutoMode() {
  autoMode = 1;
  manualFanState = 0;
  manualValveState = 0;
}

void fanManualOn() {
  manualFanState = 1;
}
void fanManualOff() {
  manualFanState = 0;
}

void valveManualOn() {
  manualValveState = 1;
}
void valveManualOff() {
  manualValveState = 0;
}

void setup() {
  // Serial Monitor Setup (with transmit baud rate 115200)
  Serial.begin(115200);

  // Use pinMode to configure GPIO as Input/Output
  pinMode(fanPin, OUTPUT);
  pinMode(valvePin, OUTPUT);

  pinMode(bottomWaterLevelPin, INPUT);
  pinMode(topWaterLevelPin, INPUT);

  // WiFi Station Mode Setup, Humidity Sensor Subsystem's ESP32s will have access to the Humidifier Subsystem's ESP32
  WiFi.mode(WIFI_MODE_STA);

  // ESP-NOW protocol initialization
  if (esp_now_init() != ESP_OK) {
    Serial.println("ESP-NOW Initialization Failed");
    return;
  }
  
  // Begin WiFi
  WiFi.softAP(ssid, password);

  // Print the ssid and IP address
  Serial.println("");
  Serial.print("Succesful connection to: ");
  Serial.println(ssid);
  Serial.print("IP address: ");
  Serial.println(WiFi.softAPIP());

  // Use mDNS so that user can access the Web through .local instead of IP Address directly
  if (MDNS.begin("YourSmartHumidifier")) { // Give name that goes before .local
    Serial.println("MDNS responder started successfully");
  }
  
  server.begin();
  Serial.println("HTTP server started");

  // root directory
  server.on("/", HTTP_GET, [](AsyncWebServerRequest *request){
    request->send(200, "text/html", "<html><head><meta http-equiv=\"refresh\" content=\"2\"></head><body> Current Operation Mode (Auto->1, Manual->0): " + String(autoMode)
    + "<br><br>Current Avg. Humidity: " + String(avgHumidity) + "% rH, "
    + "Current Avg. Temperature: " + String(avgTemperature) + "'C" + "<br>" + "<br>"
    + "Sensor#1 Humidity: " + String(humidity1) + "% rH, Temperature: " + String(temperature1) + "'C" + "<br>"
    + "Sensor#2 Humidity: " + String(humidity2) + "% rH, Temperature: " + String(temperature2) + "'C" + "<br>"
    + "Sensor#3 Humidity: " + String(humidity3) + "% rH, Temperature: " + String(temperature3) + "'C" + "<br>"
    + "<br><a href=\"/auto\">Click to set AUTO Mode</a>"
    + "<br><br><a href=\"/manual\">Click to set MANUAL Mode</a>"
    + "<br><br><a href=\"/fanmanualon\">Fan ON (Manual Mode Only)</a>&nbsp;&nbsp;&nbsp;&nbsp;<a href=\"/fanmanualoff\">Fan OFF (Manual Mode Only)</a>"
    + "<br><br><a href=\"/valvemanualon\">Valve ON (Manual Mode Only)</a>&nbsp;&nbsp;&nbsp;&nbsp;<a href=\"/valvemanualoff\">Valve OFF (Manual Mode Only)</a>"
    + "<br><br><a href=\"/\">Click to manually refresh the Page</a>"
    + "</head></html>");
  });

  server.on("/manual", HTTP_GET, [](AsyncWebServerRequest *request){
    ManualMode();
    request->redirect("/");
  });
  server.on("/auto", HTTP_GET, [](AsyncWebServerRequest *request){
    AutoMode();
    request->redirect("/");
  });

  server.on("/fanmanualon", HTTP_GET, [](AsyncWebServerRequest *request){
    fanManualOn();
    request->redirect("/");
  });
  server.on("/fanmanualoff", HTTP_GET, [](AsyncWebServerRequest *request){
    fanManualOff();
    request->redirect("/");
  });

  server.on("/valvemanualon", HTTP_GET, [](AsyncWebServerRequest *request){
    valveManualOn();
    request->redirect("/");
  });
  server.on("/valvemanualoff", HTTP_GET, [](AsyncWebServerRequest *request){
    valveManualOff();
    request->redirect("/");
  });

  // Acquiring MAC Address of the ESP32 so that other ESP32s can use it to access (will be only used when setting up the system)
  // Serial.print("MAC Address: ");
  // Serial.println(WiFi.macAddress()); // eg. MAC Address: 34:85:18:52:0B:50
  
  // Callback registration
  esp_now_register_recv_cb(DataRecvCb);
}

void loop() {
  // Turn the temperature and humidity data back to 0 if sensor is unplugged
  unsigned long loopMillis = millis();
  Serial.print("loop millis: ");
  Serial.println(loopMillis);
  if ((loopMillis - timestamp1) > 15000) {
    humidity1 = 0;
    temperature1 = 0;
    sensor1OnOFF = 0;
  }
  if ((loopMillis - timestamp2) > 15000) {
    humidity2 = 0;
    temperature2 = 0;
    sensor2OnOFF = 0;
  }
  if ((loopMillis - timestamp3) > 15000) {
    humidity3 = 0;
    temperature3 = 0;
    sensor3OnOFF = 0;
  }

  // Manual Override
  if (autoMode == 0) {
    // Water level sensor in HIGH in air, LOW in water contact
    int bottomWaterLevelState = digitalRead(bottomWaterLevelPin);
    int topWaterLevelState = digitalRead(topWaterLevelPin);

    int curNumSensors = sensor1OnOFF + sensor2OnOFF + sensor3OnOFF;
    // Averaging the temperature and humidity data (from three sensors)
    if (curNumSensors == 0) {
      avgTemperature = 0;
      avgHumidity = 0;
    }
    else {
      avgTemperature = (temperature1 + temperature2 + temperature3) / curNumSensors;
      avgHumidity = (humidity1 + humidity2 + humidity3) / curNumSensors;
    }

    // Output the corresponding GPIO to control the relays (manual override)
    digitalWrite(fanPin, manualFanState);
    digitalWrite(valvePin, manualValveState);
    
    delay(1000);
  }
  else {
  // Water level sensor in HIGH in air, LOW in water contact
  int bottomWaterLevelState = digitalRead(bottomWaterLevelPin);
  int topWaterLevelState = digitalRead(topWaterLevelPin);

  // Both water level sensors have air in contact (no water)
  if ((bottomWaterLevelState == HIGH) && (topWaterLevelState == HIGH)) {
    valveState = HIGH; // set to HIGH in order to open the valve
    fillToEnd = 0;
  }
  // Other three possible cases (all in which the valve has to be closed/or remain closed):
  // 1. Both water level sensors have water in contact
  // 2. Only top water level sensor have air in contact (no water)
  // 3. Only bottom water level sensor have air in contact (no water)
  else {
    if (fillToEnd == 0){
      if ((bottomWaterLevelState == LOW) && (topWaterLevelState == LOW)){
        fillToEnd = 1;
        valveState = LOW;
      }
    }
    else if (fillToEnd == 1) {
      valveState = LOW; // set to LOW in order to close the valve
    }
  }

  int curNumSensors = sensor1OnOFF + sensor2OnOFF + sensor3OnOFF;
  // Averaging the temperature and humidity data (from three sensors)
  if (curNumSensors == 0) {
    avgTemperature = 0;
    avgHumidity = 0;
  }
  else {
    avgTemperature = (temperature1 + temperature2 + temperature3) / curNumSensors;
    avgHumidity = (humidity1 + humidity2 + humidity3) / curNumSensors;
  }

  // Target humidity range min-max
  float minHumidity;
  float maxHumidity;

  // Compare the average temperature obtained from the sensors (assumed to be indoor)
  // Considering the average indoor temperature (range where human feels the most comfort) is 20~22'C 
  // Higher the temperature, air can hold more moisture without having issues such as mold
  // Thus, if the average temperature is above 22'C, adjust the min-max Humidity target so that instead of 30-50% rH boundary, humidifier now targets 40-50 rH boundary
  if (avgTemperature > 22) {
    minHumidity = 42.5;
    maxHumidity = 50;
  }
  // Else if the average temperature is below 20'C, adjust the min-max Humidity target so that instead of 30-50% rH boundary, humidifier now targets 30-40 rH boundary
  else if (avgTemperature < 20) {
    minHumidity = 42.5;
    maxHumidity = 40;
  }
  // If the average temperature is in between 20~22'C, target base 30-50 rH boundary
  else {
    minHumidity = 35;
    maxHumidity = 50;
  }

  if (avgHumidity > maxHumidity) {
    fanState = LOW; // set to LOW in order to stop the fan
  }
  else if (avgHumidity < minHumidity) {
    fanState = HIGH; // set to HIGH in order to run the fan
  }
  // Average Humidity is in between the min-max target range
  else {
    if (fanState == HIGH) {
      fanState = HIGH; // keep running the fan until humidity goes above the max target
    }
    else if (fanState == LOW) {
      fanState = LOW; // kept the fan off until humidity goes below the min target
    }
  }

  // Print current average Temperature and Humidity for debugging purpose
  Serial.print("Current Avg. Temperature: ");
  Serial.print(avgTemperature);
  Serial.print(" 'C (Sensor#1: ");
  Serial.print(temperature1);
  Serial.print(", Sensor#2: ");
  Serial.print(temperature2);
  Serial.print(", Sensor#3: ");
  Serial.print(temperature3);
  Serial.println(")");

  Serial.print("Current Avg. Humidity: ");
  Serial.print(avgHumidity);
  Serial.print("% rH  (Sensor#1: ");
  Serial.print(humidity1);
  Serial.print(", Sensor#2: ");
  Serial.print(humidity2);
  Serial.print(", Sensor#3: ");
  Serial.print(humidity3);
  Serial.println(")");
  Serial.println("");

  // Output the corresponding GPIO to control the relays
  digitalWrite(fanPin, fanState);
  digitalWrite(valvePin, valveState);
  
  delay(1000);
  }
}
